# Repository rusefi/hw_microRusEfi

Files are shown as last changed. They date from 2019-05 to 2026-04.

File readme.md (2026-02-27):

# microRusEFI

microRusEFI is a small & cheap engine management system board designed for fully sequential 1, 2, 3 and 4 cylinder applications.

6 and 8 cylinders are possible with some limitations. 5 cylinder application not recommended. You would need at least two microRusEFI units to run a v12.

microRusEFI uses a waterproof connector and its aluminum enclosure could be sealed. 

microRusEFI hardware runs [rusEFI firmware](https://github.com/rusefi/rusefi).

microRusEfi supports dual Hall shaft position sensor input or 1xHall + 1xVR shaft position sensor input
(A few resistors must be replaced on the PCB in order to switch from one setup to another)

Open source design available in this repository,
or available as a kit or completely assembled from http://shop.rusefi.com/

# Capabilities
* Primary VR or Hall input (configurable with few resistor changes)
* Secondary Hall input
* x4 analog thermistor (temperature) inputs
* x10 analog voltage inputs (0-5v)
* x4 high-Z injector outputs
* x2 high-current low side outputs for IAC/VVT/other solenoids
* Dedicated main relay control output 
* x4 low-current low side outputs for relays or warning lights 
* x4 5v logic-level ignition outputs
* x2 5v/12v configurable logic level outputs (requires resistor changes)
* Electronic throttle body (drive by wire)
* CAN connectivity on the plug
* USB connectivity on the plug 
* SPI and TTL available on PCB
* stepper IAC support (beta testing please report your results!)

# Documentation

[Connector Pinout](https://github.com/rusefi/rusefi/wiki/Hardware-microRusEfi-wiring)

[microRusEFI documentation wiki](https://github.com/rusefi/rusefi/wiki/Hardware-microRusEfi)

[microRusEFI kit instructions](https://github.com/rusefi/rusefi/wiki/Hardware-microRusEfi-kit-instructions)

[microRusEFI forum thread](https://rusefi.com/forum/viewtopic.php?f=4&t=1538)

[asembled images & assembly files](gerbers)

[ChangeLog](releaseNotes.md)

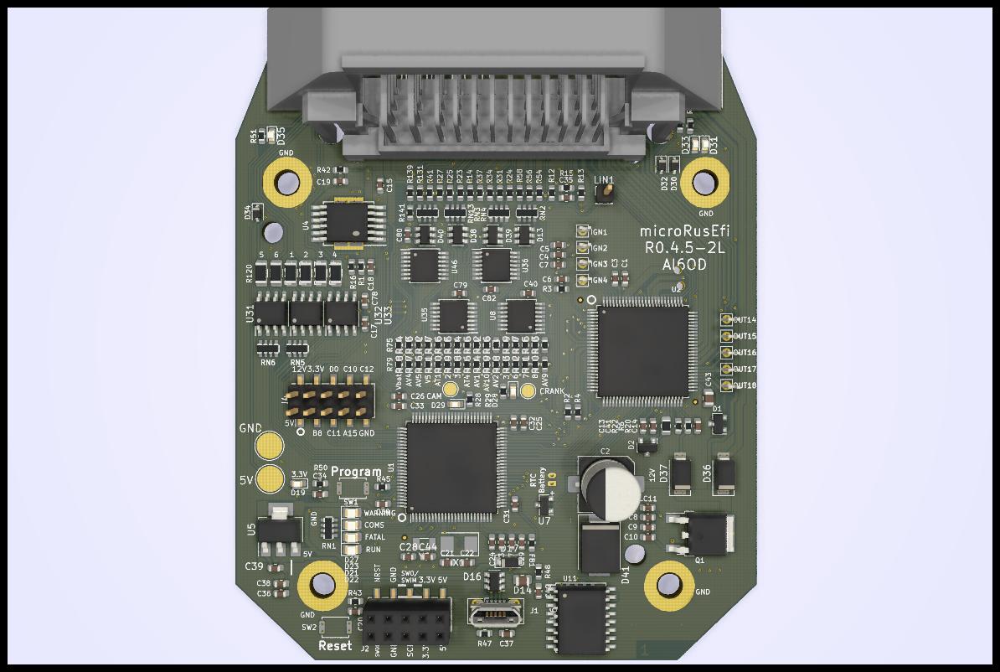
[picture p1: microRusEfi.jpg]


If you download complete repo do not forget to download libraries. If you git clone be sure to also

`git submodule update --init`

Do you like what you see here? Maybe https://www.patreon.com/rusefi

## BOM highlights

stm32f767

[TLE8888-2QK](https://www.infineon.com/dgdl/Infineon-Infineon-TLE8888QK-DS-v01_02-EN.pdf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)

[Final assembly BOM notes](https://github.com/rusefi/hw_microRusEfi/blob/master/gerbers/rusEFI-Micro_R0.4.x-not-pre-assembled.md)

[48 pin connector](https://github.com/rusefi/rusefi/wiki/Hardware-microRusEfi-connectors)

[iBom 0.6.0](https://rusefi.com/docs/ibom/micro_rusEFI_R0.6.0.html)

## Adapter Boards

microRusEFI could be used as a brain for Plug&Play vehicle specific adapter boards

1) https://github.com/rusefi/hw_55_te For Yanvar/Micas case

## Case

Model CKKB48-1-A (Weigh 200g)

[Case 3D Model](https://cad.onshape.com/documents/cce953328a88b521d5673ac5/w/e2d3a78cfb432482f5aac9ea/e/2eb39a31ab72390c6384f68c)

Cover bolts M3.5x0.6

PCB bolts M3 0.5mm thread, L=7.5mm https://www.mcmaster.com/94209A619/

## Gerbers

[Gerbers and pictures of fabricated boards](gerbers)

## ST-LINK

Unfortunately eBay has a few different version of cheap ST-LINK V2 devices with different pinout. Here is the pinout rusEfi is compatible with:

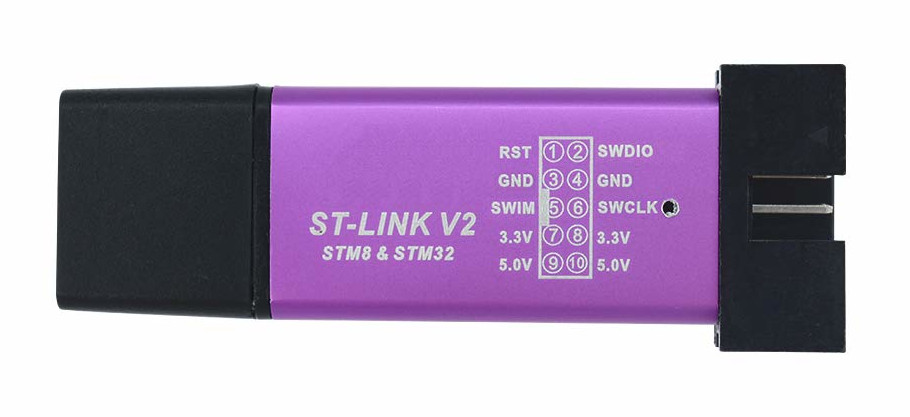
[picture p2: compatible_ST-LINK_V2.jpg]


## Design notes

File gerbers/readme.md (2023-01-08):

All microRusEFI boards are 81x94mm

Case outside dimensions are about 10x11cm (not including mounting tabs)

A panel of 9 boards is 267*300mm

rusEFI text fixture is 130x128

[Connector Pinout](https://github.com/rusefi/rusefi/wiki/Hardware_microRusEFI_wiring)

[microRusEFI documentation wiki](https://github.com/rusefi/rusefi/wiki/Hardware_microRusEFI)

[microRusEFI kit instructions](https://github.com/rusefi/rusefi/wiki/Hardware_microRusEFI_kit_instructions)

R0.1, R0.2, R03 - 4 layers, no assembly files

R0.4.5 - 2 layers, use microRusEfi-bom.csv and microRusEfi-cpl.csv files for top side assembly.

# R0.5.0




# R0.4.8



# R0.4.5

Pre-assembled by jlcpcb



More-assembled, based on pre-assembled by jlcpcb. 




##R0.3 Hall Mode Mazda Miata 2003


# R0.1


##R0.1 Hall Mode


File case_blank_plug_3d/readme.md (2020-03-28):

3D printed plug if one wants to use default aluminum case but not the default connector.

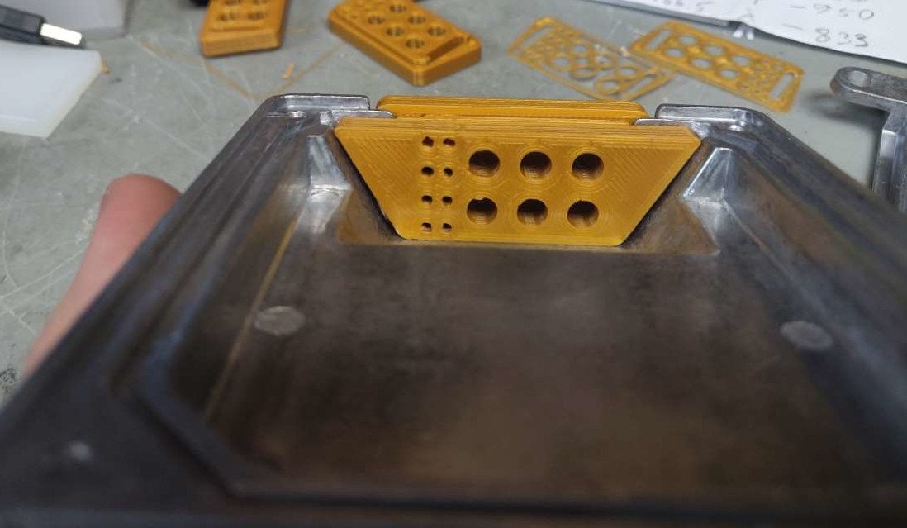
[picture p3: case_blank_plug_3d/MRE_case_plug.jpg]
i


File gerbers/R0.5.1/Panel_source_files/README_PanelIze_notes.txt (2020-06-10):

Steps for panelizing are as follows
-- Open C:\Program Files\KiCad\bin\pcbnew.exe or similar directly. This will allow the below step. 
-- Open Panel_MRE_R0.5.1_300x300_2layer_step0.kicad_pcb
-- Append MRE to this board, and place in the top left location of the layout. 
-- Copy MRE and Paste it 9 times. 
-- Make sure you have the green ECO1 lines for where the mousebits should be
-- SaveAs Panel_MRE_R0.5.1_300x300_2layer_step1.kicad_pcb
-- modify and run MouseBitePanel.bat
-- Open output.Panel_R0.5.1_300x300_2layer_step1.kicad_pcb
-- Delete extra mouse bits, add Vcut lines to ECO2 layer. 
-- plot gerbers the normal way, do NOT re-flood copper planes. 
-- geneate position file the normal way, save as "Panel_MRE_R0.5.1_300x300_1-to-9.csv"
-- use script to create the JLC CPL the normal way
-- Delete extra PCB's, then re-create positon file, and again "Panel_MRE_R0.5.1_300x300_1&5-populated_2,3,4,6,7,8,9-empty.csv"
-- use script to create the JLC CPL the normal way
-- SaveAS output.Panel_R0.5.1_300x300_2layer_step2.kicad_pcb
-- Move applicable files up one folder. 

The below notes are based off of EEVblog video found here https://www.youtube.com/watch?v=VXE_dh38HjU
-- 18:20 Check the PCB MFG house for max panel size, 
JLC is 300mm by 300mm for 1.6mm thick. https://support.jlcpcb.com/article/49-pcb-panelization
-- 18:30 Check the assembly house max panel size. 
JLC, I'll assume the 300mm by 300mm like above. Note MRE is 1 design 9 times. 
-- 19:37 tooling strips top an bottom or side to side should typicaly be about 10mm mininium. Check assembly house, but 10mm is typical.
JLC is 4mm tooling strip. Then here notes 3mm is min, they default to 5mm.  
-- 20:10 check tooling holes, typically 4mm diameter 4 holes, one in each corner. Also should have fiducials. 
JLC will add these if they are not provided. 
-- 22:00 Add bad board marker in the dead area's of the panel, so MFG can indicate a bad boarfd. 
-- 22:15 consider adding an impeadance test strips
-- 22:40 consider adding a test stack, AKA copper to the edge, so you can inspect the stackup of a 4 layer and above boards. 
-- 24:40 consider adding test points on the dead areas, handy for JTAG multi board programming. 
-- 42:00 create layer with v groove lines to show where to v groove. 
JLC needs 2mm min for internal cutouts. https://jlcpcb.com/capabilities/Capabilities
JLC V cut is 0.8mm wide, copper set back from v cut should be 0.4mm or more. 
-- 43:25 make sure your solder mask it around 4 mil or larger between pads, to prevent bridging. 
JLC allows 0.2mm (8 mils)
JLC mousebit hole diameter 0.8mm with 0.2 materail remaining. 
-- 48:35 suggested to provide a sample of a completed board, so the assembler knows what to do. At least provide pictures. 

As of 2020, this is one of the better tools for KICAD
https://hackaday.com/2020/04/25/kicad-panelization-made-easy/

Also this 2019 article. 
https://hackaday.com/2019/03/12/panelizing-boards-in-kicad/
https://gitlab.com/dren.dk/kicad-util

Basically open PCBNew manually and append the boards until you have them spaced, then add mouse bits, etc to get the panel made.

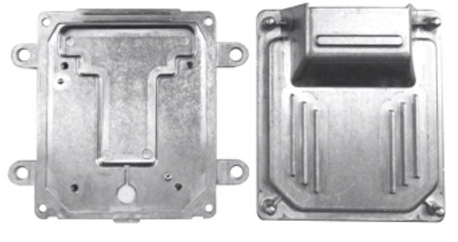
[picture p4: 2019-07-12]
CKKB48-1-A_both_sides.jpg

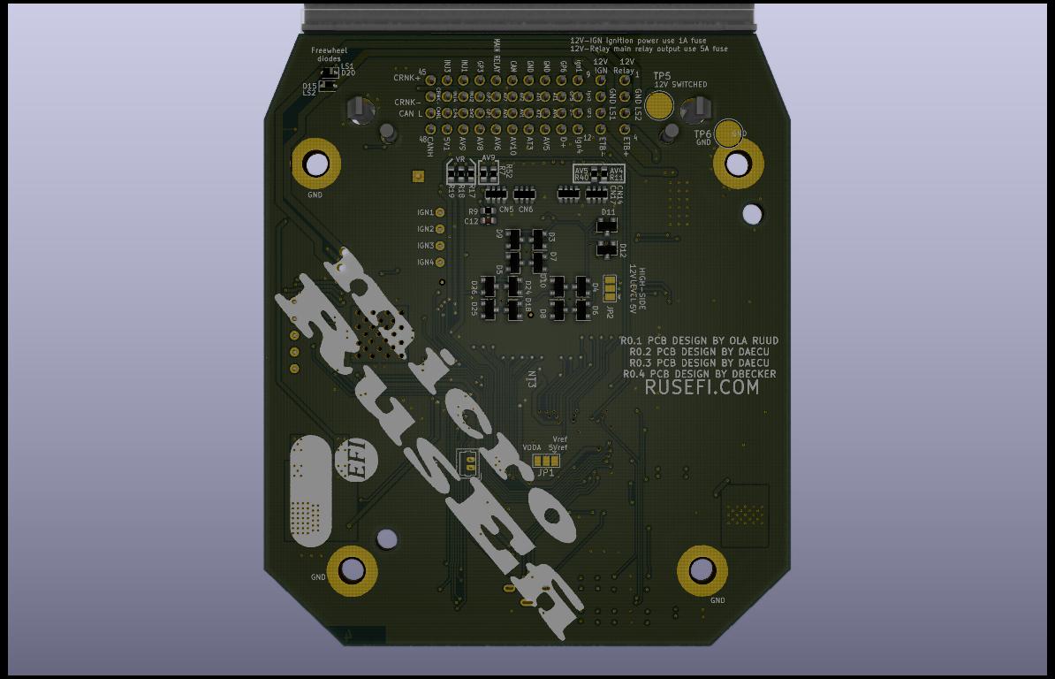
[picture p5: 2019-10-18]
micro_rusEFI_back.jpg

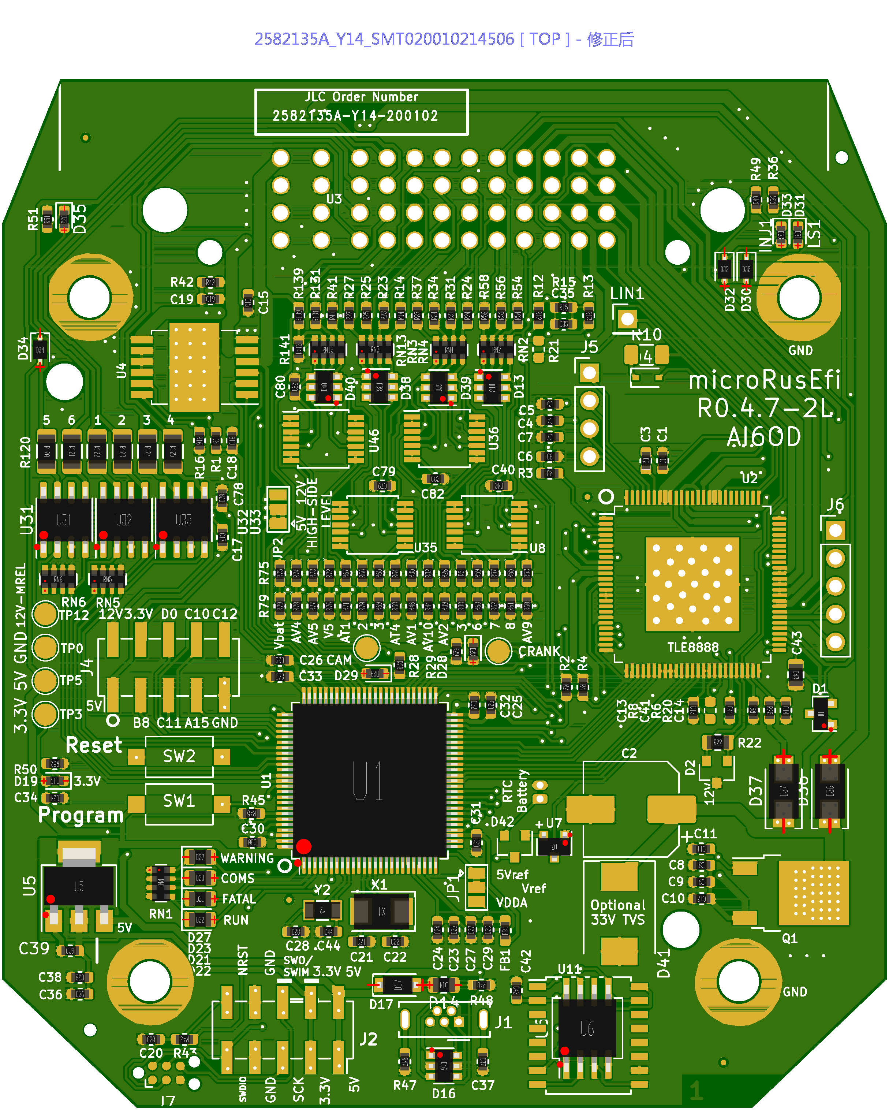
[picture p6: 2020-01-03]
gerbers/rusEFI-Micro_R0.4.7-polarity.png

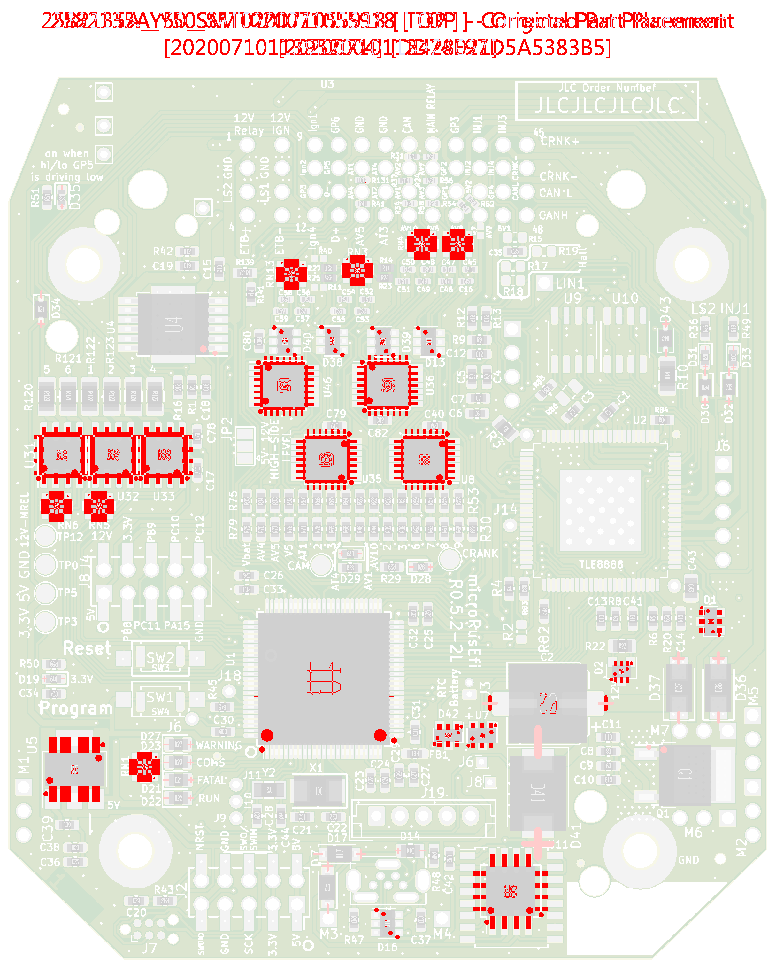
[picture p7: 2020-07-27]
gerbers/R0.5.2/placement_0.5.2.corrections.png

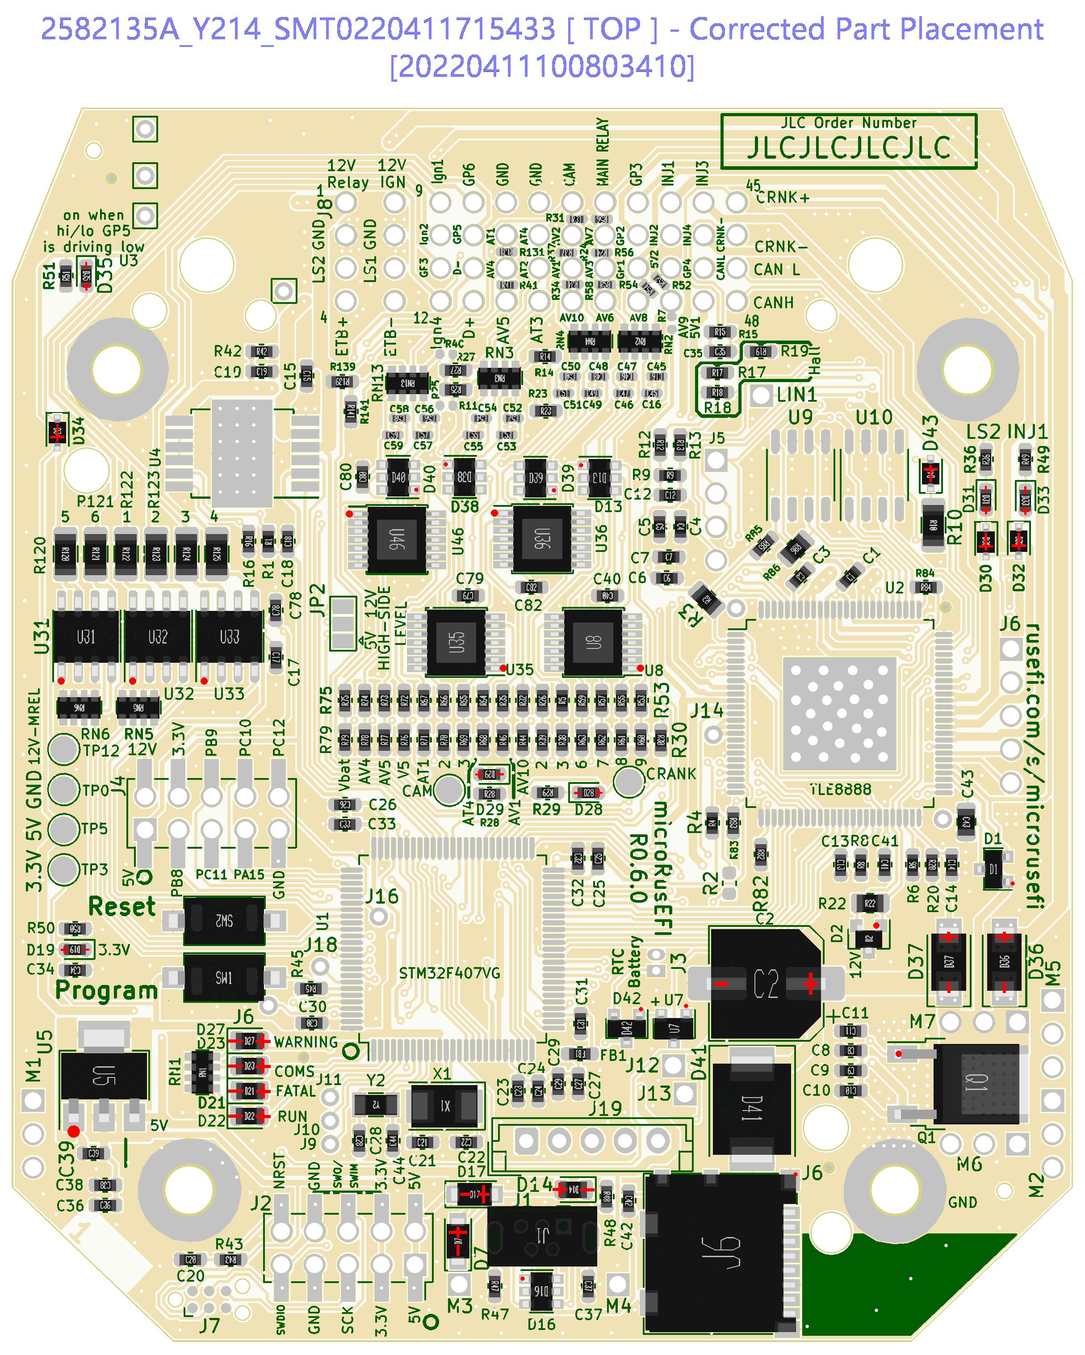
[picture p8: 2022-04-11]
gerbers/R0.6.0/Produce_DanZhi.SMT_Snapshot.Top.2582135A_Y214.SMT0220411715433.png

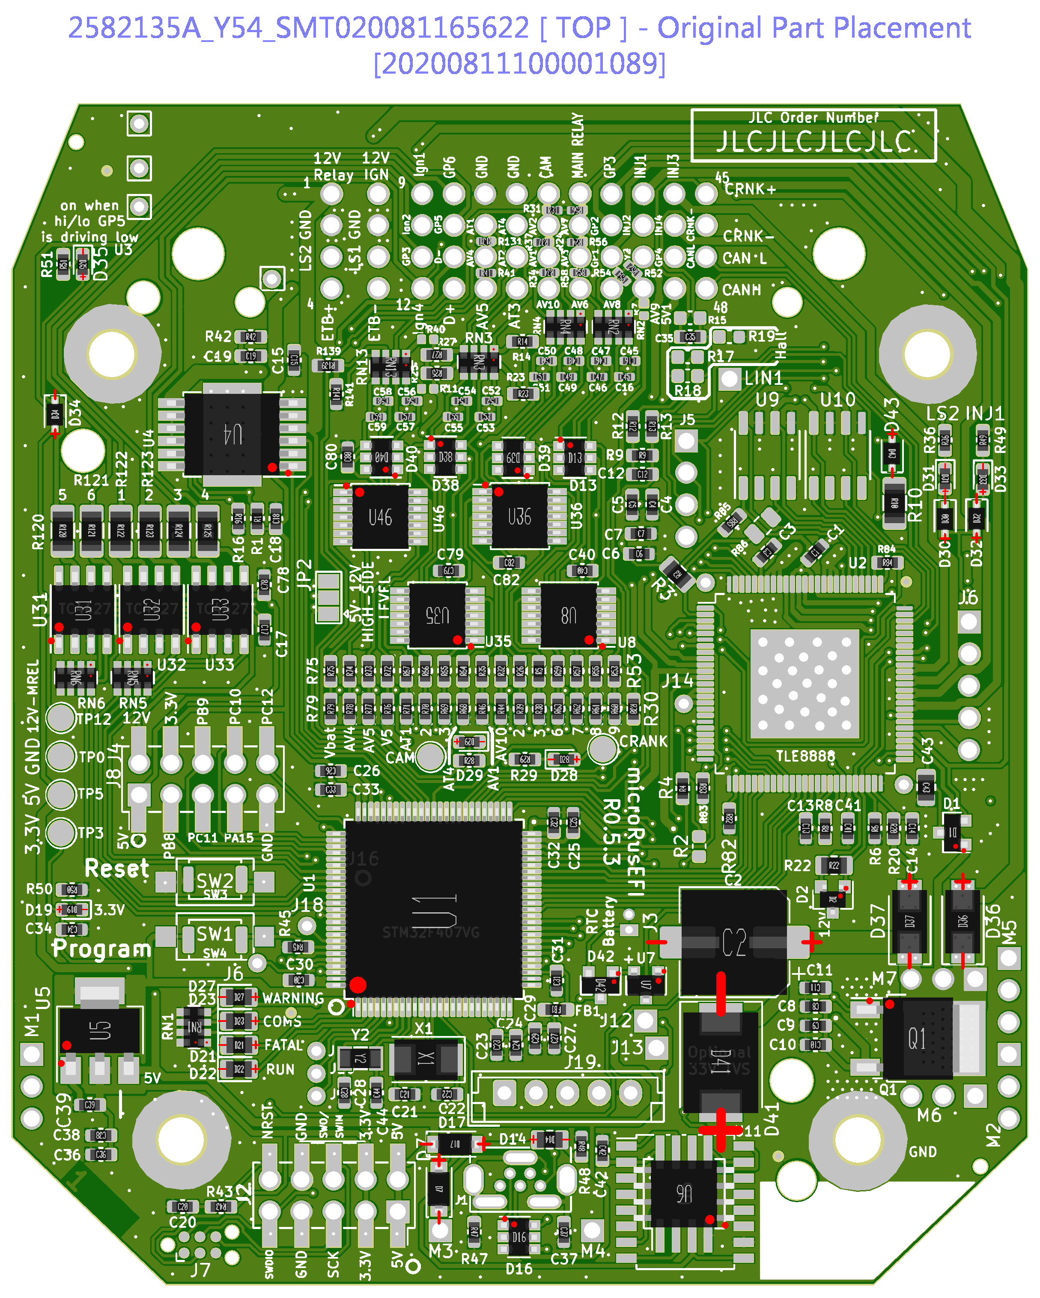
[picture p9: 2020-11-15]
gerbers/R0.5.3/placement_0.5.3.original.png

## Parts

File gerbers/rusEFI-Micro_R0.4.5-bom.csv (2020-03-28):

Comment | Designator | Footprint | LCSC Part #
100UF 50V Polarized capacitor | C2 | CP_Elec_8x10.5
4.7nF Unpolarized capacitor | C3,C11 | C_0603_1608Metric | C53987
470nF Unpolarized capacitor | C4,C5 | C_0603_1608Metric | C1623
10uF Unpolarized capacitor | C7,C9,C8 | C_0603_1608Metric | C19702
1nF Unpolarized capacitor | C12,C35 | C_0603_1608Metric | C1588
10nF Unpolarized capacitor | C19,C79,C80,C82,C40,C29,C20 | C_0603_1608Metric | C57112
18pF Unpolarized capacitor | C21,C22 | C_0603_1608Metric | C1647
2.2uF Unpolarized capacitor | C25,C26,C41 | C_0603_1608Metric | C23630
1uF Unpolarized capacitor | C27,C23,C36 | C_0603_1608Metric | C15849
6.8pF Unpolarized capacitor | C28,C44 | C_0603_1608Metric | C1679
22uF Unpolarized capacitor | C39 | C_0603_1608Metric | C59461
22uF 25V Unpolarized capacitor | C43 | C_0805_2012Metric | C45783
100nF Unpolarized capacitor | C78,C17,C15,C18,C38,C34,C33,C32,C31,C30,C37,C24,C42,C10,C1,C6,C13,C14 | C_0603_1608Metric | C14663
10nF 4 resistor network, parallel topology, DIP package | CN17,CN6,CN5,CN14 | R_Array_Convex_4x0603
BAV70 Dual 100V 215mA high-speed switching diodes, common cathode, SOT-23 | D1 | SOT-23 | C68978
PESD1CAN-UX | D2 | SOT-23
LED-GREEN Light emitting diode | D14 | C_0805_2012Metric | C2297
DNP Schottky diode | D15,D20 | D_SOD-323
B5819W Schottky diode | D17 | D_SOD-123 | C8598
LED-RED Light emitting diode | D21 | LED_0805_2012Metric | C84256
LED-GREEN Light emitting diode | D22 | LED_0805_2012Metric | C2297
LED-BLUE Light emitting diode | D23 | LED_0805_2012Metric | C2293
LED-YELLOW Light emitting diode | D27 | LED_0805_2012Metric | C2296
LED-RED Light emitting diode | D28,D31,D33,D35,D29,D19 | LED_0603_1608Metric | C2286
1N4148WS Diode | D32,D34,D30 | D_SOD-323 | C2128
SS54 40V 3A Schottky Barrier Rectifier Diode, SMC | D36,D37 | D_SMA | C22452
SRV05-4 Transient voltage suppressor designed to protect high speed data lines from ESD, EFT, and lightning | D38,D13,D40,D39,D16 | SOT-23-6 | C85364
SM15T33C Bidirectional transient-voltage-suppression diode | D41 | D_SMC
FILTER Ferrite bead | FB1 | R_0603_1608Metric_Pad1.05x0.95mm_HandSolder | C1034
Fiducial Fiducial Marker | FID5,FID6,FID1,FID2,FID3,FID4 | Fiducial_0.5mm_Mask1mm
IGNOUT test point | IGN3,IGN4,IGN2,IGN1 | Pin_D0.7mm_L6.5mm_W1.8mm_FlatFork
USB_B_Micro USB Micro Type B connector | J1 | USB_Micro-B_Molex-105133-0031
Conn_02x05_Odd_Even Generic connector, double row, 02x05, odd/even pin numbering scheme (row 1 odd numbers, row 2 even numbers), script generated (kicad-library-utils/schlib/autogen/connector/) | J2 | PinSocket_2x05_P2.54mm_Vertical_SMD
Conn_01x02 Generic connector, single row, 01x02, script generated (kicad-library-utils/schlib/autogen/connector/) | J3 | Molex_PicoBlade_53047-0210_1x02_P1.25mm_Vertical
Conn_02x05_Counter_Clockwise Generic connector, double row, 02x05, odd/even pin numbering scheme (row 1 odd numbers, row 2 even numbers), script generated (kicad-library-utils/schlib/autogen/connector/) | J4 | PinHeader_2x05_P2.54mm_Vertical_SMD
VRef Source 5Vsense VDDA 3-pole Solder Jumper, pins 1+2 closed/bridged | JP1 | SolderJumper-3_P1.3mm_Bridged12_Pad1.0x1.5mm
High side voltage 5V 12V 3-pole Solder Jumper, pins 1+2 closed/bridged | JP2 | SolderJumper-3_P1.3mm_Bridged2Bar12_Pad1.0x1.5mm
LIN test point | LIN1 | TestPoint_Pad_1.0x1.0mm
DNP Open Hardware logo, small | LOGO1 | LogoMRE
DNP | LOGO2 | LOGO
Net-Tie_2 Net tie, 2 pins | NT1 | Net-Tie_2_8.5mil
Net-Tie_2 Net tie, 2 pins | NT2 | Net-Tie_2_8.5mil
Analog Ground Net Tie Net tie, 2 pins | NT3 | NetTie-2_SMD_Pad0.5mm
OUT15 test point | OUT15 | Pin_D0.7mm_L6.5mm_W1.8mm_FlatFork
OUT16 test point | OUT16 | Pin_D0.7mm_L6.5mm_W1.8mm_FlatFork
OUT17 test point | OUT17 | Pin_D0.7mm_L6.5mm_W1.8mm_FlatFork
OUT18 test point | OUT18 | Pin_D0.7mm_L6.5mm_W1.8mm_FlatFork
IPD30N06S2L-23 30A Id, 50V Vds, N-Channel Power MOSFET, TO-220 | Q1 | TO-252-2
10K Resistor | R1,R16,R141,R46,R44,R39,R38,R60,R61,R62,R63,R68,R69,R70,R71,R76,R77,R78,R79,R43,R45,R12,R13,R3,R4,R2,R6 | R_0603_1608Metric | C25804
DNP Resistor | R11,R40,R7,R17,R19,R18 | R_0603_1608Metric
2.7k Resistor | R14,R23,R25,R27,R20 | R_0603_1608Metric | C13167
15k Resistor | R15 | R_0603_1608Metric | C22809
120 Resistor | R22 | R_0805_2012Metric | C17437
2.2k Resistor | R28 | R_0603_1608Metric | C4190
1k Resistor | R29,R49,R36,R51,R48,R50 | R_0603_1608Metric | C21190
6.8K Resistor | R35,R32,R26,R5,R55,R57,R59,R53,R64,R65,R66,R67,R73,R72,R74,R75 | R_0603_1608Metric | C23212
4.7K Resistor | R42,R9 | R_0603_1608Metric | C23162
100K Resistor | R47 | R_0603_1608Metric | C25803
100 Resistor | R120,R121,R122,R124,R125,R123 | R_1206_3216Metric | C17901
470K Resistor | R131,R41,R34,R31,R24,R37,R56,R54,R52,R58 | R_0603_1608Metric | C23178
39k Resistor | R139 | R_0603_1608Metric | C23153
1k 4 resistor network, parallel topology, DIP package | RN1 | R_Array_Convex_4x0603 | C20197
10k 4 resistor network, parallel topology, DIP package | RN5,RN6,RN3,RN13,RN4,RN2 | R_Array_Convex_4x0603 | C29718
SW_Push Push button switch, generic, two pins | SW1,SW2 | SW_Push_SPST_NO_Alps_SKRK
5V test point | TP1,TP5 | TestPoint_Pad_D4.0mm
GND test point | TP2,TP6 | TestPoint_Pad_D4.0mm
TP test point | TP4,TP3 | TestPoint_Pad_D2.0mm
STM32F407VGT6 ARM Cortex-M4 MCU, 1024KB flash, 128KB RAM, 168MHz, 1.8-3.6V, 82 GPIO, LQFP-100 | U1 | LQFP-100_14x14mm_P0.5mm | C12345
TLE8888QK | U2 | LQFP-100_14x14mm_P0.5mm_THERMAL
Molex_48_pin | U3 | Molex_48
TLE9201SG | U4 | Infineon_PG-DSO-12-11
LM1117-3.3 800mA Low-Dropout Linear Regulator, 3.3V fixed output, TO-220/TO-252/TO-263/SOT-223 | U5 | SOT-223-3_TabPin2 | C6186
W25QxxJVS 32Mb Serial Flash Memory, Standard/Dual/Quad SPI, SOIC-8 | U6 | SO-8_5.3x6.2mm_P1.27mm-150+208 | C97521
XC6206 3.3V Low Quiescent Current LDO Regulator, 3.3V, 250mA, Vin<=16V, SOT-23 | U7 | SOT-23 | C5446
IS25LP256D-xM 256-Mbit, 1.8V SPI Serial Flash Memory with Dual-I/O and Quad-I/O Support, SOIC-16 | U11 | SOIC-16W_7.5x10.3mm_P1.27mm
MIC4427 Dual 1.5A-Peak Low-Side MOSFET Driver, DIP-8/SOIC-8/MSOP-8 | U31,U33,U32 | SOIC-8_3.9x4.9mm_P1.27mm | C144205
MCP6004 1MHz, Low-Power Op Amp, DIP-14/SOIC-14/TSSOP-14 | U35,U36,U46,U8 | TSSOP-14_4.4x5mm_P0.65mm | C50282
8MHz Two pin crystal | X1 | Crystal_SMD_5032-2Pin_5.0x3.2mm | C115962
32768 Hz Two pin crystal, small symbol | Y2 | Crystal_SMD_3215-2Pin_3.2x1.5mm | C32346

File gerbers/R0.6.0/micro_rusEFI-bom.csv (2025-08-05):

Comment | Designator | Footprint | LCSC
1nF | C12,C35 | Capacitor_SMD:C_0603_1608Metric | C1588
100nF | C16,C45,C46,C47,C48,C49,C50,C51,C52,C53,C54,C55,C56,C57,C58,C59 | Capacitor_SMD:C_0402_1005Metric | C1525
100UF 50V | C2 | Capacitor_SMD:CP_Elec_8x10.5 | C134515
18pF | C21,C22 | Capacitor_SMD:C_0603_1608Metric | C1647
1uF | C23,C27,C36 | Capacitor_SMD:C_0603_1608Metric | C15849
2.2uF | C25,C26,C41 | Capacitor_SMD:C_0603_1608Metric | C23630
6.8pF | C28,C44 | Capacitor_SMD:C_0603_1608Metric | C1679
4.7nF | C3,C11 | Capacitor_SMD:C_0603_1608Metric | C53987
22uF | C39 | Capacitor_SMD:C_0603_1608Metric | C59461
470nF | C4,C5 | Capacitor_SMD:C_0603_1608Metric | C1623
10nF | C19,C20,C29,C40,C79,C80,C82 | Capacitor_SMD:C_0603_1608Metric | C57112
100nF | C1,C6,C10,C13,C14,C15,C17,C18,C24,C30,C31,C32,C33,C34,C37,C38,C42,C78 | Capacitor_SMD:C_0603_1608Metric | C14663
22uF 25V | C43 | Capacitor_SMD:C_0805_2012Metric | C45783
10uF | C7,C8,C9 | Capacitor_SMD:C_0603_1608Metric | C19702
SRV05-4 | D13,D16,D38,D39,D40 | Package_TO_SOT_SMD:SOT-23-6 | C85364
PESD1CAN-UX | D2 | Package_TO_SOT_SMD:SOT-23 | C152727
LED-RED | D21 | LED_SMD:LED_0805_2012Metric | C84256
LED-GREEN | D14,D22 | LED_SMD:LED_0805_2012Metric | C2297
LED-BLUE | D23 | LED_SMD:LED_0805_2012Metric | C2293
LED-YELLOW | D27 | LED_SMD:LED_0805_2012Metric | C2296
LED-RED | D19,D28,D29,D31,D33,D35 | LED_SMD:LED_0603_1608Metric | C2286
SS54 | D3,D4,D5,D6,D15,D20,D36,D37 | Diode_SMD:D_SMA | C22452
1N4148WS | D30,D32,D34,D43 | Diode_SMD:D_SOD-323 | C2128
SM15T33C | D41 | Diode_SMD:D_SMC | C133707
BAV70 | D1,D42 | Package_TO_SOT_SMD:SOT-23 | C82479
B5819W | D7,D17 | Diode_SMD:D_SOD-123 | C8598
FILTER | FB1 | Resistor_SMD:R_0603_1608Metric_Pad1.05x0.95mm_HandSolder | C1034
Fiducial | FID1,FID2,FID3,FID4,FID5,FID6 | Fiducial:Fiducial_0.5mm_Mask1mm
USB_B_Mini | J1 | hellen-one-common:USB-MINI-B-VERTICAL | C13453
Conn_01x06 | J19 | Connector_JST:JST_EH_B5B-EH-A_1x05_P2.50mm_Vertical
Conn_02x05_Odd_Even | J2 | Connector_PinSocket_2.54mm:PinSocket_2x05_P2.54mm_Vertical_SMD
Conn_01x01 | J3,J5,J12,J13,J15,J17 | Connector_Pin:Pin_D0.7mm_L6.5mm_W1.8mm_FlatFork
Conn_02x05_Counter_Clockwise | J4 | Connector_PinHeader_2.54mm:PinHeader_2x05_P2.54mm_Vertical_SMD
Micro_SD_Card_Det | J6 | Connector_Card:microSD_HC_Molex_104031-0811 | C585350
TC2030 | J7 | Connector:Tag-Connect_TC2030-IDC-NL_2x03_P1.27mm_Vertical
High side voltage 5V 12V | JP2 | Jumper:SolderJumper-3_P1.3mm_Open_Pad1.0x1.5mm
DNP | LOGO1 | Symbol:OSHW-Logo2_7.3x6mm_SilkScreen
DNP | LOGO2 | rusEFI:LOGO
LOGO | LOGO3 | rusefi_lib:MRE_QR_code
Net-Tie_2 | NT1 | rusEFI_Ola:Net-Tie_2_8.5mil
Net-Tie_2 | NT2 | hw_microRusEfi-master:Net-Tie_2_8.5mil
Analog Ground Net Tie | NT3 | NetTie:NetTie-2_SMD_Pad0.5mm
IPD30N06S2L-23 | Q1 | Package_TO_SOT_SMD:TO-252-2 | C3010
1k | R10 | Resistor_SMD:R_1206_3216Metric | C4410
100 | R120,R121,R122,R123,R124,R125 | Resistor_SMD:R_1206_3216Metric | C17901
39k | R139 | Resistor_SMD:R_0603_1608Metric | C23153
2.7k | R14,R20,R23,R25,R27 | Resistor_SMD:R_0603_1608Metric | C13167
15k | R15 | Resistor_SMD:R_0603_1608Metric | DNP
DNP | R17,R18,R19 | Resistor_SMD:R_0603_1608Metric
0R DNP | R2 | Resistor_SMD:R_0603_1608Metric
0R | R8,R21,R30,R33,R80,R81,R84,R85 | Resistor_SMD:R_0603_1608Metric | C21189
120 | R22 | Resistor_SMD:R_0805_2012Metric | C17437
470K | R24,R31,R34,R37,R41,R52,R54,R56,R58,R131 | Resistor_SMD:R_0402_1005Metric | C25790
2.2k | R28,R48 | Resistor_SMD:R_0603_1608Metric | C4190
1k | R29,R36,R49,R50,R51 | Resistor_SMD:R_0603_1608Metric | C21190
10K | R3 | Resistor_SMD:R_0805_2012Metric | C17414
10K | R1,R4,R6,R12,R13,R16,R38,R39,R43,R44,R45,R46,R60,R61,R62,R63,R68,R69,R70,R71,R76,R77,R78,R79,R141 | Resistor_SMD:R_0603_1608Metric | C25804
4.7K | R9,R42,R82,R83 | Resistor_SMD:R_0603_1608Metric | C23162
100K | R47 | Resistor_SMD:R_0603_1608Metric | C25803
6.8K | R5,R26,R32,R35,R53,R55,R57,R59,R64,R65,R66,R67,R72,R73,R74,R75 | Resistor_SMD:R_0603_1608Metric | C23212
DNP | R7,R11,R40 | Resistor_SMD:R_0402_1005Metric
0R | R86 | Resistor_SMD:R_0805_2012Metric
1k | RN1 | Resistor_SMD:R_Array_Convex_4x0603 | C20197
10k | RN2,RN3,RN4,RN5,RN6,RN13 | Resistor_SMD:R_Array_Convex_4x0603 | C29718
SW_Push | SW1,SW2 | Button_Switch_SMD:SW_SPST_CK_RS282G05A3 | C398054
SW_Push | SW3,SW4 | Button_Switch_SMD:SW_Push_SPST_NO_Alps_SKRK
GND | TP0,TP3 | TestPoint:TestPoint_Pad_D2.0mm
TP | TP1,TP2,TP4 | TestPoint:TestPoint_Pad_D2.0mm
5V | TP5,TP12 | TestPoint:TestPoint_Pad_D2.0mm
STM32F427VGT6 | U1 | Package_QFP:LQFP-100_14x14mm_P0.5mm | C117815
TLE8888QK | U2 | Package_QFP:LQFP-100_14x14mm_P0.5mm_THERMAL
molex_48pin_MRE | U3 | rusefi_lib:Molex_48_MRE
MIC4427 | U31,U32,U33 | Package_SO:SOIC-8_3.9x4.9mm_P1.27mm | C144205
TLE9201SG | U4 | Package_SO:Infineon_PG-DSO-12-11 | C112633
LM1117-3.3 | U5 | Package_TO_SOT_SMD:SOT-223-3_TabPin2 | C6186
XC6206 3.3V | U7 | Package_TO_SOT_SMD:SOT-23 | C5446
MCP6004 | U8,U35,U36,U46 | Package_SO:TSSOP-14_4.4x5mm_P0.65mm | C248577
VNLD5090 | U9,U10 | Package_SO:SO-8_3.9x4.9mm_P1.27mm | C377942
8MHz 20pF | X1 | Crystal:Crystal_SMD_5032-2Pin_5.0x3.2mm | C115962
32768 Hz | Y2 | Crystal:Crystal_SMD_3215-2Pin_3.2x1.5mm | C32346

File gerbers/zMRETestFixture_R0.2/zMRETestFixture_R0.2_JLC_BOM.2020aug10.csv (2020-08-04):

Comment | Designator | Footprint | LCSC | Manufacturer | Part # | VEND | VEND# | LCSC | Digi
YEL(570NM) | D10 | rusefi_lib:SM0805_jumper |  |  |  |  |  | C84257
BLU | D12,D14,D16,D18,D20,D22 | rusefi_lib:SM0805_jumper |  |  |  |  |  | C375453
RED | D31,D33,D35,D37,D39,D41,D43,D45,D47,D25,D27,D29,D81,D83,D85,D87,D89,D91,D93,D96,D23 | rusefi_lib:SM0805_jumper |  |  |  |  |  | C84256
1N4148WS | D32,D95,D34,D36,D38,D40,D42,D44,D46,D11,D13,D15,D17,D19,D21,D5,D7,D9,D48,D26,D28,D30,D52,D82,D84,D86,D88,D90,D92,D51,D50,D49,D56,D55,D54,D53,D60,D59,D58,D57,D64,D63,D62,D61,D94,D97,D24,D3,D1 | rusefi_lib:SM0805_jumper |  |  |  |  |  | C2128
GRN | D6,D68,D67,D66,D65,D72,D71,D70,D69,D76,D75,D74,D73,D80,D79,D78,D77,D4,D2 | rusefi_lib:SM0805_jumper |  |  |  |  |  | C2297
YEL(593NM) | D8 | rusefi_lib:SM0805_jumper |  |  |  |  |  | C2296
1A FUSE | F1 | rusefi_lib:Blank |  |  |  |  |  |  | 283-3731-ND
Conn_01x01 | J1,J2,J5,J6,J8,J7,J11,J10 | Connector_Pin:Pin_D0.7mm_L6.5mm_W1.8mm_FlatFork
Conn_01x01_Female | J3,J4 | rusefi_lib:KeyStone_3557 |  |  |  |  |  |  | 36-3557-ND
Conn_02x05_Counter_Clockwise | J9 | Connector_PinHeader_2.54mm:PinHeader_2x05_P2.54mm_Vertical_SMD
DNP | LOGO1 | rusEFI:LOGO |  | DNP | DNP | DNP | DNP
DNP | LOGO2 | Symbol:OSHW-Logo2_7.3x6mm_SilkScreen |  | DNP | DNP | DNP | DNP
LOGO | LOGO3 | rusefi_lib:MRE_QR_code
2k2 | R14,R26,R32 | rusefi_lib:SM0805_jumper |  |  |  |  |  | C17520
3k3 | R15,R30 | rusefi_lib:SM0805_jumper |  |  |  |  |  | C26010
4k7 | R18,R39 | rusefi_lib:SM0805_jumper |  |  |  |  |  | C17673
10k | R29,R25,R19 | rusefi_lib:SM0805_jumper |  |  |  |  |  | C17414
0R | R3 | rusefi_lib:SM0805_jumper |  |  |  |  |  | C17477
5k | R42,R40,R44,R46,R50,R48,R52,R54,R38,R4,R5,R6,R22,R56,R28,R34,R78,R31,R23,R80,R82,R84,R86,R88,R91,R93,R17 | rusefi_lib:SM0805_jumper |  |  |  |  |  | C17677
1k | R90,R37,R41,R43,R45,R47,R49,R51,R53,R7,R8,R9,R10,R13,R11,R12,R55,R21,R27,R33,R64,R77,R20,R24,R79,R81,R83,R85,R87,R63,R62,R61,R68,R67,R66,R65,R72,R71,R70,R69,R76,R75,R74,R73,R89,R92,R16,R1,R2 | rusefi_lib:SM0805_jumper |  |  |  |  |  | C17513
SW_Push | SW1,SW2 | Button_Switch_SMD:SW_SPST_B3SL-1002P |  |  |  |  |  | C318887
5V | TP1,TP3 | TestPoint:TestPoint_Pad_D2.0mm |  | DNP | DNP | DNP | DNP
GND | TP2,TP4 | TestPoint:TestPoint_Pad_D2.0mm |  | DNP | DNP | DNP | DNP
molex_48pin_MRE | U1 | rusefi_lib:Molex_48_MRE |  | MOLEX | 500762-0481 | DIGI | WM4430-ND

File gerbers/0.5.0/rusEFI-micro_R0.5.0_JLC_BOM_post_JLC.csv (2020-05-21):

Comment | Designator | Footprint | LCSC | Manufacturer | Part # | VEND | VEND# | LCSC | MFG | MFG# | Vend1 | Vend1# | PageName
10nF" | CN17,CN6,CN5,CN14 | Resistor_SMD:R_Array_Convex_4x0603 |  | KEMET | CA064X103K2RACAUTO | DIGI | 399-12382-1-ND
USB_B_Micro | J1 | Connector_USB:USB_Micro-B_Wuerth_614105150721_Vertical |  | GCT | USB3131-30-0230-A
SW_Push | SW2,SW1 | Button_Switch_SMD:SW_SPST_CK_RS282G05A3 |  |  |  |  |  | C398054
VNLD5090 | U10,U9 | Package_SO:SO-8_3.9x4.9mm_P1.27mm |  |  |  |  |  | C377942 | ST,VNLD5090TR-E | DIGI,497-14323-1-ND
TLE88882QK | U2 | Package_QFP:LQFP-100_14x14mm_P0.5mm_THERMAL |  | Infineon | TLE88882QKXUMA1 | DIGI | TLE88882QKXUMA1-ND

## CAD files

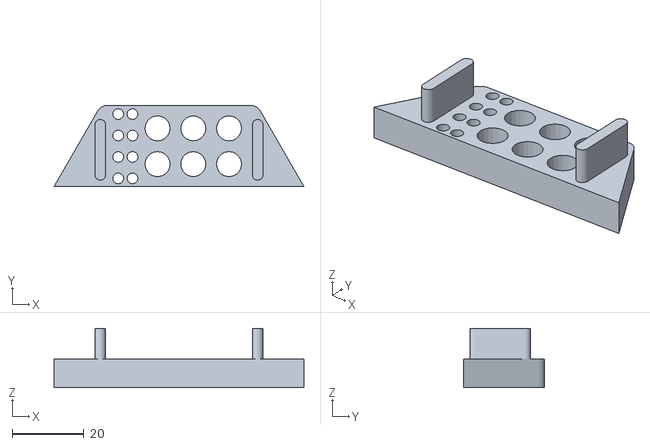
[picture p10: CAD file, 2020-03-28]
case_blank_plug_3d/MRE_case_plug_blank_rear.stl
69.9 x 22.7 x 16.5

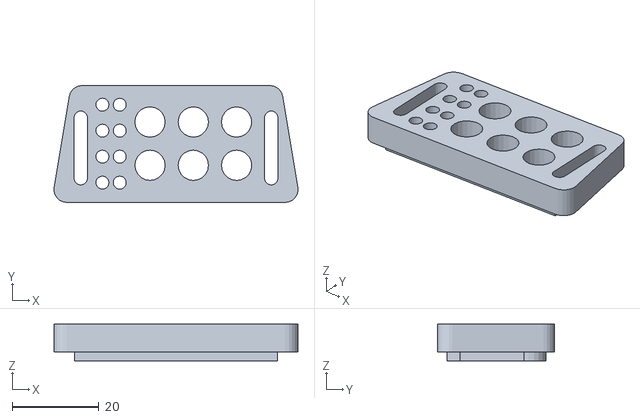
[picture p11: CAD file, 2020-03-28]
case_blank_plug_3d/MRE_case_plug_blank_front.stl
56.4 x 27.0 x 8.50

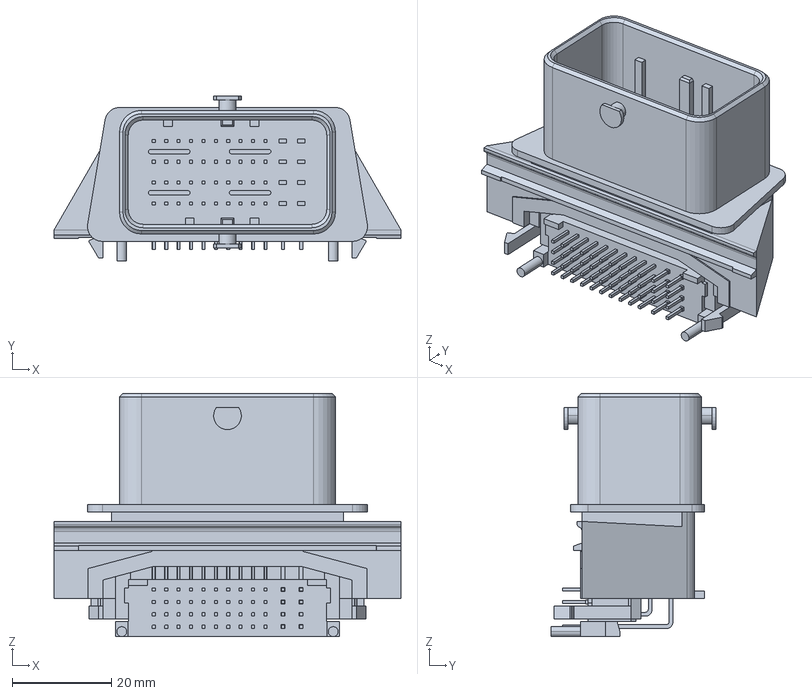
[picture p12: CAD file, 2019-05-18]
rusefi_lib/3d/5007620481.stp
69.9 x 33.2 x 49.0 mm

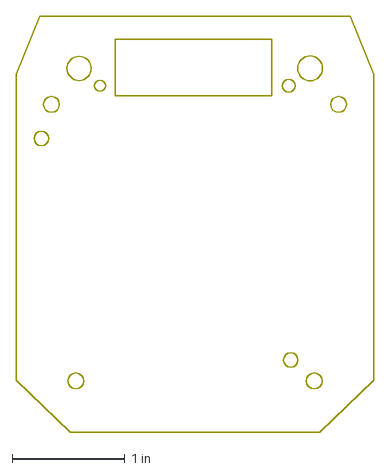
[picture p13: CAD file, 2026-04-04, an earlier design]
gerbers/Archived/rusEFI-Micro_R0.4.7-Spacer_Cuts.dxf
3.17 x 3.69 in

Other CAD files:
case_model_3d.x_t

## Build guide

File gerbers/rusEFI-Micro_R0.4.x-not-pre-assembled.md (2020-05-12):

# Not pre-assembled BOM:

1,TLE88882QK ,U2,LQFP-100_14x14mm_P0.5mm_THERMAL,TLE88882QKXUMA1

1,614105150721

newark/digikey USB3131-30-0230-A is a cheaper vertical USB with better length contacts

2,PTS636 SM43 SMTR LFS

4,CA064X103K2RACAUTO

SO-8 drivers:
VNLD5090
90 mOhm / 18A

VNLD5160
160 mOhm / 3.5 A

VNLD5300
300 mOhm / 2A

#Front side

Open question if anyone needs those:

TODO add to BOM and CPL: LIN termination D43 R10

TODO add to BOM and CPL: RTC diode D42

Wake-up CAN R8

Alternatives for C50282 op-amp: C248577

[below 0.4.8 only] 100UF 50V Polarized capacitor,C2,CP_Elec_8x10.5,
[below 0.4.8 only] "IPD30N06S2L-23 30A Id, 50V Vds, N-Channel Power MOSFET, TO-220",Q1,TO-252-2,726-IPD30N06S2L23AT3
[below 0.4.8 only] TLE9201SG ,U4,Infineon_PG-DSO-12-11,726-TLE9201SGAUMA1

PESD1CAN-UX ,D2,SOT-23,771-PESD1CANUX,C152727

[0.4.5 and below]  USB_B_Micro USB Micro Type B connector,J1,USB_Micro-B_Molex-105133-0031,
[0.4.7 and above]: USB Type B Vertical 614105150721 Wurth Elektronik,J1,USB_Micro,710-614105150721

"Conn_02x05_Counter_Clockwise Generic connector, double row, 02x05, odd/even pin numbering scheme (row 1 odd numbers, row 2 even numbers), script generated (kicad-library-utils/schlib/autogen/connector/)",J4,PinHeader_2x05_P2.54mm_Vertical_SMD,

"SW_Push Push button switch, generic, two pins","SW1,SW2",SW_Push_SPST_NO_Alps_SKRK,
3*6*2.5 MM Tactile Tact Push Button Micro Switch Momentary Two Pin

Molex_48_pin ,U3,Molex_48,

#Back side

0.4.x: Schottky diode,"D15,D20",SMA,C22452

D15&D20 Alternative part: SS16T3G

"10nF 4 resistor network, parallel topology, DIP package","CN17,CN6,CN5,CN14",R_Array_Convex_4x0603,

[below 0.4.8 only] 4.7K Resistor,"R9",R_0603_1608Metric,C23162

[below 0.4.8 only] 1nF Unpolarized capacitor,"C12",C_0603_1608Metric,C1588

# Flash chip
W25Q128JV

W25Q128JW soic16 option

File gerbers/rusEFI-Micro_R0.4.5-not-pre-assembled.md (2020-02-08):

#Front side

TODO 0.4.7 add to BOM and CPL: LIN termination D43 R10
TODO 0.4.7 add to BOM and CPL: RTC diode D42

Alternatives for C50282 op-amp: C248577

100UF 50V Polarized capacitor,C2,CP_Elec_8x10.5,

"IPD30N06S2L-23 30A Id, 50V Vds, N-Channel Power MOSFET, TO-220",Q1,TO-252-2,726-IPD30N06S2L23AT3

PESD1CAN-UX ,D2,SOT-23,771-PESD1CANUX,C152727

0.4.5: USB_B_Micro USB Micro Type B connector,J1,USB_Micro-B_Molex-105133-0031,
0.4.7: USB Type B Vertical 614105150721 Wurth Elektronik,J1,USB_Micro,710-614105150721

"Conn_02x05_Counter_Clockwise Generic connector, double row, 02x05, odd/even pin numbering scheme (row 1 odd numbers, row 2 even numbers), script generated (kicad-library-utils/schlib/autogen/connector/)",J4,PinHeader_2x05_P2.54mm_Vertical_SMD,

"SW_Push Push button switch, generic, two pins","SW1,SW2",SW_Push_SPST_NO_Alps_SKRK,
3*6*2.5 MM Tactile Tact Push Button Micro Switch Momentary Two Pin

TLE9201SG ,U4,Infineon_PG-DSO-12-11,726-TLE9201SGAUMA1

TLE8888QK ,U2,LQFP-100_14x14mm_P0.5mm_THERMAL,726-TLE8888QKXUMA1

Molex_48_pin ,U3,Molex_48,

#Back side

0.4.5: DNP Schottky diode,"D15,D20",D_SOD-323,
0.4.7: chottky diode,"D15,D20",SMA,C22452

"10nF 4 resistor network, parallel topology, DIP package","CN17,CN6,CN5,CN14",R_Array_Convex_4x0603,

BAS70-04 40V 0.2A Dual Small Signal Schottky Diodes,"D10,D8,D6,D4,D9,D7,D5,D3,D12,D11,D26,D25,D24,D18",SOT-23,
C150242?

4.7K Resistor,"R9",R_0603_1608Metric,C23162

1nF Unpolarized capacitor,"C12",C_0603_1608Metric,C1588

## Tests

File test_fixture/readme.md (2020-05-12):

microRusEFI test fixture board allows one to test his microRusEFI basic soldering by having an LED for each of MRE 48 + GPIO (J2/J4/J9 etc) pins.

GREEN test fixture board LEDs are POWER.

RED test fixture board LEDs are low-side.

BLUE test fixture board LEDs are high-side.

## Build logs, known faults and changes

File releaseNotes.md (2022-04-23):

# 0.6.1

improved VR silkscreen

# 0.6.0

flash chip replaced with SD card holder

minimal silkscreen improvements

migrated to KiCAD 6

# 0.5.4

0.5.4 is 0.5.3 with "rusefi.com/s/microrusefi" text on top layer 

# 0.5.3

Traces clean-up to reduce chances of botched fabrication 

# 0.5.2

https://github.com/rusefi/hw_microRusEfi/issues/165 progress miniUSB option
https://github.com/rusefi/hw_microRusEfi/issues/180 improvement for SD+BT wiring (SPI Flash pinout was changed to accomodate but no one uses SPI Flash anyway)
https://github.com/rusefi/hw_microRusEfi/issues/184 BOM issue wrong size of 2.7K resistors

# 0.5.1
TBD, in the works!
Added J19 the optional USB bulk head connector. 

Some passives are now 0402 in order to move stuff from the back side of the board.

Analog input RC filter changed from 10nF to 100nF.

https://github.com/rusefi/hw_microRusEfi/issues/184 BOM issue wrong size of 2.7K resistors

U9&U10 are now controlled directly without TLE8888, those are now useable

# 0.5
May 2020
Four more low-side channels.
Many more changes! See https://github.com/rusefi/hw_microRusEfi/pull/155

R21,R33,R80,R81 DNP, R122,R123,R124,R125 100R: U32,U33 are driving smart coils via PD4, PD3, PD2, PD1
R21,R33,R80,R81 0R, R122,R123,R124,R125 DNP: TLE8888 is driving external smart coils instead of U32,U33 via PD12, PD13, PD14, PD15. U32,U33 not used. 

R2 0R - TLE8888 watchdog reset will reset stm32 reset and vice versa, stm32 reset would reset tle8888

Four more high-current low-side drivers on board! (but we do not have firmware to run U9&U10 via TLE8888 at the moment)

U9 uses AV6 & AV10 pins.

U10 uses AV8 and AV9 pins.

It's now possible to power up microRusEFI with 5v with the case closed - please feed your USB +5v into pin #19 AV4.
This would affect AV4 reading while USB cable is connected so plan accordingly.

We are now using stm32f427 chip instead of stm32f407. As of May 14, 2020 we simply use the same stm32f407 firmware on the stm32f427 chip. 

# 0.4.8
2020
Improved stitching around Q1 in order to improve thermal properties.
JP1 track flipped to fix VRef issue.

Andrey has one, Nick has one, Matt has one.

# 0.4.7
2020
Different USB connector.

# 0.4.6 
Dec 2019
Corrected scrambled Vref/Vbat/AV4/AV5 inputs.

# 0.4.5 
2019
We have switched to cheaper F4 MCU and 2 layer design with focus on JLC pre-assembly.

# 0.3
2019
'reset' and 'program' buttons added.

Andrey has two!

# 0.2
2019
There was progress :)

# 0.1
Summer 2019
F7 4-layer board is a major success. First edition of the board has worked!

Matt has assembled the first ever microRusEFI and he had a lot happy racing hours on it!
Nick has 0.1 on his 1 cylinder test setup.

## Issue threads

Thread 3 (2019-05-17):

remove VAG specific pinout from schematics

rusefi, 2019-05-17:
alternator low side makes no sense for miata which uses high side alternator

let's remove all VAG-specific names from kicad files and have recommendations in documentation

injector1 2 3 4 are probably maybe the only name to keep in kicad since these are used for injectors in 99% of the cases

960, 2019-05-17:
Why not move the alternator to one of the High-Side drivers instead?
I dont know if it works as low side on any cars?
I kept it like this to make it understandable at a lower level.
It will apply to more people. We understand it no matter what it says.
There are nothing VAG specific there?

rusefi, 2019-05-17:
@960 my point here is that people would be confused. It is not understandable as is in my opinion.

In my opinion its safe to call pins injectors but the rest is not equally universal. I suggest everything else is called low side or high/low or high side output without calling vvt or alternator or anything

mck1117, 2019-05-20:
In the schematic, we should name things by what they can _do_, not what they're _for_.

In user-consumable documentation, we can provide guidance about what each pins could be used for particular functions (this may also vary per vehicle - high side and low side fuel pump relays both exist!).

960, 2019-05-21:
I dont see the issue.
This is a wirein ecu. We want users to wire it according to the default pinout in the dokumentation.
If everyone has different pinout, answering questions from frustrated users will be a nightmare.
The internal schematic are normally used for troubleshooting. Translating the pinout to hs1, ls4 or something users dont understand make no sense.
The default pinout will work in 99% of engine schenarios, and it must be better answering the 1 % than the 99%.
This will newer be a diy ecu, with its 0603's and 0,5 pitch

If you dont understand it, please change it. I wont.

960, 2019-05-21:
Just please dont change any more symbols like you did with the arrays, without keeping annotations or assigning footprints. This broke the pcb drawing, and made a lot of extra work for me.

960, 2019-05-29:
I have started to edit the namings as I said I would from the beginning.
There have never been anything VAG spesific about it, I used names for parts found in vehicles I know, like coil, alternator, wastegate etc. just to keep track of what would be needed for any engine scenario.

I dont care more for VAG than any other cars, I am more of a Volvo fan.

The namings will be the same as in the software.

rusefi, 2019-06-05:
looks to be done

Closed 2019-06-05.

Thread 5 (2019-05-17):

separate constant 12v and ignition key

rusefi, 2019-05-17:
let's separate constant +12v from ignition ket 12v - this case we can implement tle8888 sleep delay later

rusefi, 2019-05-17:
Poke @dron0gus

rusefi, 2019-05-17:
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

960, 2019-05-17:
Doing this will take away one pin, as this will be a low amp wire.
If we use one of the existing pins, we only have one pin with High amp 12v.

Please explain further what this function do, and what we need it for.

mck1117, 2019-05-20:
Without standby power to the stm32's rtc/backup sram (via backup regulator or coil cell battery), this isn't particularly useful.  So I think for this ECU we don't worry about it, and leave the wiring as is.

960, 2019-05-31:
I think we can close this?

It would take one connector pin, and do nothing of use.

Closed 2019-05-31.

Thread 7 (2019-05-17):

remove solder mask under the screws

rusefi, 2019-05-17:
@jharvey do we want to remove solder mask under the screws, so the case is grounded to the board?  I’d think it would get rubbed off anyway by the screw head

rusefi, 2019-06-05:
@960 says this is done

Closed 2019-06-05.

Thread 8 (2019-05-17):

Cut some analog pullup resistors

mck1117, 2019-05-17:
We only need pullup resistors on inputs for thermistors or hall effect (cam sensor).  We can remove all but ~4 of the pullup resistors.

This will save a bit of board area.

960, 2019-05-20:
This is reduced to analog 1 to 4 now

Closed 2019-05-20.

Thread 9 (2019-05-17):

Cut hardware from vref analog

mck1117, 2019-05-17:
The vref signal doesn't need its second series resistor R142, pulldown R143, or protection diode D14.  If these became necessary, we've already blown up the rest of the board.

rusefi, 2019-05-30:
@mck1117 is this still an issue in your opinion?

960, 2019-05-30:
What voltage should be at Vref?

Doesnt it need the voltage divider R142, R143 ?

Diode are removed

rusefi, 2019-06-04:
This implementation of VRef would be invisible for software since we feed the output into MCU vref input pin

rusefi, 2019-06-05:
Do we need R44? Do we need R99?

mck1117, 2019-06-05:
R44/99 are OK to leave, and initial request is now resolved. Closed!

Closed 2019-06-05.

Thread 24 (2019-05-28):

ST-Link header and USB are too close to each other

rusefi, 2019-05-28:
@960 I believe ST-Link header and USB are too close to each other - as is they would not allow to be used simultaneously. Need to move 2mm further apart

here are the details:
eBay st-link connector width 20.4mm

random white micro USB cable width 12mm

st-link header and USB centers should be 32.4/2 = 16.2mm apart

currently st-link center line X=47

currently USB center line X=61.5

this is only 14.5mm apart

960, 2019-05-28:
In my current pcb file, they measure 16,5mm CC

Closed 2019-05-28.

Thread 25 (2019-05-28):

Molex 48 pin silkscreen on the back

rusefi, 2019-05-28:
Can we please add some silkcreen on the back of the PCB for the connector?

definitely need some pin number reference at least for some pins otherwise we are blind

maybe even call out GND and 12v. 5v also?

rusefi, 2019-05-28:
@960 what do you think?

960, 2019-05-28:
I think we need to make something like this
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

rusefi, 2019-05-28:
Both :) We will have picture in the documentation but still some silkscreen would help

960, 2019-05-28:
Can we make help files work in TS?

rusefi, 2019-05-28:
Not sure what you mean.

rusefi, 2019-05-29:
We have progress :)

rusefi, 2019-05-29:
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

rusefi, 2019-05-30:
This is good enough at the moment but in my opinion more could be added. Adding more silkscreen to the connector is a great cost/benefit ration in my opinion.

Lowering the priority but keeping open for now.

rusefi, 2019-07-06:
looks great!

Closed 2019-07-06.

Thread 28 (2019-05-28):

Three more status LEDs

rusefi, 2019-05-28:
If we have space it would be nice to have four status LEDs total, same as on discovery407

We have "Running" PE1

Please add same schematics with LED+Resistor for PE2, PE3 & PE4

rusefi, 2019-05-28:
Frankenso has a diode in addition to LED and R on the low side outputs

would microRusEfi also need a similar diode on low side output  LED?

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

960, 2019-05-29:
There will be no leds or testpoints at anything that already goes to the connector.

jharvey, 2019-06-01:
I'm a fan of these LED's on the injectors and ignition pins. I think Ola has not had the joy of diagnosing a failing injector after a mechanic has probed the harness with a meter and damaged a harness side of the connector. It is very common, and seeing a blinking light which says the ECU is good is really helpful in detecting if the problem is the ECU or the harness side. I understand the desire to no open the enclosure, but I also get angry at OEM's who fail to provide me with diagnostics information. A key feature of open source is that you have access to the low level information and can preform diagnostics. The MTBF of these LED components is very high, so they are not failure sources. Our failure sources are far more likely to be failed diagnostics by a mechanic who is in an uncontrolled world. I would like to encourage these LED's, however at the end of the day it's your design so your choice. I'm not looking to get into a debate about KISS or design elegance. I'm just trying to show why most OEM product include similar diagnostics LED's. In our case, our lack of control over the mechanic is why I think we need them when most OEM's do not have them. After all they are inside the enclosure, and if you never have a problem you'll never see them. You'll only see them if your already angry thinking the ECU has failed. These LED's can help prevent people from getting angry at the ECU people.

960, 2019-06-05:
Leds are added, I think we can close?

rusefi, 2019-06-05:
schematics show 4 status LEDs

Closed 2019-06-05.

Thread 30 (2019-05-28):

test pads for CRANK and CAM

rusefi, 2019-05-28:
for VR crank we really need a way to hook up logic analyzer for troubleshooting. While we have tiny LED pads to solder to I would prefer a nice 2mm diameter test pad so that if needed a pin could be butt-soldered

ideally same style pad is needed on PA5 track. PA5 would be the default crank at least in the beginning (I know schematics says AnOut7 = PA6 as cam but I believe this would NOT be my first preference) ICU is still the primary mode for trigger input and ICU works on PA5 not PA6

rusefi, 2019-05-28:
Q:  Why/when do you need pads for trigger?

A: for trigger logic troubleshooting we sometimes need to record raw signal using logic analyzer. Cranking, loss of sync - all these special cases can use logic analyzer recording of raw signal.

960, 2019-05-29:
What difference will these make compared to the external in connector?

You also have six 0603 footprints at the same place to solder wires.

I have tested these inputs with all kinds of signals, both hall, mcu output, VR, 1,5V battery etc..
Everything work perfect.

For the PA5 line, you will just be able to measure the same as the MCU sees?

I can add pads, I just need to know if it's really needed,

rusefi, 2019-05-29:
Q: What difference will these make compared

A: I need processed digital crank signal not source analog VR signal

960, 2019-05-29:
I think I have misunderstood the question.

I will replace the led with a pad.

I still dont see why it's needed, but anyway.

Those are the MCU inputs, and I thougt you could do the exact same reading with the MCU.

960, 2019-05-29:
Added

rusefi, 2019-05-29:
@960 while we can read from MCU its not comfortable.

i do not understand your goals. you are making this board hard for me to use, i am getting afraid that i do not want to be first user.

sure i would enjoy this as a product, but i am not interested in artificial hardships developing for this platform

960, 2019-05-29:
I have added the pads, so please just be happy with it.

rusefi, 2019-05-30:
I see CRANK pad

I see "CAM" words but I am not sure what these are referring to, please help me find CAM pad.

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

rusefi, 2019-05-30:
with new schematics CAM signal could be measured on the connector it looks like

no protection on CAM now?

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

960, 2019-05-30:
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

960, 2019-05-30:
Diode added just in case

960, 2019-06-04:
Pads added, and can be closed

Closed 2019-06-05.

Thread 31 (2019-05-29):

Larger T5V1/2 buffer caps

mck1117, 2019-05-29:
Buffer caps are currently 100nF, minimum recommended by datasheet is 400nF.  We should use 1uF or 1uF+100nF.

960, 2019-05-29:
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

960, 2019-05-29:
Isnt that what I have?

mck1117, 2019-05-29:
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

I mean for the 5 volt tracker outputs.

mck1117, 2019-05-29:
(other supplies (5v main, 3.3v, 6v prereg) look fine)

960, 2019-05-29:
Ok, I just made this from the reference design.

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

960, 2019-05-30:
Is it enough with larger values, or do we need larger footprints?

rusefi, 2019-05-30:
@mck1117 ?

mck1117, 2019-06-04:
footprints are already 0603, closing as it isn't a board issue.

Closed 2019-06-04.

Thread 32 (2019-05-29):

Ground ignition inputs to TLE8888 + IGNEN pin

mck1117, 2019-05-29:
Ground unused inputs instead of leaving floating. Prevents them bouncing around on their own due to EMI.

960, 2019-05-29:
I can do that.

I think all have a pull-up, does that matter?

jharvey, 2019-05-31:
I believe the stm32 has configurable pull ups and pull down. Those pull down are likely already taken care of by chibios.

rusefi, 2019-05-31:
@jharvey i believe this ticket is about TLE8888 unused pins not stm32 unused pins

960, 2019-06-05:
This is done, and I think we can close.

Closed 2019-06-05.

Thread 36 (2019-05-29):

U5 wants that 4th pin connected to GND

rusefi, 2019-05-29:
U5 the LM2937 schematic is missing pin4, which is connected to pin2. This causes the PCB footprint to miss the GND connection and decreases it's thermal characteristics.

@jharvey suggests adding the pin 4 to the schematic.

960, 2019-05-30:
This one are solved.

Pad number 4, (now 2) are connected to GND

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

rusefi, 2019-05-30:
@960 was this published? do we expect schematics to show 4 pins now?

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

960, 2019-05-30:
The symbol dont have pin 4

Instead of editing the symbol to be custom, I changed pad number for footprint to 2 to get ground at the Thermal pad.

jharvey, 2019-05-31:
I agree, this one is solved.

Closed 2019-05-31.

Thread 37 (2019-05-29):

USB D+ and D- should not have stubs or via's

rusefi, 2019-05-29:
USB D+ and D- should not have stubs or via's. There is a paper on that some where around here. The USB is different than our other low frequency signals, and needs more attention for reliable USB operation.

D16 likely doesn't do anything as it's layout. The sharp angles after a stub will make most RF pass right by this. Most of the damaging energy in a ESD surge is high frequency. There is a white paper, I think it was from Intel, similar to the below, but for 2.0 and high speed and full speed stuff. It had many of the same recomendations and very similar data to back the suggestions.
https://www.intel.com/content/dam/www/public/us/en/documents/white-papers/usb3-frequency-interference-papers.pdf

960, 2019-05-29:
This are taken care of now. please close.

rusefi, 2019-05-29:
@jharvey please review

rusefi, 2019-05-30:
I believe we have a via on D+/D-?

Need to find a way for @jharver or @mck1117 or @dron0gus to comment. I know _nothing_ about electricity.

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

960, 2019-05-30:
Vias in the ends are ok.

We have no way avoiding that to get thru pcb anyway.

The stubs are as good as they can get, Vias have enough space, and the traces have enough gnd plane all along next to them.

It's also routed to not go under the crystal

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

mck1117, 2019-05-30:
Those stubs aren't going to get much better, and usb FS (12mbit/s) is pretty tolerant of stuff like that anyway.  If it doesn't work, they're on external layers so we can cut them with a razor and remove in a future rev.

jharvey, 2019-05-31:
I think this will work just fine for our needs. If note I see the traces which might create issues can be scratched off. So we have a back up plan if we have a problem with this first spin. I think the USB is as good as it's going to get. I'm kind of tempted to suggest a 1uF cap but have not been able to check it against https://www.usb.org/sites/default/files/power_delivery_motherboards.pdf I suspect that is not a critical thing. I'm tempted to suggest just add some DNP pads for a cap, and we can deal with it later.

rusefi, 2019-05-31:
@jharvey 1uF cap where exactly? :)

jharvey, 2019-06-01:
per https://www.usb.org/sites/default/files/power_delivery_motherboards.pdf
2.2 shows 470pF parrell with 220uF.
2.3.1 power lines must be bypassed with no less than 120µF capacitance of low-ESR capacitance per USB port
2.3.3 power and ground pins should be at least 0.050-in.-wide, with 1.5-oz. to 2-oz. copper
2.4.1 I do not like PPTC's for this. Most can be thermally activated in our normal operation parameters. If a PTC ends up being used, pay special attention to the devices temperature characteristics. I would simply negate this protection. Most upstream sources have good enough protection included.

I think the above spec is very much on the safe side. I think we can negate the fusing concerns, we don't care if we take the bus voltage down. I rarely see 120uF caps on the power as they suggest. The small cap is for noise suppression of the arcing that happens when you connect the USB plug, so that 470pF is a good idea. We should also have pads for a 1uF or as they suggest 120uF cap. I'd just put what ever is "reasonable" on an 0805 for this cap. That might be a 1uF, or a 10uF, if we can get a 120uF, might as well follow the spec. I think the spec is excessively conservative with this cap.

D17 will drop about 1V, so your 5V will really be more like 4V. As well if you draw 0.5A, that's 0.5W that the LED has to survive, with a poor heat sink. It is common to use a p-MOSFET, as seen below. Note the "Vin" is typically connected to GND via 10k. That circuit has an option which can be used to disable the 5V. We do not need that T2 MOSFET which is used to disable the 5V from USB. We just need the p-MOSFET and a high ohms resistor to GND. If we do this then we will have 5V instead of 4V when connected to the USB.
https://forum.arduino.cc/index.php?topic=158717.0

The chip shown above can be found here. Other p-MOSFET's could be use if so desired.
https://octopart.com/fdn340p-on+semiconductor-84326388?r=sp&s=Z0-2bL1_T3ieiurR2iQ5PA

More about reverse polarity protection found here http://www.youtube.com/watch?feature=player_embedded&v=IrB-FPcv1Dc As noted by D1001 on Frankenso, I'm also a fan of the clamping diode.

I suggest PWR LED on USB. AKA not all USB cables include the power wires. It is common the cable only provides data. I know the concerns of these LED's, but they are also very common.

At the end of the day, I think the USB as it is drawn now will mostly function, and will probably function well enough that no one cares. However there are likely some areas which can be made better. So I tend to flip flop on this. Some times I want the above noted components, just because an app note says you should have them. However other times I tend to think we don't need them, as they are just extra parts that don't really do anything we really care about. I don't think this CAP stuff is really very critical. I vote that this be closed, and what ever Ola decides to put in, should be good enough. I've shared some data so he can make an better informed decision.

Closed 2019-06-01.

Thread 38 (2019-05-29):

CAM op-amd and CRANK via TLE8888 need pull-ups

rusefi, 2019-05-29:
Mazda Miata NA and Mazda Miata NB uses open collector hall sensors for both CRANK and CAM

I assume that we would use TLE8888 input for this open collector CRANK and one of op-amp inputs for CAM

Both crank and cam inputs would need need pull-up resistor option

PS: it's my opinion that we have space for all op-amp inputs to have both pull-ups and pull-downs not just 6 channels, it's my opinion that by not having pull-ups you limit the board too much

960, 2019-05-29:
Please elaborate.

Do you mean CAM, not Crank?

If a pull up are needed to read a Hall-Sensor I will add it, I did not know that.
As the ones I know have a positive(rising) signal, I have used a pull-down for the cam.

4 dedicated AN-TEMP Inputs
9 dedicated AN-VOLT Inputs
1 dedicated CAM Input
1 dedicated Crank Input

This is way way more compared to any other ecu's at this level, and exactly the same(With Pullups) as my $1800,- LINK ECU.

Are this really a important issue and a limitation???

rusefi, 2019-05-29:
miata na and nb generations both crank and cam are hall sensors are open collector outputs so you need a pull up to translate into digital form

@960 please elaborate what vehicles do you usually work on? could it be that you are making a VAG-specific board not universal board? you seem to not care about stepper idle and overall it looks like you have a pretty sptecific vehicle in mind

960, 2019-05-29:
I work with all kinds of european cars.

You wrote Crank in the issue?

I have checked the TLE8888 datasheet, and I have covered each and every scenario.

When you make such a claim I make anything at all of this to be VAG spesific, I expect you to explain exactly what you mean are VAG related!
That comment really offends me.

I am making this as close to any other aftermarket on the market as possible, working for any engine.

I did not know about the CAM Pullup needed.
We need to find a solution that works for all hall sensors.
It might be I am wrong, and a pullup are the right one.
If both, we need to add a switch IC that toggle between pull-up and pull-down.

960, 2019-05-29:
I was wrong, and a hall sensor should have pull-up.

Pull-up added.

960, 2019-05-29:
Can you also explain a bit better what you need for the Crank?

I dont understand what of this that wont work for your trigger.

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

rusefi, 2019-05-30:
@960 I am not aware of any issues with the current crank schematics.

I am only looking for a confirmation that this schematics (which I do not completely understand) would work fine on an open drain hall sensor.

960, 2019-05-30:
Yes, I can guarantee it will.

The cam sensor now have one pull-up, one series and a diode.

It's taken directly from a VAG oem schematic with open-drain hall

The Crank input have options for every possible scenario on planet.

Closed 2019-05-30.

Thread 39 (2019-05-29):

traces to not be under the screw heads, or under the enclosure

rusefi, 2019-05-29:
Can we limit to only two screws, and get some more clearance near the harness connector? That would allow traces to not be under the screw heads, or under the enclosure.

960, 2019-05-29:
I have rerouted the traces that got under the screw head when narrowing down edge cuts.

Under the pcb, there will be traces touching the enclosure all over it.

For now, I would like to keep all 4 screws.

rusefi, 2019-05-29:
there will be plastic under the pcb

rusefi, 2019-05-30:
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

rusefi, 2019-05-30:
@960 says "The board doesn't touch the enclosure at top" - PCB is thinner and bolted to the bottom  leaving some small space on top everywhere.

Closed 2019-05-30.

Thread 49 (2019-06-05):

J2 changes: BOM - mouser part number, j2 silkscreen placement, key silkscreen, vias

rusefi, 2019-06-05:
PinSocket_2x05_P2.54mm_Vertical_SMD needs part number

1) J2 ST-link connector:
1) silkscreen "J2" label is currently hidden under the part, please move it to make it visible
1) Please add silkscreen image of the key tap so that people know which way to insert st-link device. Also so that China knows which way to assemble
1) please add via into the pads in order to reinforce those.

ZHoob2004, 2019-06-10:
I propose Molex 15-91-0100

(also available as Molex 15-91-2100 with tin plating if you're into that sort of thing)

rusefi, 2019-06-16:
@ZHoob2004  15-91-0100 would not work

 15-91-0100 is a male part and st-link is male. We would need a female part on the PCB.

It would also be nice for the J2 female to have the key as pictured on brain board which uses through hole
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

rusefi, 2019-06-16:
@ZHoob2004 brings up a great point about stain relief. In light of SMD mount we  in fact should go with male header, let's just find a part with the key.

ZHoob2004, 2019-06-16:
Samtec HTSS-105-01-T-DV is a similar part with a plastic shroud that enforces connector direction, though it costs almost twice as much as the previously mentioned part.

rusefi, 2019-06-16:
@

ZHoob2004, 2019-06-17:
The shrouded part is too large for the existing footprints (would stick off the edges approx. 1.5mm on each side.)

I think we're stuck with the open version I suggested above, at least until there is a change to the board layout. I imagine we can get by with connector orientation clearly marked on the silkscreen.

rusefi, 2019-06-29:
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

jharvey, 2019-07-05:
About the J2 connector. I've been 50% about the via's inside the pads. I understand the school of thought that it sucks up the solder which can result in a poor connection. But I also do not have any real empirical data which claims it's bad. I can not find any real guides which detail why it's bad, etc. As well I'm not crazy about spending money on every board to have this connector, when it's only used once by developers. So I purpose.... an adapter PCB with a spring connector. Such that you just have pads on the PCB and then you press the programming dongle against the PCB and program away. This reduces cost of the PCB's as well it removes the debates of the entire via-in-pad debates. I see the below is not very expensive.

https://www.digikey.com/product-detail/en/mill-max-manufacturing-corp/838-22-010-10-001101/ED10885-ND/6573078

So is everyone on board with changing to this kind of spring connector? Any thoughts?

rusefi, 2019-07-05:
Suggested part number if male 2.00mm not 2.54mm and I do not understand the whole process. I do not like the spring loaded idea because for me this is a new skill I have to learn, I would prefer to stay ignorant. I do not understand where would the new hand which would be holding the connector in place be coming from. I am afraid when I think about average users required to use it.

we have 4 options I assume at least?

1) can we do though-hole and shave the part on the read and press it against some film?
2) SMD no via
3) SMD with via
4) spring-loaded

@mck1117 how unstable is current SMD no via in your opinion? did you use it with wires or pins at all?

mck1117, 2019-07-05:
I wouldn't recommend hitting the current setup with a hammer.  Other than that, it's fine.  I use it with a 10-pin IDC ribbon cable with a 20-pin connector for my legit ST-link v2 on the other end of the ribbon.  There's a lot of total pad area under there, so I'm not worried about peeling it off of the board.

Option 1. sounds like a bad idea.  That's labor, and possible shorts to ground.
Option 2-4. The spring load pins don't necessarily need any special pad on the board to work.

Here's my proposal.  Leave the pads as is (SMD, 2.54mm spacing), which supports the following scenarios:
- Development: solder on SMD male/female connector.  Connect stlink.
- End user: program once using pogo pin jig, and don't install a connector.  If a user wants to become a developer and debug on their board, it's easy to add the connector.  End-user firmware updates should be done with DFU over USB, so you really shouldn't need a connector here.

Even if we want to use the spring loaded pins, there's no cost to using the full size pads for the solderable header, so why not do it? Leaving full size pads leaves our options open.  If we want a header on every board, that works.  If not, that also works.

rusefi, 2019-07-05:
@mck1117 "as is" is vague in my opinion. "as is 0.1" is different from "as is 0.2 is master"

please spell out "smd with via" or "smd without via" or else?

mck1117, 2019-07-05:
SMD with or without via probably doesn't matter.  It's a relatively large pad, so the solder-sucking effect from a single via would probably be minimal.  By "as-is" I meant "SMD sans via", but adding vias wouldn't hurt.  Either a header or pogo pins would work the same.

mck1117, 2019-07-05:
Such a pogo jig might look like this:
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
All it needs is some alignment pins to line the board up, appropriate spring loaded connector(s) to make contact with spots on the board, and something to hold it down.  It's really that simple.

rusefi, 2019-07-05:
^^^ looks totally unrealistic to me but I will believe it once somebody ships it to me.

Sounds like current SMD stays for now. If we believe current 0.2 master with vias is solderable and not worse than 0.1 let's move on?

mck1117, 2019-07-05:
Yeah, SMD+vias is fine.

jharvey, 2019-07-05:
In e-mail, OLA had suggested using a BDM frame similar to what is noted here. https://www.google.com/search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

jharvey, 2019-07-05:
Can we find a lower cost version of the below?
https://www.digikey.com/products/en?keywords=TC2050-IDC-ND

mck1117, 2019-07-05:
While that's a neat connector, why?

mck1117, 2019-07-05:
Also, using a BDM frame as an *intentional* development tool seems silly.  They're designed for reverse engineering and probing of pins where you don't have a connector because you didn't design/fab/etc the hardware in question.  We're not in that scenario.  Let's do the right thing and just use a normal header 😄

960, 2019-07-05:
I recommend keeping it as is now.

However, I would have switched PA13 and PA14.

I dont remember if I did, can you check?

PA13 should be pin 2, PA14 pin 4.

jharvey, 2019-07-05:
The inside a china video posted a bit ago, shows them using a frame that is very similar to the BDM frame for programming and validation of PCB's. I think the frame is more than just a developers tool. Those are commonly used for both MFG programming as well as development purposes.

About the why.... I guess largely for OCD purposes. I know that there will be endless debates about shed color, I mean about the entire solder sucking via's. I also know that OEM do it this way, so I kind of want to do it if for no other reason, just to get a better understanding of the OEM process. As well if we do it this way, then we can avoid the solder sucking land mine debates which I'm sure will come.

960, 2019-07-05:
As I use it all the time, I have to say a universal BDM frame are a little painful to use.

There are no alignment, so the exact placing take some attention.
I also need to be very careful nothing moves.

The spring loaded pins also bend easy.

The sucking vias are more of a issue at tiny pads, and end up beside the component instead of under.

The one mentioned was at one of the 0603 arrays, that was moved a little by accident.

rusefi, 2019-07-12:
We now have some silkscreen for key

rusefi, 2019-08-10:
Let's continue the discussion at #88

Closed 2019-08-10.

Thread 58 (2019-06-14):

loading caps on the crystal

rusefi, 2019-06-14:
@mck1117 says "loading caps on the crystal should be 8pF instead of 20pF"

mck1117, 2019-06-20:
confirmed - 8pf caps function properly

jharvey, 2019-07-05:
mck1117, have you seen the note on page 5 of Frankenso? I have some notes and a reference note when we were trying to figure out this intermittent clock issue. See below snippet which is on the Frankenso schematic.
<code>
http://www.crystek.com/documents/appnotes/Pierce-GateIntroduction.pdf
PCB per predictions with SaturnPCB has less then 3.5pF traces,
TPIC pins assumed 5pF
ESR = 80ohms max
Rf = 2meg could be between 1meg and 10meg.
Cload should be 18pF per XTAL datasheet
Cload = ([Cin+C1][C2+Cout])/(Cin+C1+C2_Cout)+PCBstray
Cload = ([5+24][24+5])/(5+24+24+5)+3.5= 18.0pF
C1=C2=C166=C167 = 24pF
Rs = 1/(2piFC2) = 1/(2*pi*8MHz*24pF) = 829ohms, 820ohms is close enough = R177
</code>

I think we technically for this one, we want 4pF not 8pF. See my calcs from here
https://docs.google.com/spreadsheets/d/1O6-u6T_O083pT9SEm70DGKKy6YZJ89tGeXWsZTZnmM4/edit?usp=sharing

mck1117, 2019-07-05:
I hadn’t seen that yet, no. The boards I’ve assembled so far have 8pF caps, and seem to work fine, fwiw. Is there a way to empirically measure whether the crystal is over or under loaded? I have a 200mhz scope at my disposal, and a 4ch/2ghz one at work if I need it.

Get Outlook for iOS<https://aka.ms/o0ukef>
________________________________
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

jharvey, 2019-07-05:
I don't know a way to measure if the loading is proper. I understand the problem is mostly a failure to start issue. If you change your pF's you can wander the 8MHz slightly, but I don't think we care about the slight warping. I guess we could measure it bey building 1k boards and see if they all start at the min and max temperatures. If yours is starting, with 8pF then it's probably fine. I see 4.7pF is available, so I updated the BOM and schematic to call for that.

Closed 2019-07-07.

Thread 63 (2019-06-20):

Schematic labels for ignition/high side drivers are wrong

mck1117, 2019-06-20:
Functionality and connector pinout are ok - the labels on the schematic sheet are wrong.  Currently the first two channels (labeled IGN_1 and IGN_2) are the voltage selectable ones, which agrees with the connector pinout.

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

jharvey, 2019-07-05:
Just flipped the net names around. I think this can be closed.

Closed 2019-07-05.

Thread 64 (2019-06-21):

Add pull up/down resistors for ETB control pins

mck1117, 2019-06-21:
Currently, between the internal pull up/down in the TLE9201 and STM32, the H bridge goes to full power reverse when the STM32 is in reset.

1) At a minimum we need a pullup resistor on the DIS pin
2) ideally also a pull down on the PWM pin.

These will ensure that even when the STM32 hasn't set up those pins yet, the throttle won't move.

mck1117, 2019-06-24:
Adding a bodge resistor from DIS to +3.3v on my board seems to have fixed the issue, so that may be all we need.

rusefi, 2019-07-03:
DIS pull-up is R1
PWM pull-down is R16

Closed 2019-07-03.

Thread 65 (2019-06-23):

document power and thermal expectations

rusefi, 2019-06-23:
@mck1117 says
I hooked up current consumption monitoring, and linear regs are killing us lol
235mA
2.9 watts
frankenso pulls around 85mA, 1 watt

We probably should not care but we can document just to be nice about documenting

@jharvey FYI

jharvey, 2019-07-05:
Can I get more details? Including
-- how low can we go on volts
-- peak amps with no load so no injectors connected
-- Inrush amps
-- Amps at 18V
-- Amps at 14.4V
-- Amps at 12.0V
-- Amps at 8V.

While I'm asking for all sorts of stuff. how about amps while right side up and while upside down. then amps while facing north, and amps while facing south :)

jharvey, 2019-07-05:
I added "rusEFI MRE was measured to consume 235mA from the 12V battery, for 2.9 watts" to both the PCB as well as the schematic. This is handy as it give me an idea about how I should set my power supply amps limit for my bench top supply. AKA don't let the smoke out when there is a mild issue.

Closed 2019-08-11.

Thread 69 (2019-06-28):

LD1117 is a dollar cheaper

rusefi, 2019-06-28:
LM2937 is $1+ while LD1117S33TR from mouser is $20@100. Shall we move to LD1117S33TR?

jharvey, 2019-07-05:
There is qty 1 of this component, I say use OEM official parts, we can deal with making it slightly cheaper once we know it works well. It's cheap insurance for a flat $1 fee. I suggest this is closed.

abelom, 2019-07-05:
I do not follow. Why is LD1117S33TR from mouser not OEM official part? Why do we not trust LD1117S33TR from mouser? @jharvey

I agree this is low priority

DonaldBecker, 2019-09-17:
The motivation to change from the LM2937 should be because it is a specialty part.

The LM2937 has the unusual feature that the tab is ground.  This is convenient for mounting to a heatsink, but otherwise is a disadvantage. Most regulators have a pinout that puts the input or output on the tab, which allows mounting the die directly on the tab for best thermal and electrical conductivity.

This electrical connection to the tab is associated with the regulator's internal construction and characteristics.  The classic high-drop-out LM317 has the tab as an ouput, with a NPN Darlington pass transistor mounted directly to the tab.  A tab as an input pin suggests a PMOS pass transistor which allows a very low dropout voltage, low quiescent current, but a more limited input voltage range and capacitor ESR.

We don't use any of the special features of the LM2937 (ground tab, high voltage input, reverse voltage protection).  It's reasonable to switch to the standard tab-output pinout, which allows using a wide range of better performing, lower cost regulators.

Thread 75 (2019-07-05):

LEDs for analog processed crank and/or cam input

rusefi, 2019-07-05:
We have test pads but it is my opinion that our custom base would appreciate LEDs on crank and/or cam inputs

mck1117, 2019-07-05:
Is there a software solution we can use instead? Surely we can speak the right incantations to Tunerstudio to get this to work:
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

abelom, 2019-07-05:
Noth solutions are valuable. We have the ticket for composite logger with no progress for a while :(

jharvey, 2019-07-06:
Was the LED's loading a concern on either CAM or CRANK? With a 1k LED resistor, I expect the LED to consume about 4mA.

rusefi, 2019-07-06:
probably cam hall since very simple schematics? probably not vr crank since fancy tle8888 is dealing with it?

jharvey, 2019-07-06:
For CAM I just added a series LED. I think I can do the CRANK but after the 8888 has decoded it, and is generating digital pulses. Hmmm, I have no idea if this will work on the 8888. I do not see an mA rating for VROUT. I do not know if that is sink vs source. So this may not work for the VROUT signal. However I have added some pads so we can try it out.

mck1117, 2019-07-06:
Added a series LED where? Can you update the schematic PDF, or attach a snip of the change here?

Also, don't add extra test pads to the board for things like this.  We made TLE8888 breakout boards for exactly this purpose, so let's test out feasibility on those before we spin boards without knowing whether it'll work.

rusefi, 2019-07-06:
@mck1117 just manually merged latest
@jharvey can you please generate fresh .pdf?
Jared shall we close this now or still things to change?

mck1117, 2019-07-06:
The cam LED, as currently wired, won't work.  Forward voltage for an LED can be upwards of 3.5v, so the highest voltage seen at the cam pin could be as low as 1.5 volts.  That's very very close to the STM32's input transition voltage, so it may not actually read edges on the cam input.

rusefi, 2019-07-07:
Would a diode help CAM LED @jharvey @mck1117 ? I am sorry I know it's not my place to talk EE :)

Closed 2019-07-07.

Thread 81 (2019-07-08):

LED symbol was not shared, and needs to be corrected.

jharvey, 2019-07-08:
LED symbol "Device:LED" was not shared by OLA, and has the same name as a KC standard library. This causes the wrong symbol to be used. This needs to be updated, perhaps using a symbol name that is not already a standard name. The current LED shows backwards, as pad 1 and pad 2 are backwards.

rusefi, 2019-07-08:
@jharvey would it be best to simply use "Device:LED" from KC standard library but fix the usages to be correct? this case we use the right default symbol as intended, it's not like we have custom R or C symbols?

jharvey, 2019-07-09:
Hmm, I'm trying to change the title. I can't seem to change it. The symbol was apparently never shared, so it was just plane wrong. I wanted to update the title to reflect this.

I'll figure out how to correct it. Either change the footprint, or change the symbol. I'm not sure what the solution will be.

960, 2019-07-09:
How about just turning them around?
You can do that in eeschema, just rotate..

jharvey, 2019-07-09:
KC footprint was over-sized, and does not have a clear polarity indicator. So I updated the footprint to match the MFG's suggested pads, as well I gave it a clear polarity indicator.

Closed 2019-07-09.

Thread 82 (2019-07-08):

injector, coil, and VVT LED is bright when device is off. This should be flipped, to bright = on

jharvey, 2019-07-08:
These LED's are connected to the low side of the circuit, instead of the high side of the circuit. This causes the bright vs dim to be inverted from expectations. The circuit should be changed to the high side to better match intuitive tendencies.

jharvey, 2019-07-09:
Changed the LED's to be bright when the device is being driven. Resolved in R0.2.1

Closed 2019-07-09.

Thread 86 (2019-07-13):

VDD BOOT0 usability

rusefi, 2019-07-13:
We still do not have https://github.com/rusefi/rusefi/issues/809 and I assume that even once we have it sometimes things would not go well, so

We need some usability for VDD<>BOOT0 jumping. At the moment we have R26 which I assume is the default 0603 which is not very useable for jumping while rebooting.

We need an SMD jumper header so that a jumper could be put to connect VDD with BOOT0 if desired

Abricosvw, 2019-07-28:
i think best approach is not exposed pns for jumper but a touch button (not toggle button)

rusefi, 2019-07-28:
@Abricosvw  Omron Electronics Inc-EMC Div B3U-1000P for $1.50 is too much money!

There must be something similar waaaay cheaper on eBay. Overall I like the push button idea!

rusefi, 2019-07-28:
I like https://www.ebay.ca/itm/100PCS-3-4-2mm-Mini-Tact-Tactile-Push-Button-Switch-SMD-2Pin/232305685293

jharvey, 2019-07-29:
What is the digikey equiv to add to the BOM?

rusefi, 2019-08-10:
I believe the button is a bit larger than the current footprint. Can we expand by 1mm?

See image

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

jharvey, 2019-08-11:
See if this one fits better. Also this is really close, did you verify you had 100% scale? It is common that printers will print 98% scale, which can bugger things like this. I often have to print at 102% scale to get closer to the 100% scale in the real world.

rusefi, 2019-08-11:
Looks good now!

Closed 2019-08-11.

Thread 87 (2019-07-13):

What are R44 & R46 used for?

rusefi, 2019-07-13:
We have 0R R44 and DNP R46, what is the use-case for those? Would we remove those once some testing is done?

rusefi, 2019-07-13:
@mck1117  says
r46 selects vref = 3.3v
r44 select vref = vcc * 0.6

rusefi, 2019-07-13:
When would we want 3.3v instead of vcc * 0.6?

rusefi, 2019-08-10:
Is anyone planning to even not have 0R R44 and DNP R46?

mck1117, 2019-08-10:
We probably actually want to use r46, and NOT r44.  The trouble is that if we use r44, vref is out of spec for the stm32 if the board is supplied 5v via USB, and not 12v via the connector.

The side effect is that battery voltage measurement is unpredictable when vref is very low, so we may be unable to detect a rising edge on the battery voltage if r44 is used.

My board and russian's board both use r46.

rusefi, 2019-08-11:
OK whatever low priority for 0.3 ;)

rusefi, 2019-08-19:
@mck1117 so let me flip the question :)

Is anyone planning to even not have 0R R46 and DNP R44? Shall we make R46 a trace and remove R44?

mck1117, 2019-08-19:
Is there risk to leaving both footprints?

mck1117, 2019-08-19:
(not that I'm necessarily advocating for leaving both -- routing a trace in place of r46 is probably the right thing to do)

rusefi, 2019-08-19:
This is truly a low priority, but we shall at least fix the BOM to suggest 0R R46 and DNP R44 for now

jharvey, 2020-04-05:
This is obsolete at this point in time. Suggest closing this issue.

Closed 2020-04-05.

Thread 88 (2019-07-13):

SWD footprint and silkscreen

rusefi, 2019-07-13:
Would it be possible to add silkscreen to 6 pins of SWD header?
SWO
(N)RST
(S)CK
(SWD)IO
GND
VDD

Both 5v and second GND/VDD are less important

rusefi, 2019-07-21:
We have used proper footprint on rusEfi brainboard (it's upside down comparing with MRE but note where GND is)

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

rusefi, 2019-07-21:
"SWD is always mapped on PA13 (SWDIO) and PA14 (SWCLK)"

there is also some problem with SCK net name PA14 should be clock and SCK is clock? the pin which is NOT IO not CLK not NRST should be PB3/SWD?

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

rusefi, 2019-07-21:
also are all IDC cables the same? if we plan to use IDC cable do we need to invert the pinout since the female/female cable flips it?

rusefi, 2019-07-27:
Looks like at the moment schematics has the correct names/functions for tracks/pads, while PCB has some errors related to PA14 not being CLOCK and PB3 not being SWO?

rusefi, 2019-07-27:
See also some comments at #49

rusefi, 2019-07-28:
@jharvey reminds us that PB3 is used both as SWO for singe wire debugger as well as SPI but clock used to SPI TLE8888

rusefi, 2019-08-10:
Here is a picture of an IDC cable. Both sides have the key on top, red and yellow wires are both in top row, there is continuity between the holes into which red and yellow jumpers are plugged into

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

mck1117, 2019-08-10:
ST now has the [STLINK-V3MINI](https://www.st.com/content/st_com/en/products/development-tools/hardware-development-tools/hardware-development-tools-for-stm32/stlink-v3mini.html).  This is the new official debug tool from ST, and **is under $10** (but isn't yet in stock anywhere - it will be soon).

It has a 14 pin 1.27mm connector on the bottom, and includes a 14-pin IDC cable.  It's compatible with the 10-pin Cortex debug header, but adds an extra pair of pins on each end.

I would recommend using a connector like this one: https://www.samtec.com/products/ftsh-105-01-l-dv-007-k

Since it has no ends on it, it can accept either the standard 10-pin cortex header, or the ST 14-pin extended connector on the STLINK-V3MINI.

mck1117, 2019-08-10:
In addition, that maintains backward compatibility with older st-links (and other programmers) by supporting the industry standard 10-pin Cortex debug header.

rusefi, 2019-08-10:
STLINK-V3MINI with 1.27mm is interesting for MRE 0.9 or MRE 1.0, for now let's survive the next 6 months with 2.54mm

It looks like IDC cable mirror pins left to right but keeps top and bottom? I.e. top-left pin becomes top-right pin here. All three female connectors the key is facing the camera

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

mck1117, 2019-08-10:
IDC cables don't mirror anything.  You can route the cable in the "tab side" or the "flat side" of the connector, but that **does not** change how the connector pins map to the wires in the cable.  Don't look at which direction the cable exits the connector, look at the tab location.  The red stripe on the cable goes at the pin 1 end, which is the only thing that matters.

mck1117, 2019-08-10:
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

jharvey, 2019-08-10:
I agree with mck1117 what I was not sure about is if the cables that rusefi had were IDC cables. They are low cost china, so perhaps crimped upside down, or backwards, or some other thing. As far as I can tell it looks like the cable should not be mirroring the connector.

960, 2019-08-11:
I use these cables for much of my tuning equipment, and they never mirror anything.

Twist the cable and put the connectors next to eachother the same way, and you'll see it.

The official cortex header are the right thing to use.

rusefi, 2019-08-11:
Yes the whole mirroring is weird

My "ebay black pink" cable does not match the picture above, I assume the cable is the problem
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

mck1117, 2019-08-11:
There's no mirroring.  Pin #1 is always in the same place.  The point of an IDC cable is that you can install multiple connectors on the same cable, all with the same pinout.  Every picture you've sent shows a properly assembled IDC cable.

960, 2019-08-11:
It's just like in old stationary computers. they was full of them.

From the mainboard to the harddrives you had several connectors for HDD's, DVD-drive etc.. at the same cable

rusefi, 2019-08-11:
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

jharvey, 2019-08-11:
Per Andrey's picture, we do seem to have a problem with the ribbon cable. This is because we are flipping, while ribbon cables typically sit flat. The question is what should we do about it? Should the PCB pin out be changed to require the ribbon cable?

jharvey, 2019-08-11:
In Andrey's picture, you can see RST is flipped from the right side of the connector, to the left side. You can see the red tracer is correct, but geometry has flipped the pin out, because the connector is flipped on the other end of the ribbon cable.

jharvey, 2019-08-11:
The ribbon is presenting concerns and potentail problems. We should probably just plan for the programming header directly, with silk screen to show the key position. With some luck and with some time, this will be obsoleted any how.

jharvey, 2019-08-11:
I vote to close this one.

Closed 2019-08-11.

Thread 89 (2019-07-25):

C39 silkscreen is not clear

rusefi, 2019-07-25:
C39 is one of the capacitors where polarity matters, current silkscreen is unclear

jharvey, 2019-07-26:
C39 the dark band goes closer to the screw. This is important, as flipped wrong = explosion.

jharvey, 2019-07-29:
Silk screen has been updated to make this more clear. I believe this is closed.

rusefi, 2019-08-10:
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

Closed 2019-08-10.

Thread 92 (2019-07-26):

test pads on both sides - maybe just silkscreen?

rusefi, 2019-07-26:
At the moment we have sweet GND and 5v test pads on the front.

Technically +12 is available on the front on Q1 and C2 and etc but there is no way to know it. Maybe some silkscreen indicating the safest spot to touch +12? Maybe a pad next to Q1 or else?

On the back we technically have GND, 5v and 12v on the connector but all of these are pretty small and pretty tight so there is a huge risk of shortening things together.

Maybe a nicer pad next to +5v on connector on the back? Maybe silkscreen explaining that mounting bolts surrounds are GND so that mounting bolt surrounds are the official pad? Maybe even remove the sweet GND text pad and explain that bolt surrounds are GND?

Maybe a nicer pad next to 12v on the back?

jharvey, 2019-08-11:
Oops, I forgot to tag this when I pushed. Any how, I added these test pads, and I think this is now can be considered completed.

Closed 2019-08-11.

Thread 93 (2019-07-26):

sorta kind of backfeeding? isolation?

rusefi, 2019-07-26:
why did MRE 0.1 reboot on me while cranking? Do we have anything preventing backfeeding? isolation?

rusefi, 2019-07-28:
@mck1117 says
"re: low voltage dropouts, I removed r21, and now my board works down to 4.9 volts
it used to die at 7.9"

rusefi, 2019-08-02:
@jharvey let's remove R21?

@mck1117 says " with that resistor removed, it survived a (logged) minimum voltage of 7.6 volts"

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

jharvey, 2019-08-02:
I think R21 is valid, it's just in the wrong place on the schematic. See R107 from the reference TBOARD schematic. Notice it's on the battery side not the key side of the filtering.

rusefi, 2019-08-02:
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

rusefi, 2019-08-11:
We will see how it goes with 0.3 I guess

Closed 2019-08-11.

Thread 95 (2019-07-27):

Test MRE: Reverse-Battery Connection

rusefi, 2019-07-27:
Do we expect MRE to survive 12v connected to GND wire while +12v is ground, i.e. reverse polarity power supply?

rusefi, 2019-08-12:
Looks good https://youtu.be/wT_ztduMMyU

Closed 2019-08-12.

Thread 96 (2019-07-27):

Test MRE: supply +12v feed into +5v line

rusefi, 2019-07-27:
Do we expect MRE to survive +12 volts into +5 sensor supply line?

rusefi, 2019-07-27:
@mck1117 points at TLE8888 datasheet "8.2 5 V Main Supply
The 5 V main supply is designed to supply the ECU including microcontroller and e.g. other power chips. Out of V6V a high accurate voltage is provided at the pin V5V. The pin and the circuit is protected against overload and short circuit. For stabilization and ripple reduction an external buffer capacitor is required. For low drop operation of the regulator the pins BATPA and BATPB must be supplied."

rusefi, 2019-08-12:
Looks good https://youtu.be/wT_ztduMMyU

Closed 2019-08-12.

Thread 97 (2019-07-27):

MRE#2 has paid the ultimate price.

rusefi, 2019-07-27:
Around 9pm this Thursday microRusEfi number two has paid the ultimate price 7 minutes into real vehicle testing. Let's never forget microRusEfi number two and the two issues it might have revealed.

rusefi, 2019-08-09:
Would like this opportunity to clarify that a jumper wires was connector to GND of MRE and DMM was hooked to that jumper wire with alligator clip. There was no dragging of probes on the PCB during this event.

rusefi, 2019-08-12:
With #95 and #96 tests passing it's still a mystery what has killed TLE8888

jharvey, 2020-04-05:
This is obsolete, suggest closing this issue

Closed 2020-04-05.

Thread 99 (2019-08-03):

5v/12v option is not consistent with default naming

rusefi, 2019-08-03:
I believe the intention was for coil drivers to be hard-wired to +5 and for additional high-side to have +5v or +12v flexibility

we then had a mess with which stm32 line is wired to what output

looks like we still have some effects of this mess

also "8 channel label" on top of the PDF page is wrong, we only have 6 channels

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

mck1117, 2019-08-03:
Yes - I think a few things on the schematic are still named wrong.  I know that the default config/pin names in the `mapping.yaml` match the wiring pinout doc, so any errors are constrained to the schematic.

rusefi, 2019-08-04:
@mck1117 I believe PCB silkscreen matches schematics thus NOT matching mapping and online pinout at https://github.com/rusefi/rusefi_documentation/wiki/Hardware_microRusEfi_wiring

Open question which is the source of truth I guess

mck1117, 2019-08-04:
Oh - no idea what the silkscreen says since my v0.1 doesn't have it.  The actual PCB wiring matches the pinout at that link, at least on v0.1.

rusefi, 2019-08-11:
@jharvey schematics still says "8 channel" which is not correct

@mck1117 schematics page still shows 5v/12v on IGN pins not HS pins. This could be where we would need to change the pinout on the wiki? I am a bit confused.

rusefi, 2019-08-11:
Considering R59/R57 is wired to U31, U31 has to the HS1/HS2

U32 and U33 should be the ones COIL1/2/3/4

So open question if we move R59/R57 or change traces or change the pinout. Opinions?

rusefi, 2019-08-11:
"8 channel" is now resolved

rusefi, 2019-08-11:
@mck1117 there will be mapping yaml change to match the internal pinout change I believe

Closed 2019-08-11.

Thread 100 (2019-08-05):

silkscreen for analog#3 should be temp#3

rusefi, 2019-08-05:
analog#3 is temp#3 since this group (channels 1 to 4) has 2.7 pull-up on default BOM

jharvey, 2019-08-11:
I updated the analog net names, and PCB silk for the analog. Looks like the same should happen for the TLE8888 outputs. Those are messy and names could be more consistent.

rusefi, 2019-08-11:
pin 24 is now AT3
pin 31 is now AV3

Closed 2019-08-11.

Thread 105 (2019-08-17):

reset button

rusefi, 2019-08-17:
in my day to day workflow I need reset button - sometimes DFU fails, sometimes USB needs to be re-enumerated due to Windows7 drivers bug - in the end of the day it's annoying to remove all three sources of power for reset

would save me much time if we have an optional reset button.

can we please route the button to between flash storage ship and GND 5v test pads? maybe lower test bads a bit if needed or move test pads silkscreen?

my understanding is that reset push button would need to bring pin #14 to GND

jharvey, 2019-08-18:
Is this what you mean?

Closed 2019-08-18.

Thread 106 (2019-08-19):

[0.3.1] D1 is the hottest part of MRE - just add vias for [0.3.1]?

rusefi, 2019-08-19:
Without the rear panel D1 is 70C

With rear panel it's still 50C

@jharvey says
P-mosfet?
faster diode?
thermal via?

DonaldBecker, 2019-09-07:
It's in continuous conduction mode, so a faster diode won't help.

Any heat eliminated by using a protection MOSFET will just be moved to the V6V MOSFET.  (Which should already be burning 10x the power of the diode.)

The answer seems to be adding thermal vias and conducting heat to the case, or using a buck/buck-boost supply.

rusefi, 2020-04-09:
A lot of progress was made on 0.4.x

Closed 2020-04-09.

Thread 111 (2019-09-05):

Re-purpose one of analog inputs for 2nd channel hall input

rusefi, 2019-09-05:
at the moment we have one Hall channel and one channel which could be either VR or hall depending on what resistors are mounter.

This hardware flexibility is quite labor intense, a nicer experience could be having one more hall-only channel and leave VR channel as VR only.

This would require selecting one more ICU input pin. We totally have ICU pin options (do we?)

And technically we can confirm PAL input mode.

rusefi, 2020-02-24:
TL;DR -  the second hard-wired hall channel should be PA7 / current MRE AV3

VR input is routed to PC6 which is stm32 TIM3 or TIM8
Existing Cam is routed to PA5 which is TIM2
Following TIMs are available for ICU:

#define STM32_ICU_USE_TIM1                  TRUE
#define STM32_ICU_USE_TIM2                  TRUE
#define STM32_ICU_USE_TIM3                  TRUE
#define STM32_ICU_USE_TIM8                  TRUE
#define STM32_ICU_USE_TIM9                  TRUE

between ICU and PAL modes conflict avoidance PA7 is the best candidate to be second Hall hard-wired channel: this case PC6 could be shifted to use TIM8, PA7 would use TIM3 - so we have three ICU channels not conflicting.

Also PAL would allow PA5 PC6 and PA7 to operated simultaneously if needed.

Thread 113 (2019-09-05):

Power supply load dump protection

mck1117, 2019-09-05:
We currently have no protection against the load dump tests enumerated in ISO 16750-2 (namely the 80-100v positive pulse).

This one is pretty easy to resolve - just add a pair of back to back TVS diodes across the power input pins.

DonaldBecker, 2019-09-07:
Most alternators have load dump protection, putting the system in Test B.

My quick reading of the standard suggests that in Test B the device only needs to survive a 35V pulse.  Most of the work to do this is already designed into the TLE8888 with the specified pre-regulator.  For instance the unprotected inputs are rated to withstand 40V (which is 35V + margin).

Vehicles without load dump protection are antiques uhmm classics with period-correct parts.  For that narrow use case it's reasonable to expect the load dump protection to be external and sized to the unique requirements.  (If you want to use an original generator, ISO-16750 isn't your target.)

It's worth noting that passing the test requires the device to be at Class C or above, which means continuing to work normally after the test.  That rules out simply blowing an external fuse with a TVS (which I read as Class D) or an internal fuse or the TVS itself (Class E).  This might be a case where being "extra safe" by adding protection to an already-OK system fails the test and decreases real-life reliability.

mck1117, 2019-09-07:
Most modern alternators have load dump protection - but we can't guarantee that you're running a modern alternator.  If we were building a setup for a particular vehicle, we could put ourselves in Test B, but there are people out there already considering putting one of these in vehicles that may be old enough to not have load dump protection built in to the alternator.  For example, @ZHoob2004 has a 1970s Datsun Z car that I doubt has it, and my 1991 Volvo is probably a tossup on whether it has it.

> For that narrow use case it's reasonable to expect the load dump protection to be external and sized to the unique requirements.

Remember - the target customer here isn't an engineer, they're some random car enthusiast who might pull a 50 year old alternator out from the back of a shelf and slap it on their car (then have the battery cable fall off while driving - causing a load dump scenario).

As for actually passing Test A, the SM15T33CAY is probably all we need across the power rails to do it.  And I think we would stay class C even if fused.  The datasheet provides example voltage/current at the device for the various positive/negative load dump tests, and the peak current on any of them is for about 5 amps, for only 500us, which probably wouldn't even blow a 1A fuse.

(By the way, the C in the part number above indicates that it's two back to back diodes, so it also protects against negative pulses)

Here's app note A2689 from ST that recommends the ST15T33CAY, with some analysis about how much TVS you need: https://www.st.com/resource/en/application_note/cd00181783.pdf

mck1117, 2019-09-07:
Plus - that TVS diode is only $0.80.

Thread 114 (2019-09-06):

reverse voltage protection of TLE9201 and etc

rusefi, 2019-09-06:
DonaldBecker says "The v0.3 MRE appears to have a weakness with reverse voltage protection
(when the battery is connected in reverse, applying -12V to the +12V
circuit).

Specifically unprotected 12V power is supplied to the e-throttle TLE9201
H-bridge chip, several pins of the TLE8888  (BATPA, BATPB) and the main
capacitor.  These are not rated for negative voltage."

See https://rusefi.com/forum/viewtopic.php?p=34363#p34363

mck1117, 2019-09-07:
dupe of #112

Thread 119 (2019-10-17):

test pads for TTL pins

rusefi, 2019-10-17:
Low-probability scenario: remote tuning via a data modem, data modems probably prefer TTL RS232, can we expose test pads for one of stm32 uart devices?

DonaldBecker, 2019-10-17:
In my layout I added a 2x5 pin SMD header that brought out pins that could be mapped.

5V    12V
B8     3.3V
C11   D0
A15   C10
GND  C12

These can be mapped to:
Pin   Some interesting connections
PB8  I2C1_SCL/CAN_RX1
PC11  UART4_RX/ SPI3_MISO/USART3_RX
PD0   CAN1_RX
PA15  SPI1_NSS/ SPI3_NSS
PC10  SPI3_SCK/ UART4_TX/ USART3_TX
PC12  UART5_TX/ SPI3_MOSI/ USART3_CK

My layout should be considered a *proposal* rather than a settled design.  These are exactly the decisions that end up being "it would have been so much more useful if you made this minor change".

The intent was that this header could be used for a controlling a SPI device, adding serial communication over bluetooth or WiFi, or adding a SPI memory chip.  Note that the 8 of the pins directly map to a SPI flash pinout.

Obvious drawbacks:
- It *almost* but not quite supports dual serial ports, a second CAN channel, I2C, etc.
- It almost supports a SD card or SDIO.
- No analog input pins are provided.
- It could support I2S, but that seems useless here, unless someone uses it as a sound input for knock processing.

Note that the pads are for a 0.1" spaced header, which takes a bunch of room.  A 0.05" / 1.27mm header would allow more pins or a smaller footprint.  The header should be female to avoid pins being exposed to accidental contact, especially as 12V is on a vulnerable outside edge.

DonaldBecker, 2019-12-22:
For 0.4.6 I've updated the communication header pinout to use PB9 instead of PD0.
This allows it to support I2C or CAN (I2C Ch2 or CAN Ch1)

5V     12V
PB8   3.3V
PC11 PB9
PA15 PC10
GND PC12

Pin  Pin assignment options
PB8 I2C1_SCL/CAN1_RX
PC11 SPI3_MISO / UART4_RX/ USART3_RX
PB9 I2C1_SDA/CAN1_TX
PA15 SPI3_NSS
PC10 SPI3_SCK/ UART4_TX/ USART3_TX
PC12 SPI3_MOSI/UART5_TX/ USART3_CK

jharvey, 2020-04-05:
This is obsolete, suggest closing this issue

Closed 2020-04-05.

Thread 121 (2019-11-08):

Why are we using nonstandard debug header?

mck1117, 2019-11-08:
There exists a standard debug header that is:
- physically smaller
- industry standard (no more eBay pinout mysteries and fake programmers)
- keyed (impossible to plug in backwards)

Here's the doc on the Cortex debug headers.  We'd be interested in the "Cortex Debug Connector (10-pin)" described on page 2.
http://infocenter.arm.com/help/topic/com.arm.doc.faqs/attached/13634/cortex_debug_connectors.pdf

When the ST-LINK/V3 comes out soon, we'll be able to buy just the $11 programmer:
https://www.digikey.com/product-detail/en/stmicroelectronics/STLINK-V3MINI/497-19530-ND/10266291

Today, the connector can be used with an official ST-LINK/V2:
https://www.digikey.com/product-detail/en/stmicroelectronics/ST-LINK-V2/497-10484-ND/2214535
Plus an adapter to the 1.27mm 10-pin:
https://www.digikey.com/product-detail/en/olimex-ltd/ARM-JTAG-20-10/1188-1016-ND/3471401

mck1117, 2019-11-08:
update: Mouser has the stlink-v3 in stock!
https://www.mouser.com/ProductDetail/STMicroelectronics/STLINK-V3MINI?qs=mAH9sUMRCtvrXm%2FF%2FC0CYg%3D%3D

mck1117, 2019-11-08:
And here's an example connector we could put on the board:
https://www.digikey.com/product-detail/en/samtec-inc/FTSH-105-01-F-DV-007-K/SAM15640-ND/6693339
It's quite small, only requires around 6x7mm of board space.

DonaldBecker, 2019-11-09:
The argument for the current connector is:
   A USB dongle ST-Link v2 is $2
   The connector is inexpensive, at around $0.25
   The connector pins are enclosed, making it safe for poking around.
   Both 5V and 3.3V can be supplied through the connector, allowing a single debugging cable

The argument against is
  The footprint is huge
  Using a female header requires the ST-Link dongle to plug directly into the board
  Doubled pins are certainly not needed.

Alternative are
   Omitting programming header completely
       DFU for installation and updates is good enough for end users
   TagConnect footprint
        Tiny footprint, zero cost
         Expensive commercial cable or fiddly home built cable needed.
  Changing the suggested header to a male pins
       Inexpensive, and allows using cheap cables to the programmer
       Still the same footprint size, and exposed 5V pins sticking up is risky
   Changing the header to shrouded male pins
       Keyed ribbon cable to avoid reverse connection, mitigates exposed pins, inexpensive
       Effectively even bigger footprint (no flat components allowed in surrounding area)
   3 or 4 pin SWD header in the Discovery board pattern
         Inexpensive, smaller, does everything
   Standard JTAG, 2.54 or 1.27 spacing
          More pins, none of which add value
   ST-Link v3 header
          Programmer is only about $10
          Expensive header $3.20 ea
          Very little benefit for extra pins
          Very new and still uncommon

Right now I'm leaning to a 3 or 4 pin SWD only connector, with a leg-less TagConnect footprint.
Perhaps with a 2x2 SMD pin header rather than the 1x4 Discovery header for space savings
That provides almost complete debugging at minimal cost, usable with the existing ST-Link debuggers.

jharvey, 2020-04-05:
This is obsolete, suggest closing this issue. We appear to have both standard and less standard programming headers now.

mck1117, 2020-04-05:
We have 10 pin cortex now?

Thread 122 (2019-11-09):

MRE 0.4.5 issues list

rusefi, 2019-11-09:
@DonaldBecker  says

Correct mixed-up Vref/Vbatt/AV4/AV5 inputs
Put USB Vbus on a regular diode clamp pin, not +V.  Perhaps +V should be the 5V rail.
Select a different micro USB connector, with easier access to pads for soldering and inspection.
Rotate USB connector to follow wide-side-down orientation expectations.
Move components away from USB connector soldering path
Move SWD connector 1mm away from USB.
Move Reset button adjacent to Program button
Consider a different push button, with extending SMD leads for easier inspection.
Add Tag-connect programming pads
Add diode and pull-up to LIN circuit.
More DFB pins and/or power outputs connected to inputs
Clear solder mask from bottom layer under TLE thermal pad, remove thermal breaks.
Plated-through mounting holes.
Tweak layout to optimize for possible ground current from TLE8888 to mounting holes.
Increase drill size for SIP outputs, check footprint for headers
Standby power diode mixing

rusefi, 2020-05-24:
we are on 0.5.1 so I assume most is handled?

Closed 2020-05-24.

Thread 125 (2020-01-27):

[0.4.7] dual-footprint for push buttons

rusefi, 2020-01-27:
for sake of flexibility we can support both 3*6*2.5 and previous smaller buttons like used on 0.4.5 on the same PCB

jharvey, 2020-04-05:
This is obsolete, suggest closing this issue

Closed 2020-04-05.

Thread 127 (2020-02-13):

[0.4.7] VRef drama continues

rusefi, 2020-02-13:
JP1 to vref with 6.8K/10K divider is not happy :( vref point measures 2.48 not expected 2.99

@mck1117 says "0.5v thru a 6.8k resistor is 75uA

Typical draw on vref during ADC conversion is 300uA"

rusefi, 2020-03-18:
0.4.7 has a minor mistake that the wrong side of that jumper is the default

it should be cut & soldered/jumpered to the "vdda" side

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

rusefi, 2020-03-26:
@mck1117 says "I'd just toss it
Just tie vref to avdd, no jumper"

jharvey, 2020-04-05:
This is obsolete, suggest closing this issue

Closed 2020-04-05.

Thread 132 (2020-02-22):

Replace VR silk with Hall

rusefi, 2020-02-22:
On the back we have "VR" silkscreen placed next to three resistors which are only used in Hall mode

We also have two resistors which are only used on VR mode without a silk.

Can we please replace "VR" word with "Hall" and add "VR" lower?

See https://github.com/rusefi/rusefi_documentation/wiki/Hardware/microrusefi/Hardware_microRusEfi_0.4.7_vr_back.jpg

See https://github.com/rusefi/rusefi_documentation/wiki/Hardware_microRusEfi_kit_instructions

rusefi, 2020-03-03:
pushed into 0.4.8

Closed 2020-03-03.

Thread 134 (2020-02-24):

Remove all back side BAS70-04

rusefi, 2020-02-24:
43;"D10,D26,D25,D24,D18,D12,D11,D9,D8,D7,D6,D5,D4,D3";"SOT-23";14;"BAS70-04";;;

was it replaced by

16;"D39,D13,D38,D40,D16";"SOT-23-6";5;"SRV05-4";;;
?

rusefi, 2020-02-24:
@DonaldBecker @mck1117 @anreika-git @dron-gus @jharvey opinions?

rusefi, 2020-02-24:
If we still node those shall we migrate to smaller footprint PN?

sot323 - also called sc-70

https://lcsc.com/product-detail/Schottky-Barrier-Diodes-SBD_DIODES_BAS70W-04-7-F_BAS70W-04-7-F_C134389.html
or
https://lcsc.com/product-detail/Schottky-Barrier-Diodes-SBD_DIODES_BAS70W-04-7-F_BAS70W-04-7-F_C134389.html

mck1117, 2020-02-24:
here's how to test it:
1. supply normal power to board
2. connect +12v to analog input, measure voltage on the ECU-side of the 10k dropper resistor:
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
(apply 12v to left arrow, measure at right arrow)
3. If the voltage is below ~6 volts, then the diodes work great.  If the diodes or opamps release smoke, the diodes do not work great.

rusefi, 2020-02-25:
@DonaldBecker says "I was unable to kill the board without the bottom layer protection installed.
Using the 3peak opamps, with higher allowed injection current, should mean that we might not even need the srv05 diodes on the top layer, but those are not large or expensive.

Injection current test was at 15.0V

With is a 10.0V drop across the input diodes to the 5.0V opamp power rail.

Presumably we only need to support 14.0V, but it's easier to do the math with 15.0V.  Realistically we don't need to support dynamic faults when the alternator is running overvoltage, just installation errors."

rusefi, 2020-02-25:
@DonaldBecker says "I was unable to kill the board without the bottom layer protection installed.
Using the 3peak opamps, with higher allowed injection current, should mean that we might not even need the srv05 diodes on the top layer, but those are not large or expensive.

Injection current test was at 15.0V

With is a 10.0V drop across the input diodes to the 5.0V opamp power rail.

Presumably we only need to support 14.0V, but it's easier to do the math with 15.0V.  Realistically we don't need to support dynamic faults when the alternator is running overvoltage, just installation errors."

rusefi, 2020-02-25:
Sweet, so we go forward with removal of

43;"D10,D26,D25,D24,D18,D12,D11,D9,D8,D7,D6,D5,D4,D3";"SOT-23";14;"BAS70-04";;;

jharvey, 2020-04-05:
This is obsolete, suggest closing this issue

Closed 2020-04-05.

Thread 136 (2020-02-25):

Research what else could be JLCPCB-assembled

rusefi, 2020-02-25:
Are there any https://lcsc.com/ components to use in place of
D2?
Q1?
etc everything else red

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

rusefi, 2020-02-25:
@DonaldBecker says

"D2 is the optional TVS for the CAN bus.  It isn't really needed.  It might protect against a lightning strike, but it would just save that part of the chip as everything else blows up.

Q1 is the pre-regulator MOSFET.   We are using the one specified and characterized for the TLE8888.  Presumably any similar part would work, but we can't calculate the stability without access to the proprietary info about the feedback.  It's $1-ish and easy enough to solder, so it doesn't strike me as a good part to substitute."

mck1117, 2020-03-30:
We can install C133648 as D41.  It's technically optional for normal operation, but the board might explode without it in case of an alternator load dump (battery disconnected from alternator while charging).  A racecar kill switch can do this, for example.

rusefillc, 2020-07-31:
Looks like we are in a great spot with pre-assembly at this point

Closed 2020-07-31.

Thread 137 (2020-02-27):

Functional test board PCB - with pigtail

rusefi, 2020-02-27:
it would be nice to replace hand-made test board with a proper PCB

0) the board should accept wires from 48 pin pigtail
1) the board would need a few LEDs to indicate 5v & 12v
2) the board should have LEDs to test all MRE outputs
3) the board should have buttons to test CAM inputs
4) the board should have some resistor dividers to test analog inputs

rusefi, 2020-02-27:
Current state of this (shown one of two boards, complete test jig takes two boards at the moment, each board with 24 wires)

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

rusefi, 2020-03-07:
See also #140

rusefillc, 2021-02-07:
done

Closed 2021-02-07.

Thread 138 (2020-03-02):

Low-profile MRE

rusefi, 2020-03-02:
For some PnP applications we want MRE to be very slim.

2x5 headers and even vertical USB connectors are not really required. The tallest required component is 100uF 50V C2 - on my boars right now it's 10mm tall.

Would EMZR500ADA101MF80G work?  Shall we make rusEfi accept this footprint?
100 uF 50V
6.6x6.6mm
Height: 7.7 mm

Do we require 50V? Do we have options slimmer than 7.7mm?

rusefi, 2020-03-02:
40+ volts Tantalum Capacitors cost $30 that's not an option :(

rusefi, 2020-03-02:
Tantalum for reasonable money means 35volts
For example T52M1107M035C0055 $4
Tantalum Capacitors - Polymer SMD 100uF 35volts 20% 55mohms maxESR

rusefi, 2020-03-02:
@mck1117 says "The trouble with tantalum is that if you overvolt them even once, they can fail with a short, and then LITERALLY EXPLODE the next time power is applied "

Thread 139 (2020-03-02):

0.4.8 JLCPCB DFM Report

rusefi, 2020-03-02:
C11 | Yes | C53987 | Guangdong Fenghua Advanced Tech 0603B472K500NT | 0603 | Cannot find this Pad in your PCB
-- | -- | -- | -- | -- | --
R121 | Yes | C17901 | Uniroyal Elec 1206W4F1000T5E | 1206 | Cannot find this Pad in your PCB
R123 | Yes | C17901 | Uniroyal Elec 1206W4F1000T5E | 1206 | Cannot find this Pad in your PCB
D27 | Yes | C2296 | Hubei KENTO Elec 17-21SUYC/TR8 | LED_0805 | Cannot find this Pad in your PCB
FB1 | Yes | C1034 | Sunlord SDFL1608Q4R7KTF | 0603 | Cannot find this Pad in your PCB
R125 | Yes | C17901 | Uniroyal Elec 1206W4F1000T5E | 1206 | Cannot find this Pad in your PCB
C41 | Yes | C23630 | Samsung Electro-Mechanics CL10A225KO8NNNC | 0603 | Cannot find this Pad in your PCB
U1 | Yes | C12345 | STMicroelectronics STM32F407VGT6 | LQFP-100_14.0x14.0x0.5P | Cannot find this Pad in your PCB
R34 | Yes | C23178 | Uniroyal Elec 0603WAF4703T5E | 0603 | Cannot find this Pad in your PCB
R77 | Yes | C25804 | Uniroyal Elec 0603WAF1002T5E | 0603 | Cannot find this Pad in your PCB
R62 | Yes | C25804 | Uniroyal Elec 0603WAF1002T5E | 0603 | Cannot find this Pad in your PCB
R63 | Yes | C25804 | Uniroyal Elec 0603WAF1002T5E | 0603 | Cannot find this Pad in your PCB
R76 | Yes | C25804 | Uniroyal Elec 0603WAF1002T5E | 0603 | Cannot find this Pad in your PCB
C2 | Yes | C134515 | Lelon VZH101M1HTR-0810L | SMD-ECAP-8x10 | Pad to Pad Spacing is too large
RN1 | Yes | C20197 | Uniroyal Elec 4D03WGJ0102T5E | 0603_x4 | Soldering area is too small
RN2 | Yes | C29718 | Uniroyal Elec 4D03WGJ0103T5E | 0603_x4 | Soldering area is too small
RN13 | Yes | C29718 | Uniroyal Elec 4D03WGJ0103T5E | 0603_x4 | Soldering area is too small
RN4 | Yes | C29718 | Uniroyal Elec 4D03WGJ0103T5E | 0603_x4 | Soldering area is too small
RN6 | Yes | C29718 | Uniroyal Elec 4D03WGJ0103T5E | 0603_x4 | Soldering area is too small
RN3 | Yes | C29718 | Uniroyal Elec 4D03WGJ0103T5E | 0603_x4 | Soldering area is too small
RN5 | Yes | C29718 | Uniroyal Elec 4D03WGJ0103T5E | 0603_x4 | Soldering area is too small

rusefi, 2020-03-02:
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

rusefi, 2020-03-02:
Simon says D16 rotated 180 deg
Simon says D19 gets a little wider

rusefi, 2020-03-03:
Just checked with 0.4.7 - yes, D16 needs to be flipped. Correct file is how the boards I have look like.

cocamousse, 2020-03-05:
Side note on C2, with a slight board change from the original 8*10.5 footprint to a 8*10 footprint you can use JLCPCB components. Guessing you know, just pointing it out.

rusefi, 2020-03-05:
@cocamousse please note how these pictures show C2 in black and for example SW2 not black

C2 in black means we already use C2 from JLCPCB components :)

cocamousse, 2020-03-05:
ah, sorry about that, I was looking at the report in the first post.

rusefi, 2020-05-24:
Seems like not an issue now

Closed 2020-05-24.

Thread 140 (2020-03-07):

Functional test board PCB - without pigtail

rusefi, 2020-03-07:
1) 2x12v red LEDs

2) 2x5v LEDs

3) a fuse (see Frankenso part - I have those)

4) x8 low side LEDs

5) x6 high-side LEDs

6) 5.5mm barrel jack is what I use for those

rusefi, 2020-03-07:
Need to find larger pogo pins - current pins are smaller than connector holes on microRusEfi

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

rusefi, 2020-03-07:
LED board would use same footprint as real MRE board

the idea is for LED board to use #6 bolts in order to sit on the board being test - #6 bolts match the mounting holes perfectly

MRE would stimulate itself and output low-side injector and high-side ignition signals. LED board should display those outputs using LEDs

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

rusefi, 2020-03-10:
P100-E2 pogo pins seem relevant

rusefi, 2020-05-11:
There is a plan to make progress at https://github.com/rusefi/hw_microRusEfi/tree/master/test_fixture

@jharvey is on the job!

rusefillc, 2021-02-07:
done

Closed 2021-02-07.

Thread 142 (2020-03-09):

pads for SMD coin battery on the back

rusefi, 2020-03-09:
Shall we allow soldering of CR2016-MFR-SM on the back?

CR2016-MFR-SM costs $1 from Mouser

Better ideas?

rusefi, 2020-03-10:
RecaroRacer will try 2 pin angled connector Molex 53048-0210 since there seem to be wired cr2016 on eBay

jharvey, 2020-04-05:
Is the 2 pin connector OK? The 2 pin connector has been added, so this can probably be closed.

jharvey, 2020-04-27:
2 pin connector was decided upon, this can be closed.

Closed 2020-04-27.

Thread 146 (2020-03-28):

Do we really want to sense vBatt on the main relay pin?

mck1117, 2020-03-28:
Currently we sense from the main relay pin (pin 1), which is *technically* optional to use.  That can cause user confusion for the case of "I wired power and ground, why doesn't my ECU show voltage?"

rusefi, 2020-06-08:
Let's abort? looks like there are benefits to this setup as well.

at the moment we only invoke tle8888 initialization once we get +12 from MR.

Closed 2020-06-08.

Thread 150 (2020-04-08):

Correct pair.sch wanted

dron0gus, 2020-04-08:
Currently added (by me) contain additional components (clamp diodes, indication LED, pull-down and serial resistors).
Either correct one should be added (by who?).
Or current one should be adjusted to align with PCB.

jharvey, 2020-04-27:
This was corrected in R0.5.0 this can be closed.

Closed 2020-04-27.

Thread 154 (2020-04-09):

External +5v power source

rusefi, 2020-04-09:
At the moment we have USB on the 48 pin but we cannot feed +5v into MRE via the connector

this is forcing users to power from +12v which is not safe for firmware flashing

is there any chance to allow external +5v into MRE?

dron0gus, 2020-04-09:
Use one of analog inputs to feed USB 5V? Through diode to avoid influence during normal operation? Diode can also be used as jumper - it can be removed if user wants analog functionality only.

rusefi, 2020-04-12:
how about AV10?
1. i like that it's on the edge pin on the connector
2. I like "10" as in "often not used"

rusefi, 2020-05-24:
we have this on 0.5.0

so far I believe this was NOT tested

rusefi, 2020-07-10:
looks like this works

Closed 2020-07-10.

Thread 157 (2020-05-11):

RED FATAL/CRITICAL LED is a bit dim when it should be OFF

rusefi, 2020-05-11:
MRE has 4 status LED

somehow WARNING and RUN are properly totally OFF while FATAL/CRITICAL is a bit dim while should also be completely OFF

is this HW or SW issue?

dron0gus, 2020-05-11:
At early init code all pins are set to default mode (input mode with pull-up enabled).
Pull-up current is enough to light LED a bit.
Later some LEDs gpios reconfigured to output mode. Red led is not used and left as is.
Same thing cause all injectors channels to be activated for a few hundred mS during board boot/reset. This issue is HW fixed for 0.5.0 and need SW fix for <= 0.4.9

rusefi, 2020-05-11:
But we have
```#if EFI_PROD_CODE
	enginePins.errorLedPin.initPin("led: ERROR status", LED_ERROR_BRAIN_PIN);
	errorLedPort = getHwPort("primary", LED_ERROR_BRAIN_PIN);
	errorLedPin = getHwPin("primary", LED_ERROR_BRAIN_PIN);
#endif /* EFI_PROD_CODE */
```

is not that addressing the issue?

just to confirm - we are talking about long-term dim, not just quick start-up dim

dron0gus, 2020-05-11:
```
grep LED_ERROR_BRAIN_PIN -R ./config/
./config/boards/skeleton/efifeatures.h:#ifndef LED_ERROR_BRAIN_PIN
./config/boards/skeleton/efifeatures.h:#define LED_ERROR_BRAIN_PIN GPIOD_14
./config/boards/kinetis/efifeatures.h:#define LED_ERROR_BRAIN_PIN GPIOD_14
./config/boards/prometheus/efifeatures.h:#undef LED_ERROR_BRAIN_PIN
./config/boards/prometheus/efifeatures.h:#define LED_ERROR_BRAIN_PIN GPIOA_13
./config/stm32f4ems/efifeatures.h:#ifndef LED_ERROR_BRAIN_PIN
./config/stm32f4ems/efifeatures.h:#define LED_ERROR_BRAIN_PIN GPIOD_14
```
None of these is GPIOE_3 as it should be for MRE.
But:
```
dron@DronG:/home/work/rusefi/rusefi/firmware$ grep GPIOE_3 -R ./config/
./config/boards/microrusefi/board_configuration.cpp:	//engineConfiguration->atalErrorPin = GPIOE_3;		// d21 = red
./config/boards/microrusefi/board.mk:  EFI_FATAL_ERROR_PIN = -DEFI_FATAL_ERROR_PIN=GPIOE_3
```
Unfortunately EFI_FATAL_ERROR_PIN is not used anywhere in code.

rusefi, 2020-05-11:
Wow great find @dron0gus ! let me fix that

Closed 2020-05-11.

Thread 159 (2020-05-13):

text fixtures: move resistors from under the board

rusefi, 2020-05-13:
can we please move all analog stuff (and all stuff) outside of MRE outline to allow poking with a probe while MRE is snapped it

jharvey, 2020-05-14:
These were moved outside of MRE outline.

Closed 2020-05-14.

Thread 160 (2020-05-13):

text fixtures: buttons should have through-hole option or same as MRE

rusefi, 2020-05-13:
at the moment text fixture uses some unique button footprint

let's share footprint with MRE or better allow through-hole option. I suspect that my through-hole push buttons are 0.2x0.2 inch pattern

jharvey, 2020-05-13:
??? thru hole PB ???

rusefi, 2020-05-14:
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
@

rusefi, 2020-05-14:
that's the button from rusEFI 100 pin brain board

jharvey, 2020-05-14:
I see schematic for TL1105 found here https://sten-eswitch-13110800-production.s3.amazonaws.com/system/asset/product_line/data_sheet/144/TL1105.pdf

I see KICAD footprint Button_Switch_THT:SW_TH_Tactile_Omron_B3F-10xx appears to be proper. But I do not see a symbol for it that matches the above. It looks like a symbol would need to be created.

rusefi, 2020-05-14:
https://github.com/rusefi/rusefi/tree/master/hardware/brain_board is rusEFI hardware which uses that exact button

rusefi, 2020-05-14:
this is less important since JLC will mount SMD toggle switches for us

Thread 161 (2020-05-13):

text fixtures: power some low-side LEDs from sensor 5v output

rusefi, 2020-05-13:
don't power all low-side from +12v

power some of them from each of the 5v sensor supply outputs from MRE

that way we can test two birds with one stone

rusefi, 2020-05-14:
we have resistors from 5v1 i guess more or less same idea, shall we close?

rusefi, 2020-05-24:
@jharvey what's the status?

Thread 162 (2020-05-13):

test fixture: why are there two sets of LED for main relay?

mck1117, 2020-05-13:
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

Main relay is a lowside output.  So what are the left set doing (R11/D21/D20)?

rusefi, 2020-05-13:
@mck1117 D22 is not MR, D22 is aux low side on AV10

but MR has to become low side that's for sure

mck1117, 2020-05-13:
oh, oops, misread which wire that was.  But yes, the point stands, MR should be low side like the others over on the right.

jharvey, 2020-05-14:
This was updated on R0.1 release. Just noticed the issue tracker now. Sorry no git link to specific rev that fixed this.

Closed 2020-05-14.

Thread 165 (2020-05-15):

Maybe go back to original USB connector

rusefi, 2020-05-15:
0.1 to 0.4.6 or 0.4.7 used one connector

with 0.4.7 @DonaldBecker has switched part number see https://github.com/rusefi/hw_microRusEfi/commit/8ef83eb0126df593adba10446c40f990759f1c9b

rusefi, 2020-05-15:
the complaint about Wuerth is 1mm lead length i.e. harder to solder into 1.6 pcb

and at some point Wuerth was not available on Moused which has triggered us to look at Digikey which suggested GCT as "similar option" and we got hooked on 1.6mm lead length.

rusefi, 2020-05-15:
Maybe we should even switch to mini USB since these are sturdier for vertical mount?

rusefi, 2020-05-17:
Two votes against USB-C due to soldering complexity.

rusefi, 2020-05-17:
@mck1117 points at https://lcsc.com/product-detail/USB-Connectors_Jing-Extension-of-the-Electronic-Co-Jing-Extension-of-the-Electronic-Co-TYPE-CFemale-14PIN-DIP_C168704.html  C168704

rusefi, 2020-06-20:
https://rusefi.com/forum/viewtopic.php?f=4&t=1730 was a failure of GCT

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

rusefi, 2020-06-21:
Would Lcsc mini usb Part C46396 fit existing footprint?

rusefi, 2020-07-06:
random eBay vertical mini USB - footprint is similar style to what we use but larger spacing between pins

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

jharvey, 2020-07-06:
Can we find a digikey equiv of that thru hole USBC connector? I like USBC as it's more robust and it's not "obsolete". If not then can we find a USB Mini from both Digikey and cheap alternative like ebay or LSCS.

rusefi, 2020-07-06:
@jharvey 732-8218-1-ND looks very very different from out current style

if it would be a 24 pin connector I would be worried about soldering

at this point going back to mini seems to be the safest option

rusefi, 2020-07-06:
How about UE25BE55100 ? I wonder if the pinout is similar in terms of which pin is located where

rusefi, 2020-07-06:
@jharvey what about Frankenso vertical pinout?

I believe Frankenso vertical Mini USB has pins in the same positions

footprint does not match, we either need to make holes a bit larger or just switch

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

jharvey, 2020-07-07:
How about that universal one we once were developing? It would look like this.
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

stefanst, 2020-07-12:
Vote against vertical mount Micro-USB. Mine has failed after frequent use. There was, however, no undue ABUSE. Just plugging, unplugging a few hundred times. Each time likely bending the connector slightly.  Any connector without WIDE solder tabs will fail after a time, especially if installed vertically which exacerbates bending moments.
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

rusefi, 2020-07-12:
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

rusefi, 2020-07-12:
it's GCT which has failed

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

rusefillc, 2020-07-21:
USB-C option:
Dimitri C says "LCSC C168704
It's actually 14 pins now that i looked at it but fairly easy to solder.

It's 7 pins X2 for each side"

rusefillc, 2020-07-24:
0.5.2 with miniUSB

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

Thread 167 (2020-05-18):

BOM issues

rusefi, 2020-05-18:
CC0603CRNPO9BN4R7,18pF Capacitor_SMD:C_0603_1608Metric C1647,"C22,C21",2.0,"Part number is 4.7uF, description is 18pF
  
C1608X5R1E106M080AC,22uF 25V Capacitor_SMD:C_0805_2012Metric TDK 445-9015-1-ND C45783,C43,1.0,"Part number is 10uF, description is 22pF"

LTST-C193TBKT-5A,LED-RED LED_SMD:LED_0603_1608Metric Lite-On 160-1827-1-ND C2286,"D28,D35,D33,D31,D29,D19",6.0,"The Part number is Blue, description is Red
 
RMCF0603JJ1K00,n.a. 0R Resistor_SMD:R_0603_1608Metric StackPole RMCF0603JJ1K00CT-ND C21190,R2,1.0,The Part number is 1K, description is 0R, please help comment.

RMCF0603JJ1K00,0R Resistor_SMD:R_0603_1608Metric StackPole RMCF0603JJ1K00CT-ND C21190,"R21,R33,R80,R81",4.0,1K В±1% 0603 UniOhm?

rusefi, 2020-05-24:
Some progress was made here

Closed 2020-05-24.

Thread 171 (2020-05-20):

VR input: R9 and R15 useful or not?

rusefi, 2020-05-20:
R9=R15 DNP = more sensitive

both R9 and R15 in place = lower signal level, possibly necessary for extremely hot sensors

Matthew Kennedy  says:
I have no data to support that they are required since the tle8888 has internal clamp diodes to prevent overvoltage
so I might even go so far as to say that we should just remove them
the tle8888 datasheet application diagrams don't mention having a resistor there
I have no idea why we have them honestly

jharvey, 2020-05-23:
Perhaps change for TVS diodes, that kick in when above a specific voltage, then they don't attenuate when low RPM. Very similar to the 8888's internal TVS. The "VR Sensor Interface Input Clamping Voltage" is as low as 2V, and "VR Sensor Interface Input Clamping Current" is a max of 50mA. I see 3.3V TVS are available from JLC, perhaps we can find a lower voltage diode. https://datasheet.lcsc.com/szlcsc/ProTek-Devices-PSD03-LF-T7_C139297.pdf

rusefi, 2020-06-08:
let's just DNP R9 and R15?

rusefi, 2020-06-13:
it was decided not to populate R9 and R15

see also #178

rusefillc, 2020-07-27:
0.5.2 was fabricated without R15 but with R9

i think that's similar to the R2 issue, we need to DNP R9 a bit more :) @jharvey

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

Qwerty-OFF, 2022-04-23:
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

Closed 2022-04-23.

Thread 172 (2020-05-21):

test board I had: wire buttons to the analog inputs

rusefi, 2020-05-21:
@mck1117 says "one idea I had for a test board I had: wire buttons to the analog inputs, and LEDs to outputs.  Write firmware that just reads inputs and writes them to each output,  That way you can just press buttons and make sure exactly one LED turns on."

we have the outputs. We have JLC soldering switches for us. I think that's a great idea!!!

mck1117, 2020-05-21:
Another more fully fleshed-out option for this is to have a second MCU and CAN interface on the test board.  The ECU-under-test can accept commands to toggle outputs over CAN, whole broadcasting the state of the inputs.  Test board MCU applies stimulus (analog input voltage, digital inputs, crank/cam signal), and checks that CAN reports the right thing.  Then the test MCU can toggle each output over CAN, checking that the pin changes as expected.  That way we could just turn on a single green light that says "board ok" instead of having to check every output manually.

mck1117, 2020-05-21:
(but that's of course a bunch more work, and only a required thing at scale)

jharvey, 2020-05-21:
I tend to think pre-programmed chip like the one found on the discovery. Let is automagically smash a program into MRE and do some tests.

jharvey, 2020-05-23:
Why not connect outputs, to inputs and let the MRE push the buttons? Similar to AV6, AV8, AV9, and AV10.

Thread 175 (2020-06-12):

Mark R2 DNP

rusefi, 2020-06-12:
R2 watchdog connect is preventing stm32 from start unless we have tle8888 powered via +12v

let's DNP R2 for now

rusefi, 2020-07-10:
@jharvey could this be closed?

jharvey, 2020-07-22:
Hmmmm, I see
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
However the BOM comes out like this.
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

reportingsjr, 2020-07-24:
This is an issue with your BOM script, not with KiCad.
If you look at the BOM script it is grouping components only by footprint type and value, hence why it is grouping your DNP resistor in there.

Change the R2 value to DNP and I bet it will separate it out.

I do wish KiCad had some other default fields like DNP so scripts could be more consistent on this!

jharvey, 2020-07-27:
Made "0R" into "0R DNP" This now should work long term.

MHTSOSVOODOO, 2020-07-29:
We could replace R2 with a diode with the cathode pointing towards the reset button. This way you can still reset TLE8888 when you press the button but it can't pull the reset line to ground when 12V is missing. I tried it and it seems to work.

Closed 2020-07-27.

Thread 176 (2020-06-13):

[test fixture] wiring usability

rusefi, 2020-06-13:
pigtail has many short wires so from mechanical side of things at the moment it's tempting to mount it on the back side of the PCB - this case all wires are running parallel and there is no mechanical tention

this is not user friendly since board is not sitting flat on the bench and things are loose in the air.

rusefi, 2020-06-13:
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

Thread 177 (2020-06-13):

[test fixture] crank testing: hall? VR?

rusefi, 2020-06-13:
for hall crank sensor with a pull-up test button schematics should be just a button to GND without resistors.

open question if current schematics works to test VR

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

jharvey, 2020-08-03:
Please review did I do this how we prefer?

Closed 2020-08-04.

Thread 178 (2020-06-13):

Hall input: do we need R18=R19=4.7K? keep C12 & C35?

rusefi, 2020-06-13:
Would TLE8888 in Hall mode allow us to drop R18=R19 altogether?

In order to reduce HW difference between hall and VR modes can we keep C12 & C35 while running in Hall mode?

rusefi, 2020-06-17:
My NB2 miata has just started without R18 and R19

stwillocks, 2022-04-23:
I have 2 seperate MRE with 202204 pre release firmware

MRE1=R9,C12,C35,R15 NOT populated & R19,R17,R18 populated
MRE2=R9,C12, C35, R17,R18,R19 populated

MRE2 works but sens trigger error at certain RPMs.
At 2k-2.5k trigger error but it has continuity
At 4k RPM with low throttle it stucks at 4k but with full throttle it gets over 4k but stucks 6.4k RPM

MRE1 revs up all the way to 6.4k but while deceleration it gives trg error at 4k. and mixing signals

rusefillc, 2022-04-23:
MRE2 with all populated is pretty strange see https://github.com/rusefi/rusefi/wiki/Hardware-microRusEFI-kit-instructions

stwillocks, 2022-04-23:
I have slightly wiggle at crank trigger wheel, which i discovered recently, I believe it caused "~4k trg error"s. Monday I am going to get the wheel machined and balanced then try different combinations, will post logs & results.  BTW thanks for notation.

rusefillc, 2022-04-23:
#223 says hi

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

rusefillc, 2025-08-05:
See also https://github.com/rusefi/rusefi/wiki/Hardware-microRusEFI-kit-instructions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

rusefillc, 2025-08-05:
We are good with https://github.com/rusefi/hw_microRusEfi/issues/236 BOM

Closed 2025-08-05.

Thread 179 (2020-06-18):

[test fixture] [IMPORTANT] J2 is flipped

rusefi, 2020-06-18:
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

GND and 3v

5v and etc - a lot of stuff is flipped

rusefi, 2020-06-18:
@stefanst FYI do NOT solder J2 bottom header on test fixture

@jharvey Houston we have a problem

jharvey, 2020-07-28:
Can I get a confirmation that this is completed? I think I already completed this one.

rusefillc, 2020-07-31:
Looks resolved, closing

Closed 2020-07-31.

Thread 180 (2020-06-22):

pin contention - TLE8888 + CS + BT

rusefi, 2020-06-22:
TL,DR: do we have ANOTHER set of UART pins exposed on MRE not PC10&PC11?

How do we get MRE to
1) obviously keep using SPI for TLE8888
2) have different SPI for SD card
3) and also have UART for Bluetooth?

TLE8888 uses TBD pins which conveniently could be multiplexed to SPI1 or SPI3
SD card ideally should be running on a different SPI to reduce contention. We have complete SPI exposed which uses PC10&PC11

so if PC10 and PC11 is used by SPI for SD, do we have another pair of pins exposed on all the little random vias? if not, what would be the minimal HW change to have uart exposed without sharing pins with SPI?

rusefi, 2020-06-22:
@ksmola since you did UART recently poke :)

rusefi, 2020-06-22:
see table on the bottom of https://github.com/rusefi/rusefi/wiki/Hardware_microRusEfi_wiring

rusefi, 2020-06-24:
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

rusefi, 2020-06-24:
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

how about PB10 & PB11 which are used for SPI Flash right now? Does SPI use them simply as GPIO?

jharvey, 2020-07-06:
I'm not following the request. Is this correct?
PB10 on SD card --> PE0
PB11 on SD card --> PC13
Then we want
PB10 to a via for UART via soldered wire
PB11 to a via for UART via soldered wire

rusefi, 2020-07-06:
The request:
before the change PB10 PB11 were routed to SPI Flash (not SD card)
PE0 PC13 were available to outside world via VIAs

The request:
swap pin usage. use PE0 PC13 to control SPI Flash
make PB10 PB11 available to outside world via VIAs

@jharvey

jharvey, 2020-07-06:
My key concern is if PE0 or PC13 should be connected to the flash traced called HOLD? I have committed a draft copy. Did I get the correct signal to the correct pin? If they are flipped does that matter? Is the PCB as it's drawn now correct and ready for MFG files?

rusefi, 2020-07-06:
Does not matter which one is which, it's GPIO so full programmatic control

jharvey, 2020-07-06:
Thanks for the verification. This is routed, so we can close it.

rusefi, 2020-07-14:
Before the change, 0.5.1 and older

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

Closed 2020-07-06.

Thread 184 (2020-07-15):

Resistors R14, R23, R25 and R27 are wrong size in BOM - those are 2.7K pull ups on temperature sensor inputs

MHTSOSVOODOO, 2020-07-15:
Resistors R14/R23 and R25/R27 are 0603 in BOM and 0402 in board and on JLC assembled boards one or both sides of the resistors are shorted.
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

rusefi, 2020-07-15:
@jharvey what is the risk here? the v8 engine John has this board on the way to him

jharvey, 2020-07-22:
BOMs are updated. We can close now.

jharvey, 2020-08-08:
To many extended parts, need more basic parts
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

jharvey, 2020-08-08:
Updated footprints to 0603, moved traces now closed again.

Closed 2020-08-08.

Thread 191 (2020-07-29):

[0.5.1] solder mask around the screw hole exposes some tracks. issue or not?

rusefillc, 2020-07-29:
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

rusefillc, 2020-07-29:
@jharvey says "Those traces push out of the way no problem. So it can be fixed easily enough. Keep in mind the OEM case that side of the PCB around like 90% touches metal, so it needs the sheet of plastic to keep it separated."

@ksmola can I bother you with this?

Closed 2020-08-06.

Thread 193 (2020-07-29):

REVIEW 0.5.3

rusefillc, 2020-07-29:
We need to get a stable functional MRE

We have fixed trace interconnect of 0.5.2b and improved #191

@mck1117 can you please review current schematics and PCB?

rusefillc, 2020-08-06:
@mck1117 says "I had a once over the current master of MRE and I don't see anything obviously wrong"

Closed 2020-08-06.

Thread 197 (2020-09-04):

Resistors in between header pins are a terrible PITA

stefanst, 2020-09-04:
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
Tiny little components placed between header pins are terrible for hand-soldering the pins.
35 was connected to R54 and R52 (GND). Fortunately it's a low-side output, so short to GND didn't kill anything. I hope nothing died on any of the other boards. At least I didn't smell anything.
The gap is just way to small for something that's supposed to be hand-soldered.
I understand that this solution is clever, but it kills assembly of the boards. I have to go over each board of the 5 assembled now with a microscope and see where they're bridging. And then try to remove the bridges very carefully with thin braid and a skinny tip.
I'm sure we can find some other space on this board to place those resistors. There should be no components in between those header pins.

JRDMcLAREN, 2021-12-27:
Can I try to do something with this .?
Is any space on bottom side on ALU case .? (asume yes)

JRDMcLAREN, 2022-01-03:
Done in my RC2 - https://github.com/JRDMcLAREN/hw_microRusEfi https://rusefi.com/forum/viewtopic.php?p=43789#p43789

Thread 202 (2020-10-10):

One test board CLT or AuxT#1 randomly goes to zero volts

rusefillc, 2020-10-10:
Something unusual happens with one MRE board - it randomly goes to report 0v during QC test on either CLT or AuxT#1 input

rusefillc, 2020-10-12:
this was a SW issue https://github.com/rusefi/rusefi/issues/1873

Closed 2020-10-12.

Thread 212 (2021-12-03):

Chip Shortage: TLE8888 options

rusefillc, 2021-12-03:
https://octopart.com/search?q=TLE8888

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

rusefillc, 2021-12-25:
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

rusefillc, 2022-01-20:
No changes

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

rusefillc, 2022-08-09:
@JRDMcLAREN are you still getting TLE8888 anywhere or do you just have a lot remaining?

JRDMcLAREN, 2022-08-09:
I have last 5 pcs. I'm bought "last" 18 pcs in January 2022 from Digikey
..and have last 3 pcs F407VGT6 ....

rusefillc, 2022-12-11:
@JRDMcLAREN moused has stock

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

JRDMcLAREN, 2022-12-12:
THX, 5pcs ordered ..
and what kind of MCU can be used in near future ... F427VGT7 .. maybe ..
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

rusefillc, 2022-12-12:
427vg is already used by MRE

JRDMcLAREN, 2023-01-19:
TLE8888QKXUMA1 is marked as "End Of Life" on Mouser
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

rusefillc, 2023-01-20:
it's a bit more complicated - primary version is active

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

JRDMcLAREN, 2023-02-05:
email form Mouser 26/01/2023
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

rusefillc, 2023-02-06:
@JRDMcLAREN please clarify what are you saying.

@JRDMcLAREN are you saying that mouser info is more reliable than https://www.infineon.com/cms/en/product/power/automotive-conventional-powertrain-ics/engine-management-ic/tle8888qk/ official status which shows "active" for me today?

JRDMcLAREN, 2023-02-06:
My experience is, when Mouser has some product marked as EoL, then it is END OF LIFE.
..we need to make "new MRE" with any other chip, maybe ....

YES, Infineon says ACTIVE, but datasheet date is 05/2017, Product Brief is 08/2015 and Footprint is 02/2019

..just try to think about it...

(I have last 10pcs on stock)

mi-hol, 2023-02-18:
> when Mouser has some product marked as EoL, then it is END OF LIFE.

I fully agree with this statement. This would mean the end for producing new MRE boards with current design & components.
What options for replacing TLE8888 do we have?

rusefillc, 2023-02-18:
I've just ordered enough chips that I can worry about it all later

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

mi-hol, 2023-02-18:
Or is maybe [EVAL-L9779WD-SPI](https://www.st.com/resource/en/data_brief/eval-l9779wd-spi.pdf) Evaluation board for L9779WD-SPI an alternative for the future?

Features
- Voltage min/max: 4.15V to 28V.
- No. channels:
  * 4 injector driver
  * 1 canister valve driver
  * 2 Lambda sensor heater
  * 1 Main relay driver
  * 6 relay driver
  * 1 LED driver
  * 4 Ignition driver
- A programmable power stage configurable as:
double H-bridge to drive a stepper motor driver,
or
as independent 4 High side and 4 Low side drivers.
- Device registers setting and the full diagnostic are available through SPI.
- Communication protocols: SPI, CAN, (both with dedicated connectors), Kline.
- Access to all relevant pins by test points. Input signal connector compatible with the SPC56MDiscovery
- Possibility to **connect a generic microcontroller boards by using a simple adapter**.

rusefillc, 2023-02-18:
Let's move this to https://rusefi.com/forum/ where that amazing chip is already discussed in detail

rusefillc, 2023-04-01:
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

rusefillc, 2023-04-01:
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

rusefillc, 2023-04-18:
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

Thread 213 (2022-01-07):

Short discovered - STM32 hitting high temperatures

Creesic, 2022-01-07:
Left MRE plugged into laptop via USB. Laptop went to sleep, came back to find MRE with an internal short. Both rails have shorted to ground.

rusefillc, 2022-01-07:
@Creesic please turn this unit off

rusefillc, 2022-01-07:
@mck1117 has a lot of spare units. @mck1117 are you interested to investigate this casualty?

Creesic, 2022-01-08:
As a note, it was plugged into a Surface Pro 4. Latest FW as of writing. R0.5.4 board.

rusefillc, 2022-01-13:
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

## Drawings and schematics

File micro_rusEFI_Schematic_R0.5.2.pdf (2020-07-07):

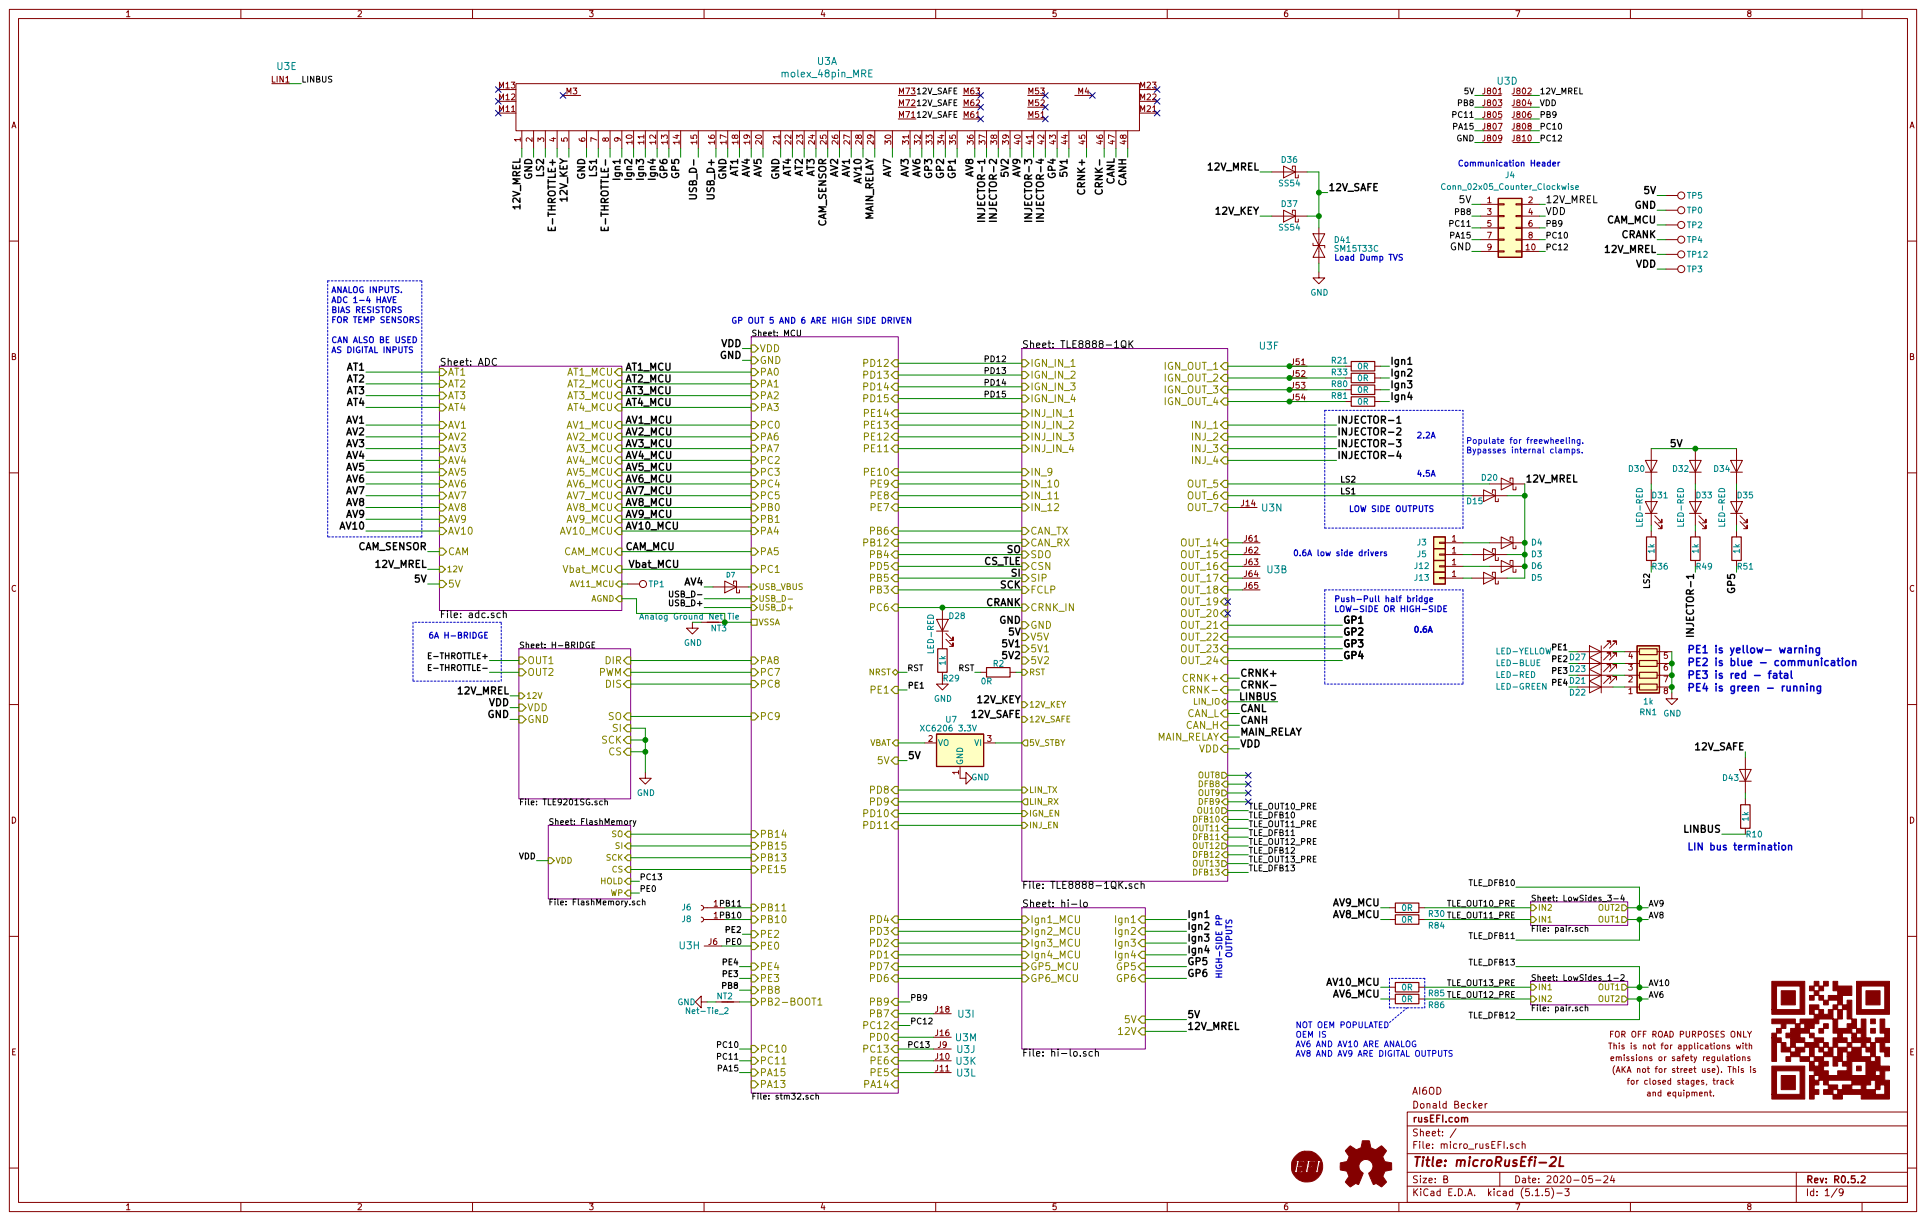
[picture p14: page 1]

0.6A low side drivers ANALOG INPUTS. ADC 1-4 HAVE BIAS RESISTORS FOR TEMP SENSORS CAN ALSO BE USED AS DIGITAL INPUTS

INJECTOR-1
INJECTOR-2
INJECTOR-3
Bypasses internal clamps. LOW SIDE OUTPUTS
INJECTOR-4

Push-Pull half bridge LOW-SIDE OR HIGH-SIDE

File: FlashMemory.sch SI SCKCS
VDD

Sheet: LowSides_1-2 File: pair.sch

NOT OEM POPULATED OEM IS AV6 AND AV10 ARE ANALOG

for closed stages, track FOR OFF ROAD PURPOSES ONLY
This is not for applications with
emissions or safety regulations
(AKA not for street use). This is

File: micro_rusEFI.sch Sheet: / rusEFI.com

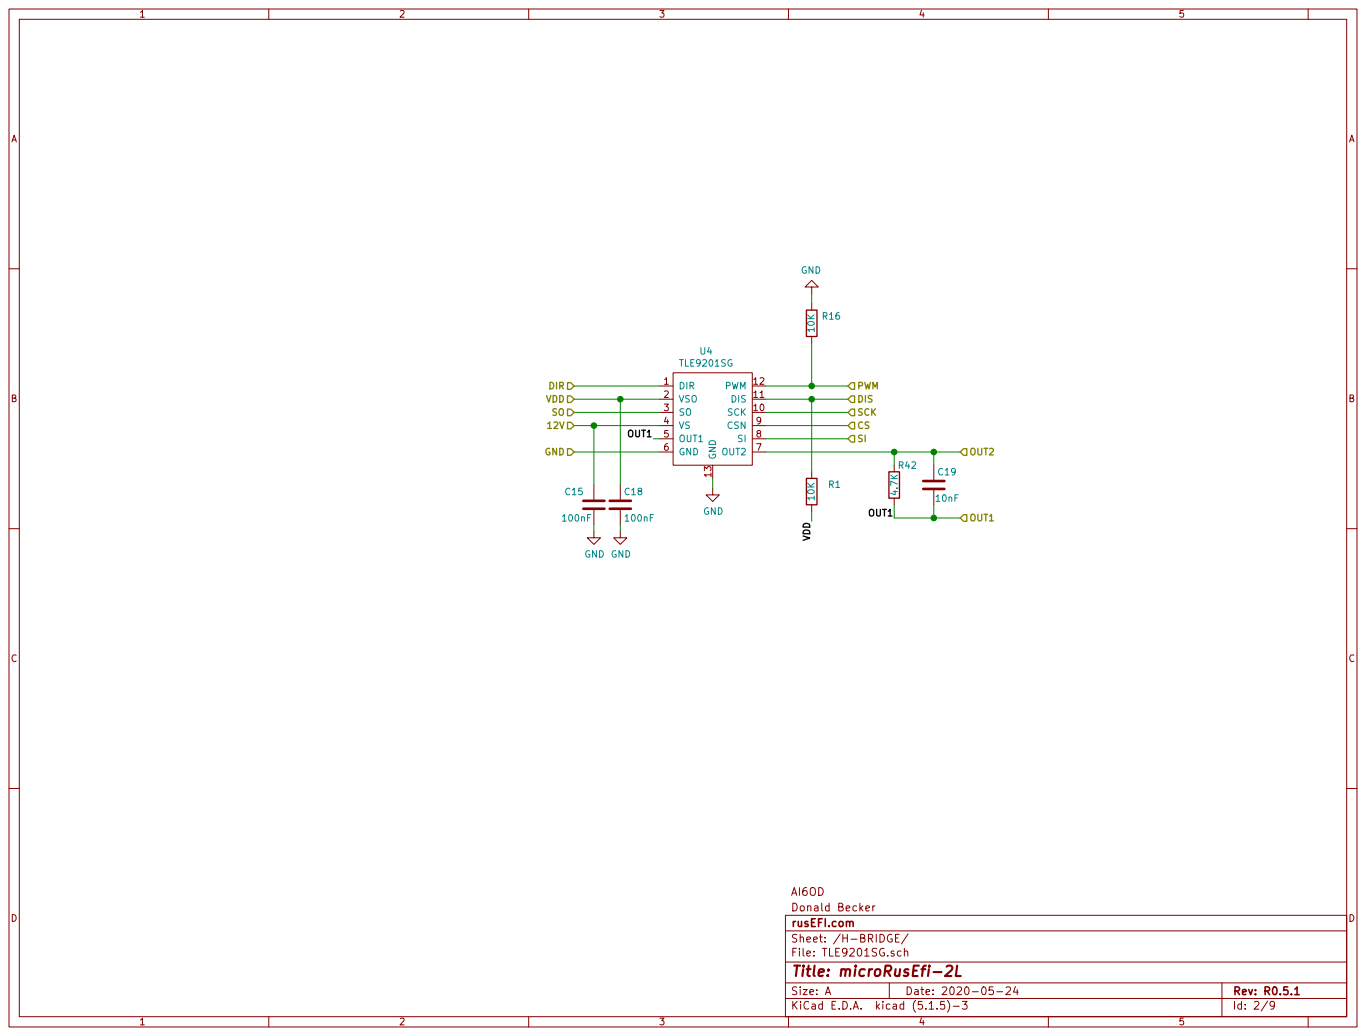
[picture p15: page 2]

File: TLE9201SG.sch Sheet: /H-BRIDGE/ rusEFI.com

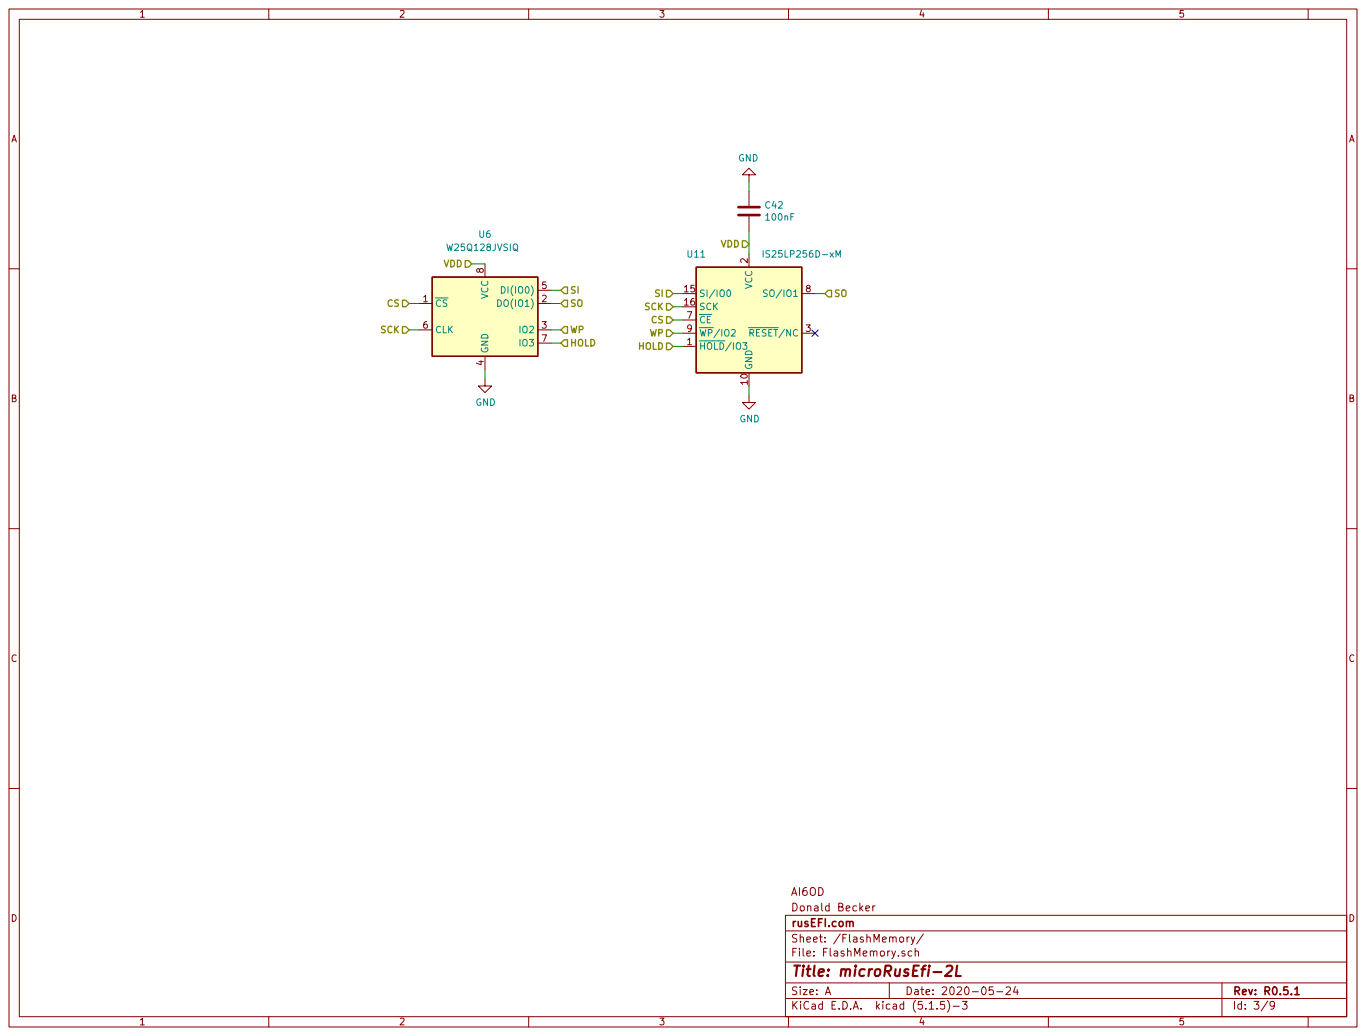
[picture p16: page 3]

2 RESET/NC 3 CE 7 SO/IO1 8 WP/IO2 9U11 IS25LP256D-xM

Sheet: /FlashMemory/ rusEFI.com

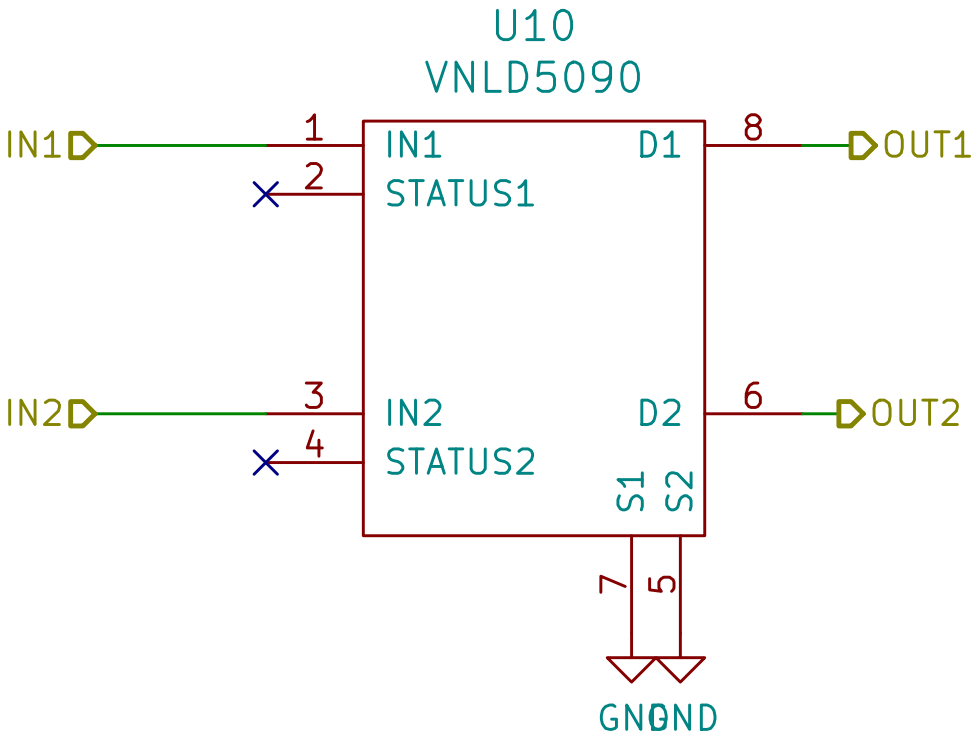
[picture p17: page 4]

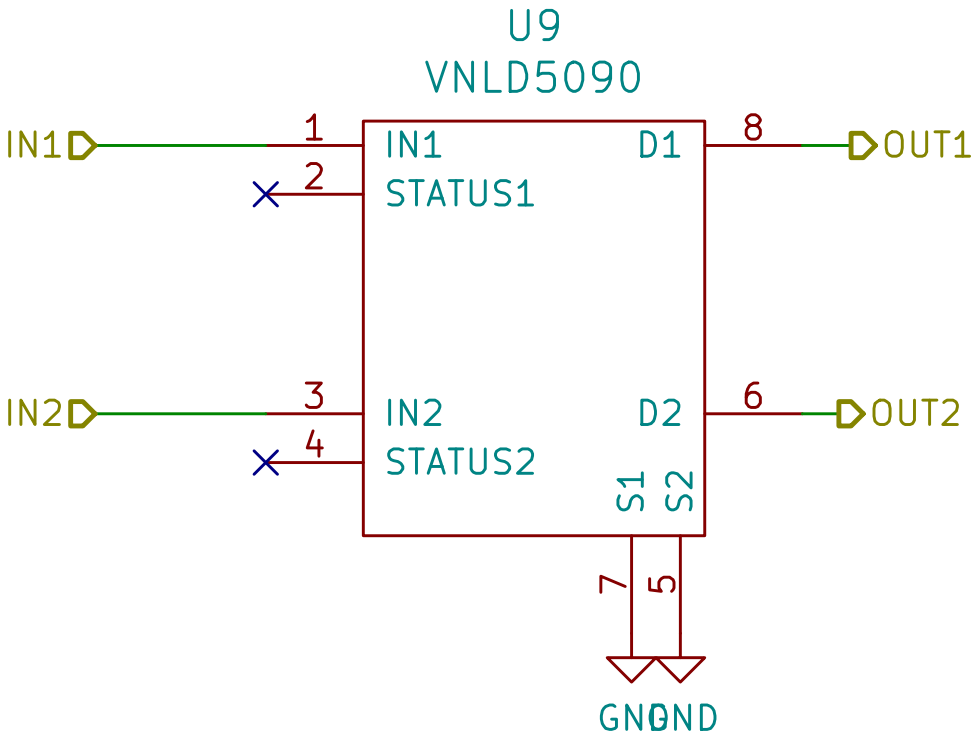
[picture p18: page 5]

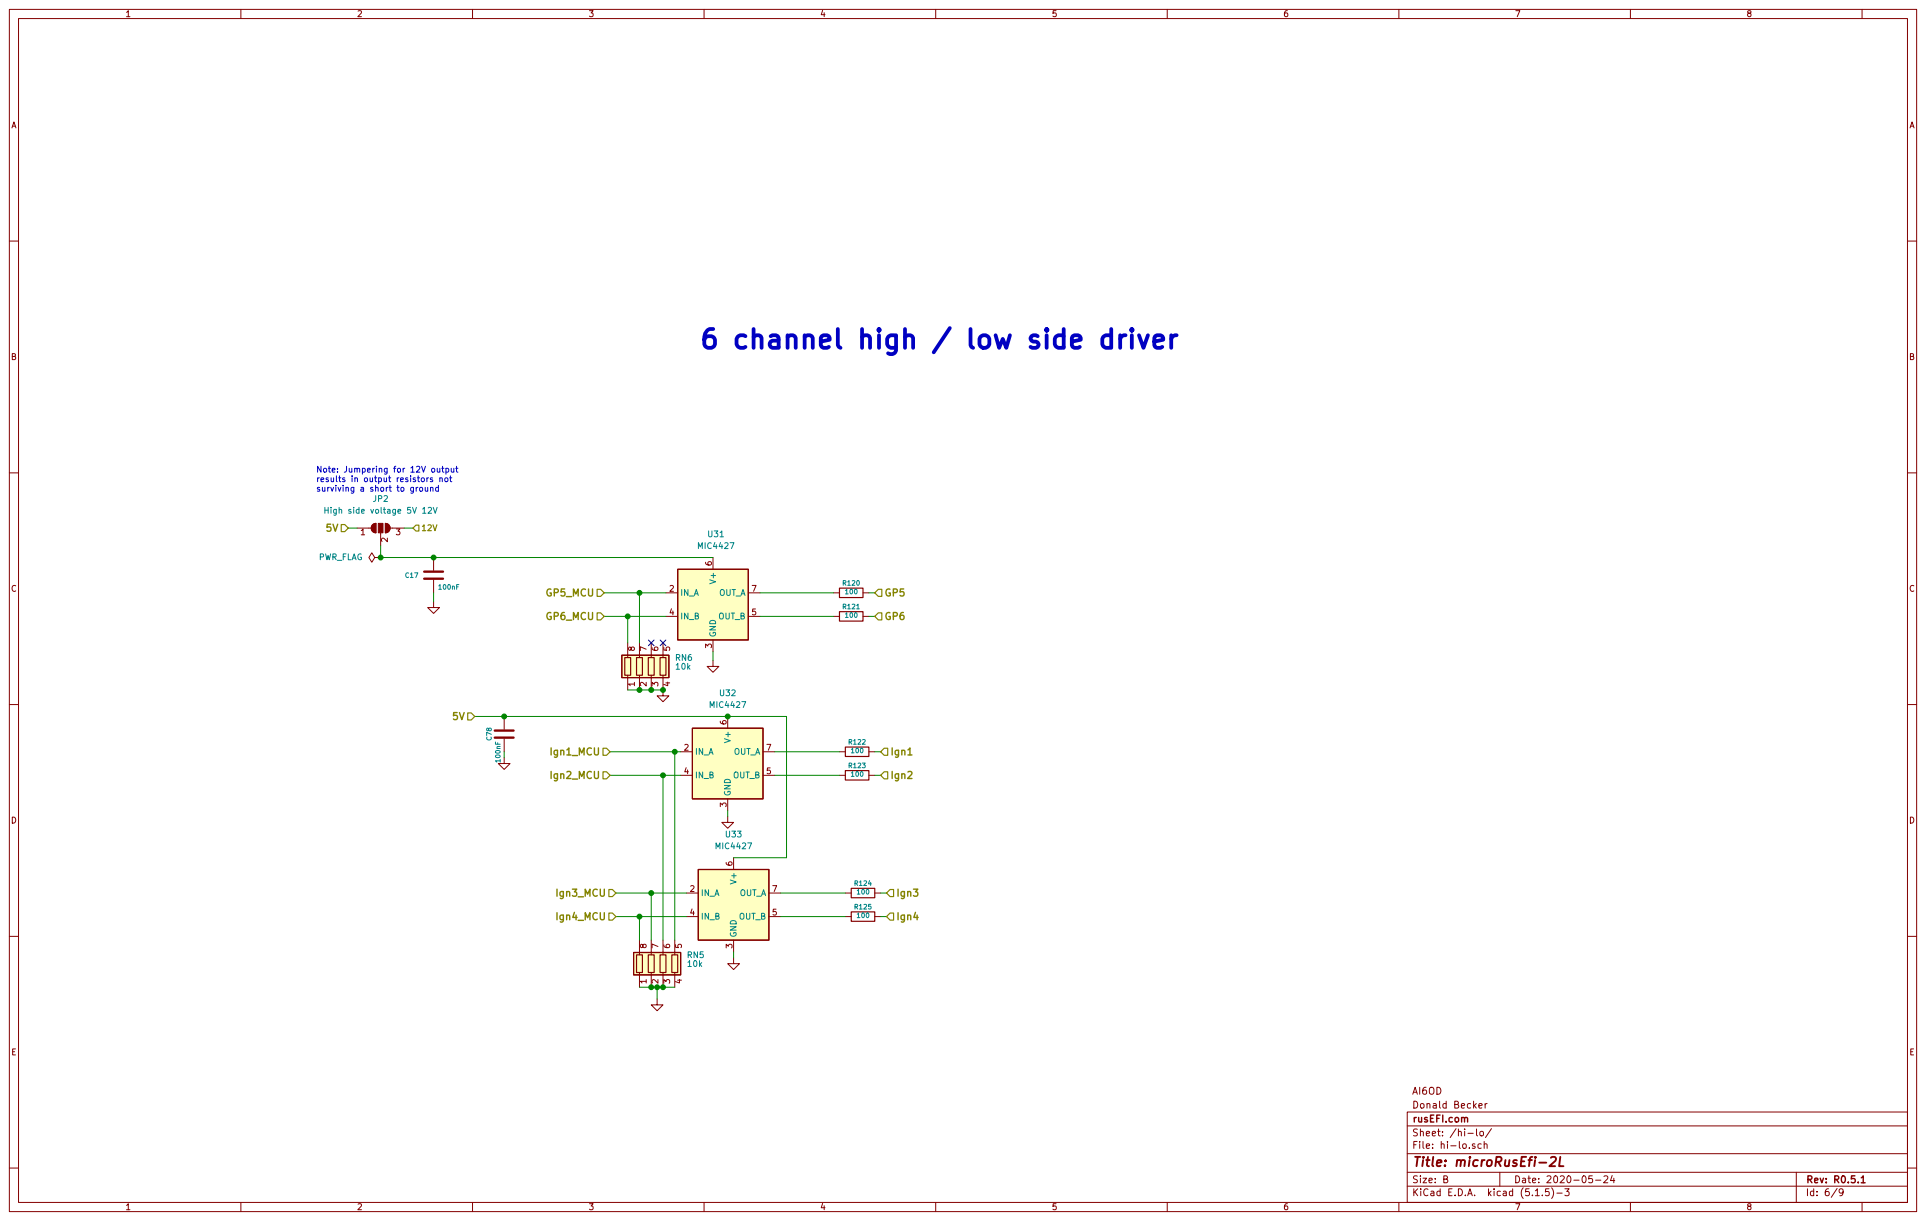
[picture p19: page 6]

Note: Jumpering for 12V output
results in output resistors not
surviving a short to ground
JP2 High side voltage 5V 12V

File: hi-lo.sch Sheet: /hi-lo/ rusEFI.com

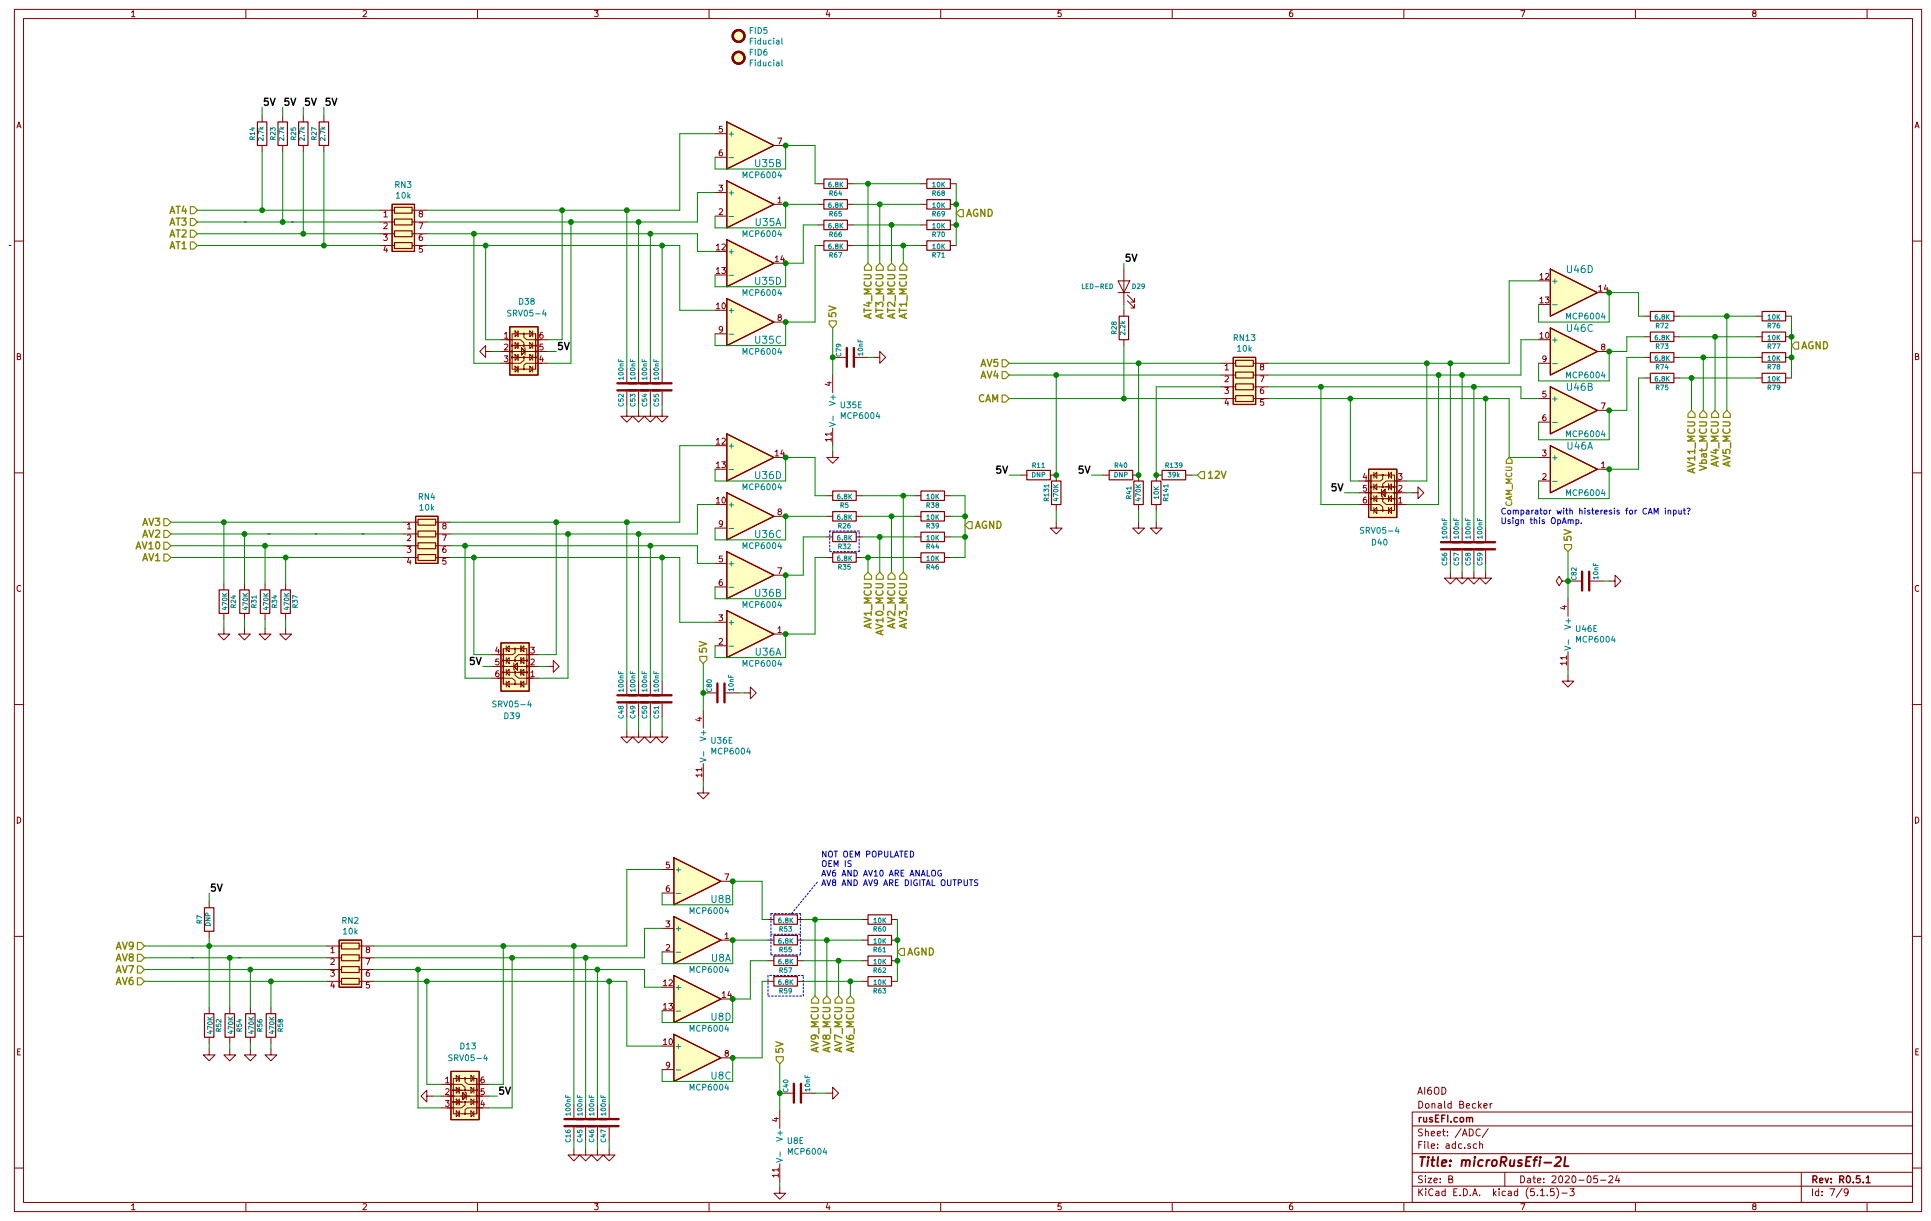
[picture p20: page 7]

NOT OEM POPULATED OEM IS AV6 AND AV10 ARE ANALOG

File: adc.sch Sheet: /ADC/ rusEFI.com

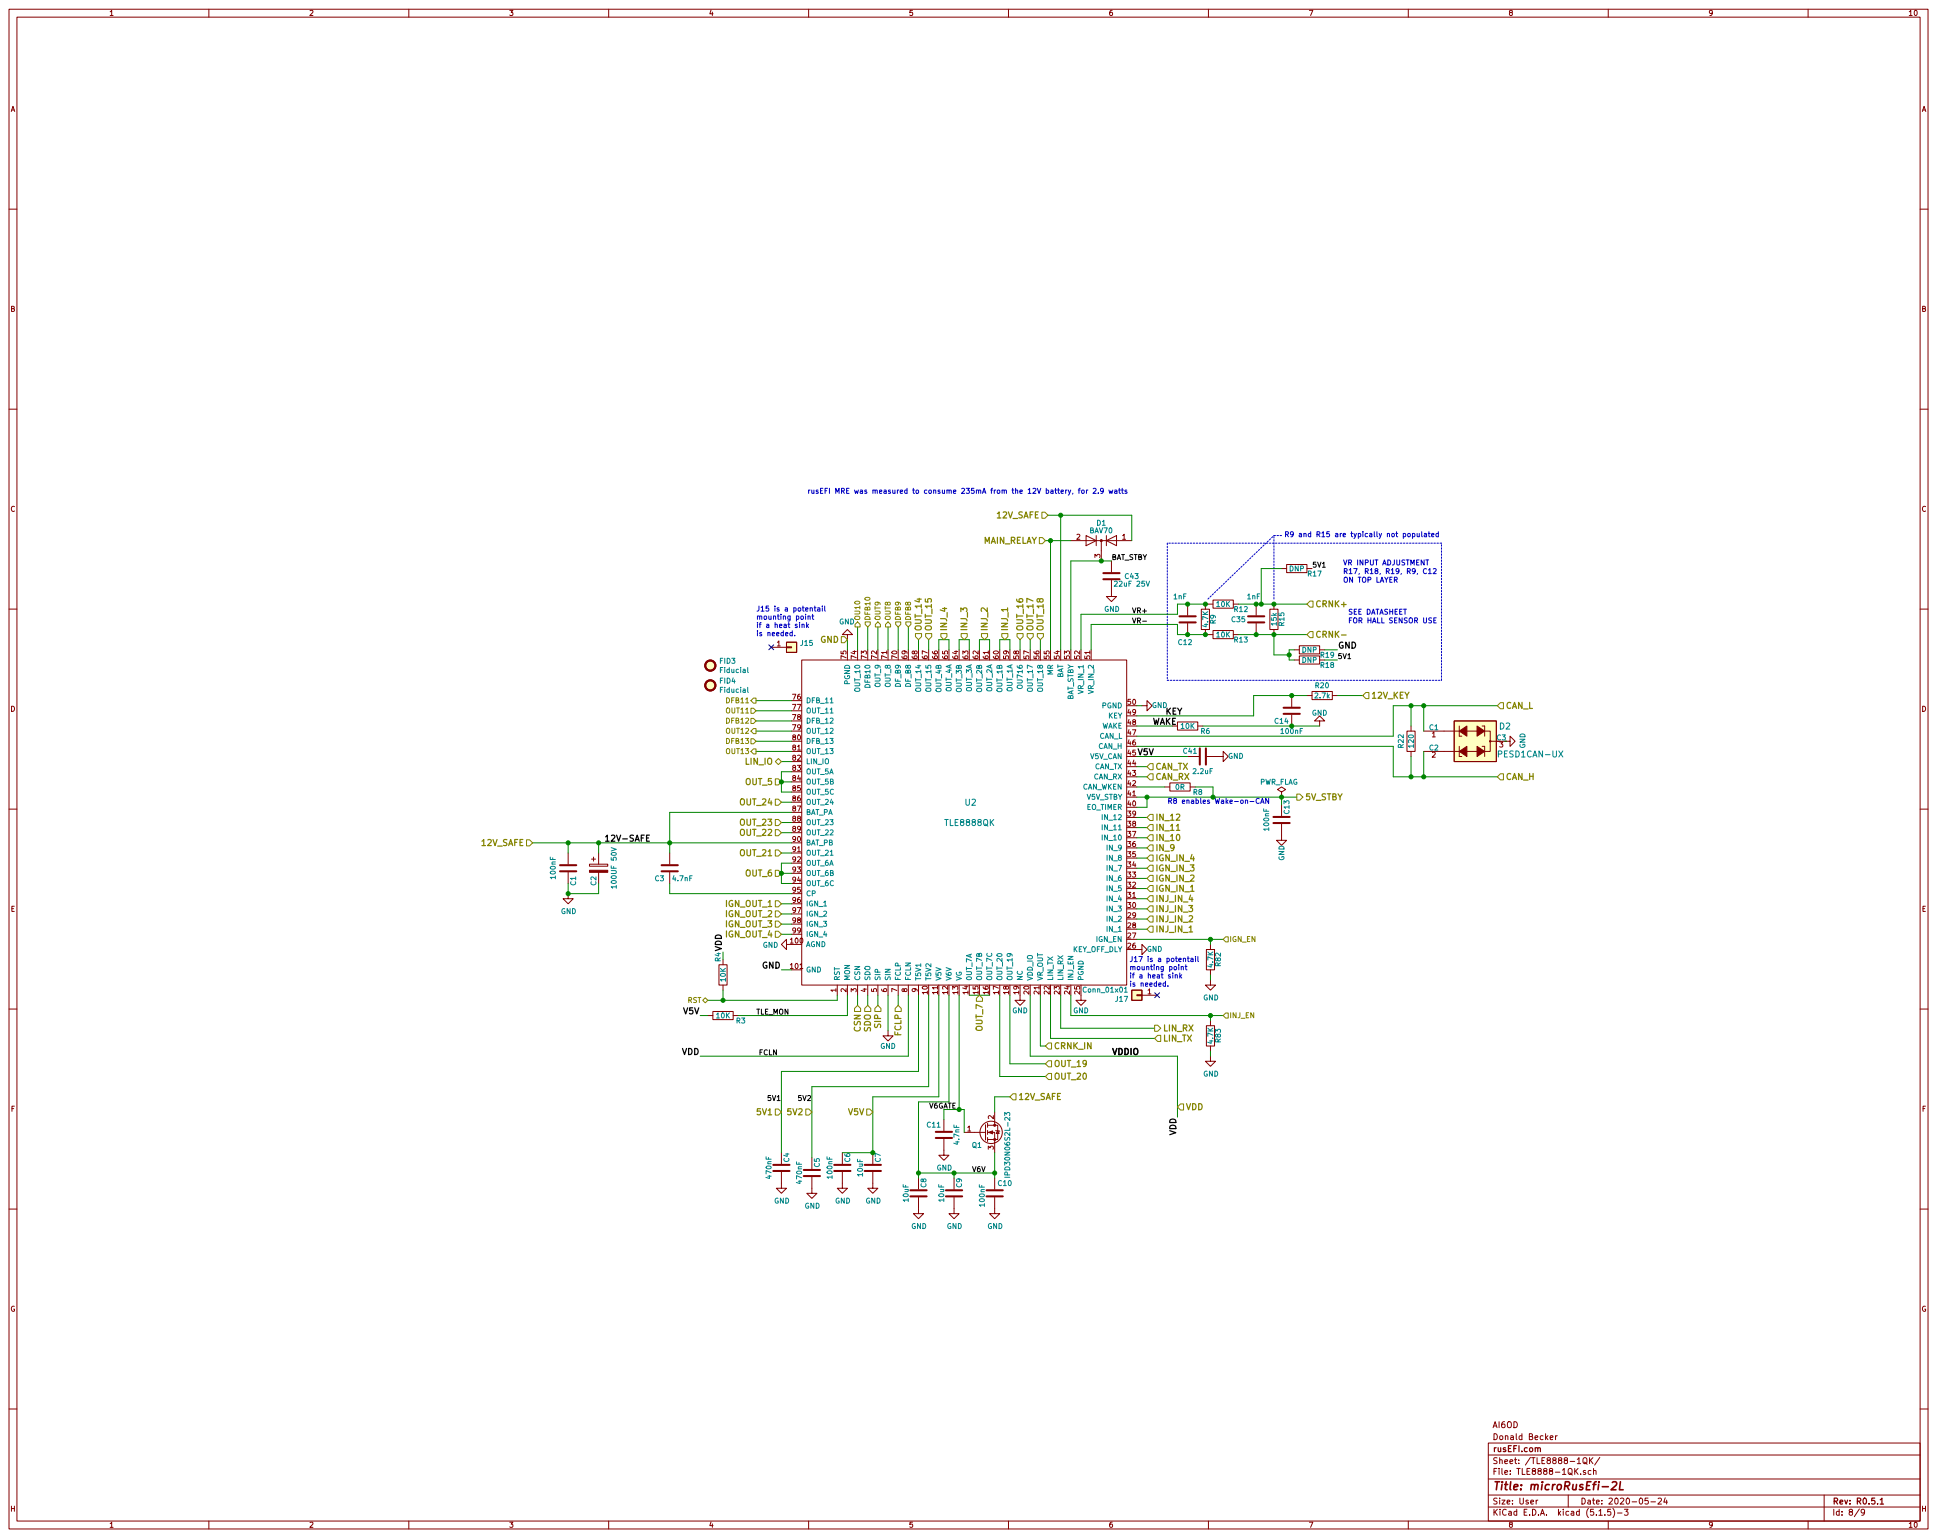
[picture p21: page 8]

R9 and R15 are typically not populated SEE DATASHEET FOR HALL SENSOR USE

VR INPUT ADJUSTMENT R17, R18, R19, R9, C12 ON TOP LAYER

5 PGND 50 VR_IN_2 51 VR_IN_1 52 BAT_STBY 53 BAT 54 MR 55 OUT_18 56 OUT_17 57 OU716 58 OUT_1A 59 SIN

1 T5V2 10 AGND 100 GND 101 V5V 11 V6V 12 VG 13 0UT_7A 14 OUT_7B 15 OUT_7C 16 OUT_20 17 OUT_19 18 NC 19 MON

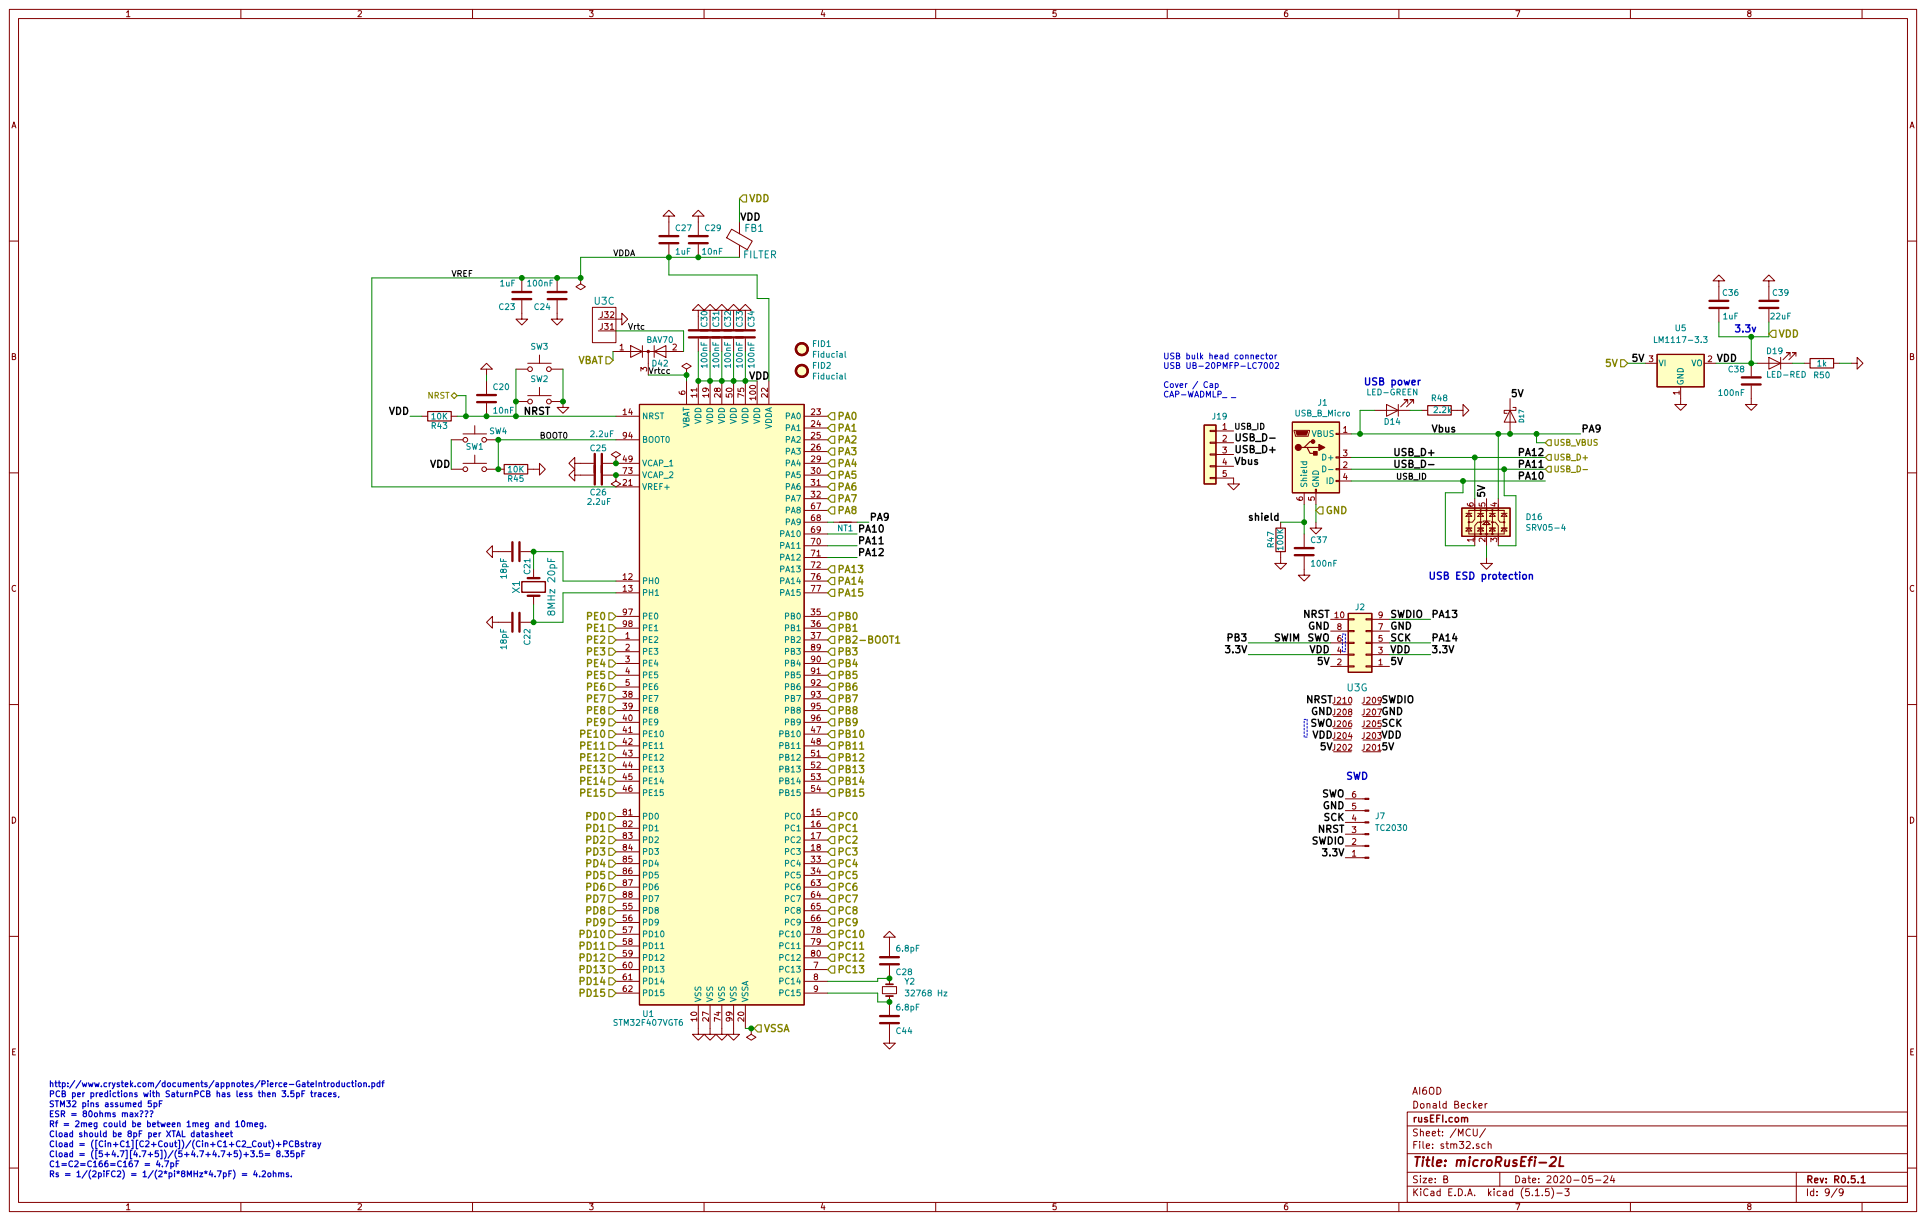
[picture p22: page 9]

USB bulk head connector USB UB-20PMFP-LC7002 Cover / Cap CAP-WADMLP_ _

6 VCAP_1 49 VCAP_2 73 VDD 100 VDD 11 VDD 19 VDD 28 VDD 50 VDD 75 VDDA 22 VREF+ 21 VSS 10 VSS 27 VSS 74 VSS 99 VSSA 20U1 STM32F407VGT6

http://www.crystek.com/documents/appnotes/Pierce-GateIntroduction.pdf
PCB per predictions with SaturnPCB has less then 3.5pF traces,
STM32 pins assumed 5pF ESR = 80ohms max??? Rf = 2meg could be between 1meg and 10meg.

File: stm32.sch Sheet: /MCU/ rusEFI.com

Cload should be 8pF per XTAL datasheet
Cload = ([Cin+C1][C2+Cout])/(Cin+C1+C2_Cout)+PCBstray
Cload = ([5+4.7][4.7+5])/(5+4.7+4.7+5)+3.5= 8.35pF
Rs = 1/(2piFC2) = 1/(2*pi*8MHz*4.7pF) = 4.2ohms.

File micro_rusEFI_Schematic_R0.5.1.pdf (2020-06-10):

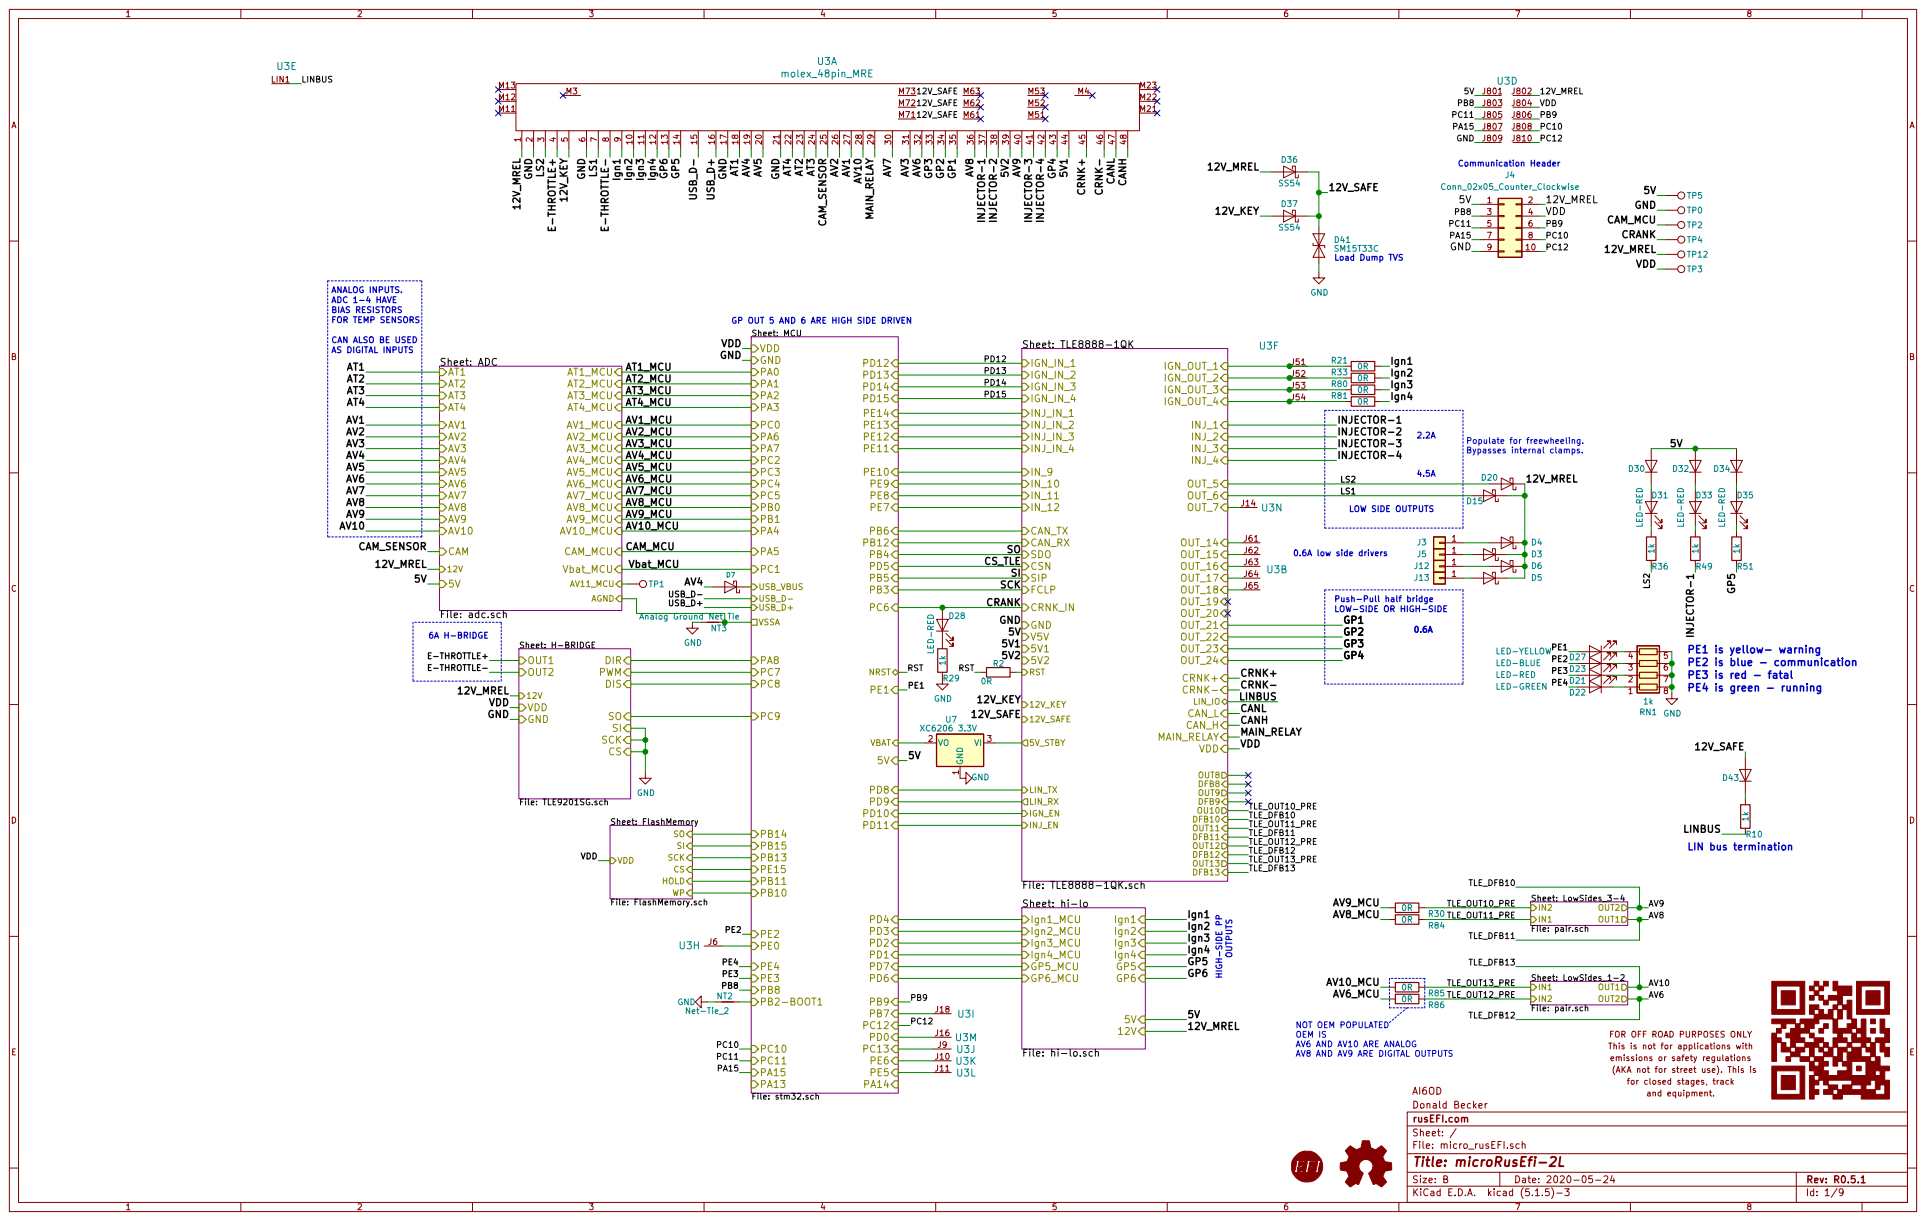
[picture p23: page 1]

Communication Header Load Dump TVS

INJECTOR-2 GP4 VDD
2.2A HIGH-SIDE PP OUTPUTS

4.5A GP OUT 5 AND 6 ARE HIGH SIDE DRIVEN
Sheet: MCU
VDD
GND

Bypasses internal clamps. 0.6A low side drivers

Push-Pull half bridge LOW-SIDE OR HIGH-SIDE

NT3 Analog Ground Net Tie GND

File: FlashMemory.sch SI SCKCS

Sheet: LowSides_1-2 File: pair.sch

NT2 Net-Tie_2
This is not for applications with GND

for closed stages, track FOR OFF ROAD PURPOSES ONLY

emissions or safety regulations
(AKA not for street use). This is

File: micro_rusEFI.sch Sheet: / rusEFI.com


File: TLE9201SG.sch Sheet: /H-BRIDGE/ rusEFI.com


2 RESET/NC 3 CE 7 SO/IO1 8 WP/IO2 9U11 IS25LP256D-xM

Sheet: /FlashMemory/ rusEFI.com




Note: Jumpering for 12V output
results in output resistors not
surviving a short to ground
JP2 High side voltage 5V 12V

File: hi-lo.sch Sheet: /hi-lo/ rusEFI.com


NOT OEM POPULATED OEM IS AV6 AND AV10 ARE ANALOG

File: adc.sch Sheet: /ADC/ rusEFI.com

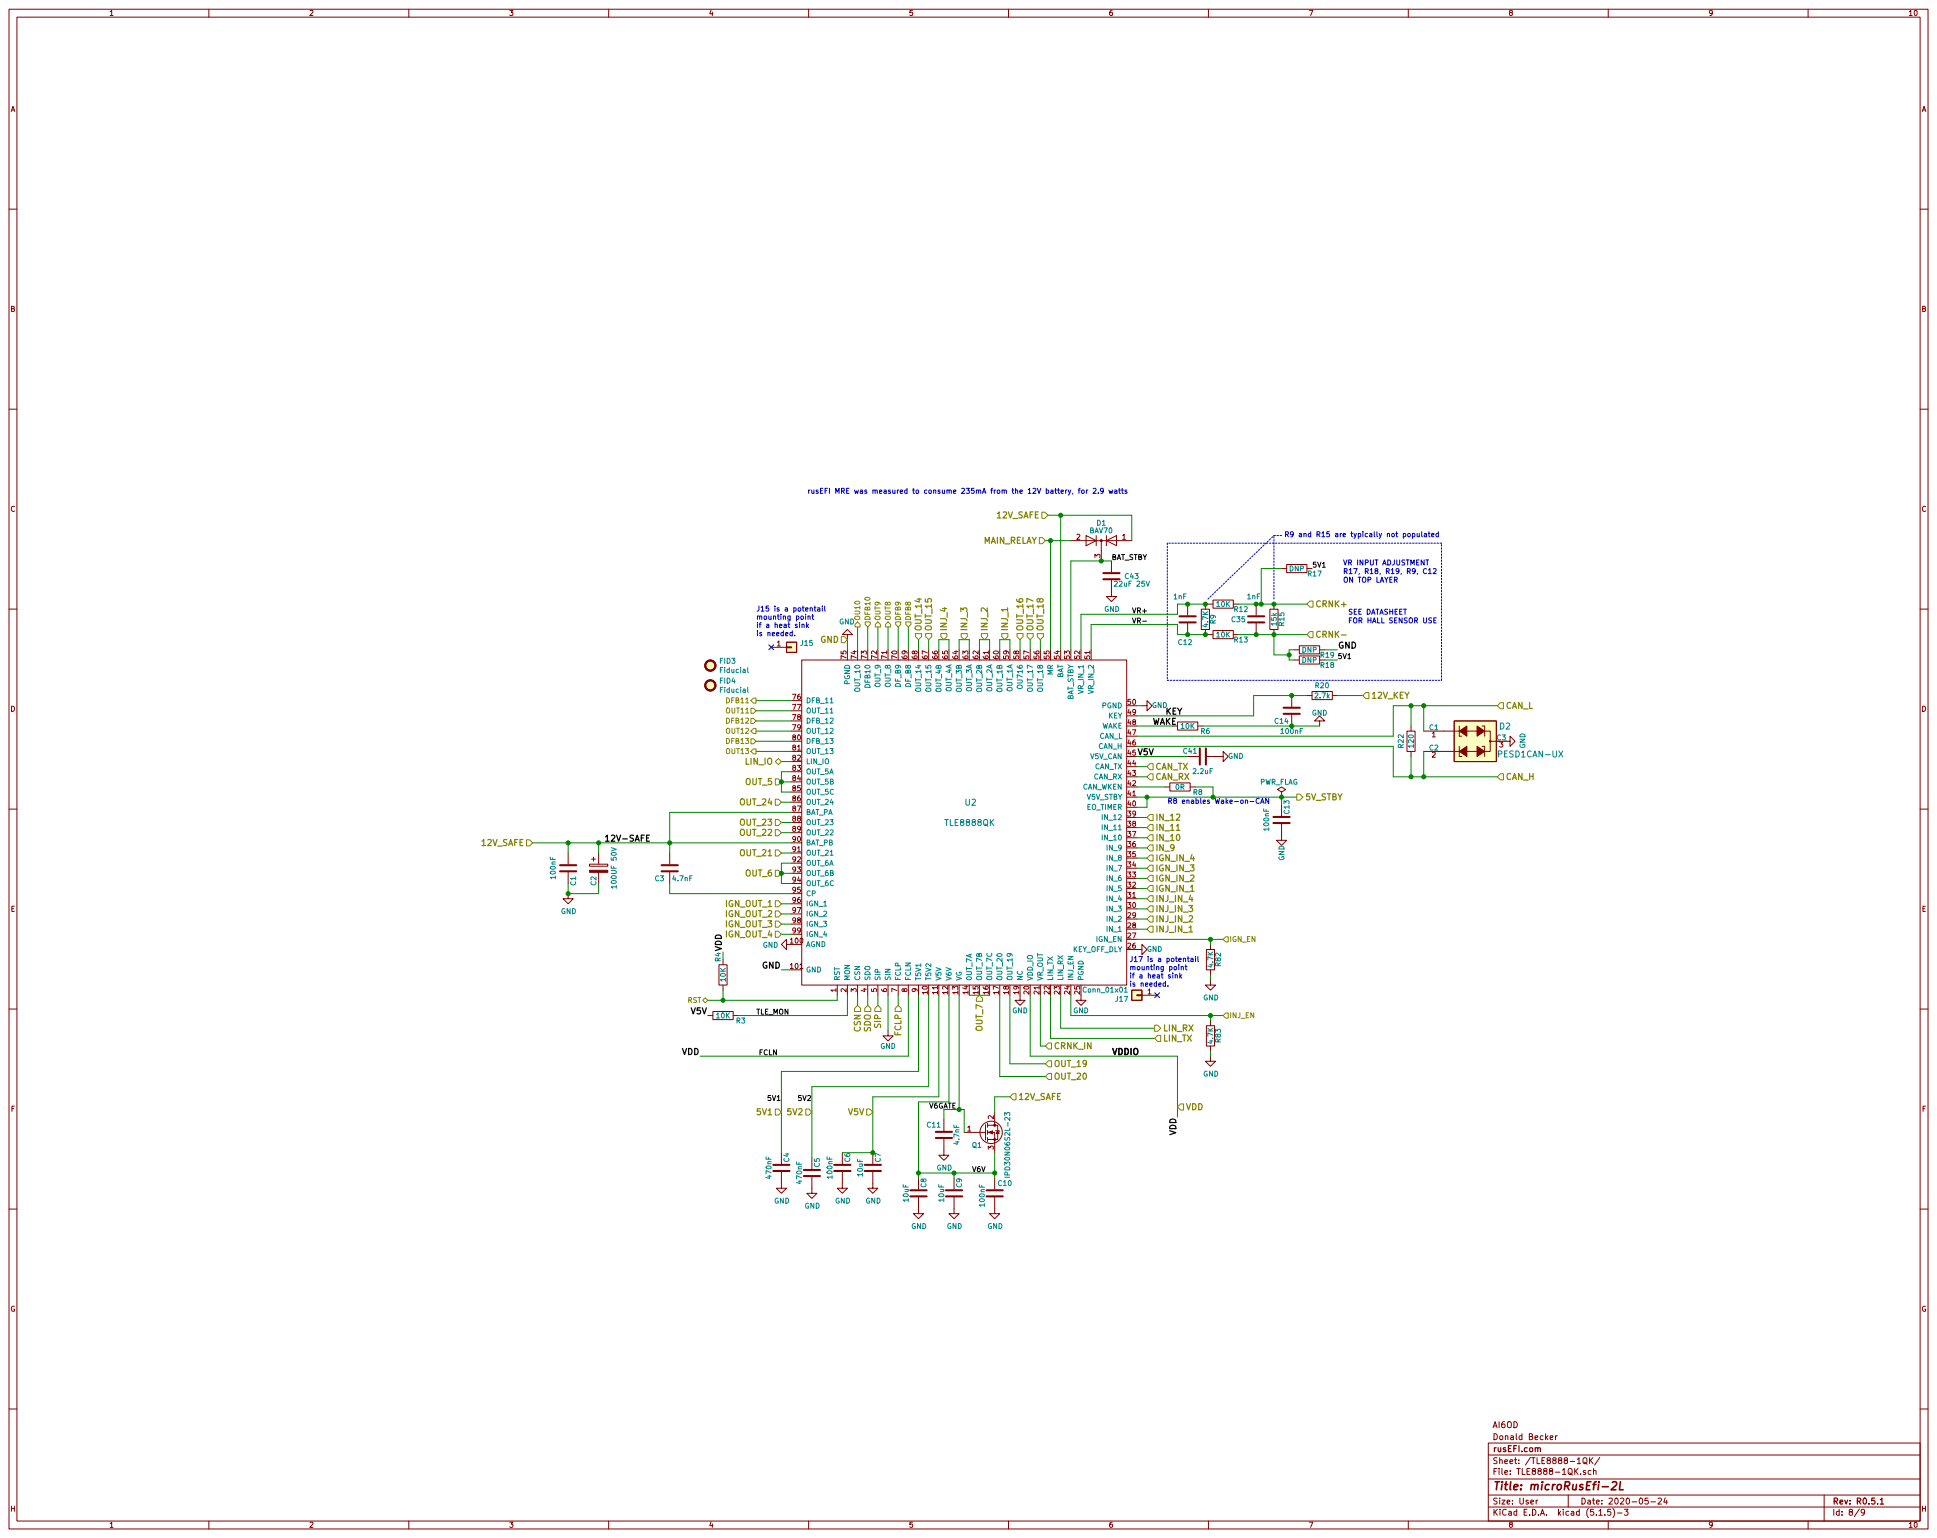
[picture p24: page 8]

R9 and R15 are typically not populated

VR INPUT ADJUSTMENT R17, R18, R19, R9, C12 ON TOP LAYER

SEE DATASHEET FOR HALL SENSOR USE

5 PGND 50 VR_IN_2 51 VR_IN_1 52 BAT_STBY 53 BAT 54 MR 55 OUT_18 56 OUT_17 57 OU716 58 OUT_1A 59 SIN

1 T5V2 10 AGND 100 GND 101 V5V 11 V6V 12 VG 13 0UT_7A 14 OUT_7B 15 OUT_7C 16 OUT_20 17 OUT_19 18 NC 19 MON


USB bulk head connector USB UB-20PMFP-LC7002 Cover / Cap CAP-WADMLP_ _

6 VCAP_1 49 VCAP_2 73 VDD 100 VDD 11 VDD 19 VDD 28 VDD 50 VDD 75 VDDA 22 VREF+ 21 VSS 10 VSS 27 VSS 74 VSS 99 VSSA 20U1 STM32F407VGT6

http://www.crystek.com/documents/appnotes/Pierce-GateIntroduction.pdf
PCB per predictions with SaturnPCB has less then 3.5pF traces,
STM32 pins assumed 5pF ESR = 80ohms max??? Rf = 2meg could be between 1meg and 10meg.

File: stm32.sch Sheet: /MCU/ rusEFI.com

Cload should be 8pF per XTAL datasheet
Cload = ([Cin+C1][C2+Cout])/(Cin+C1+C2_Cout)+PCBstray
Cload = ([5+4.7][4.7+5])/(5+4.7+4.7+5)+3.5= 8.35pF
Rs = 1/(2piFC2) = 1/(2*pi*8MHz*4.7pF) = 4.2ohms.

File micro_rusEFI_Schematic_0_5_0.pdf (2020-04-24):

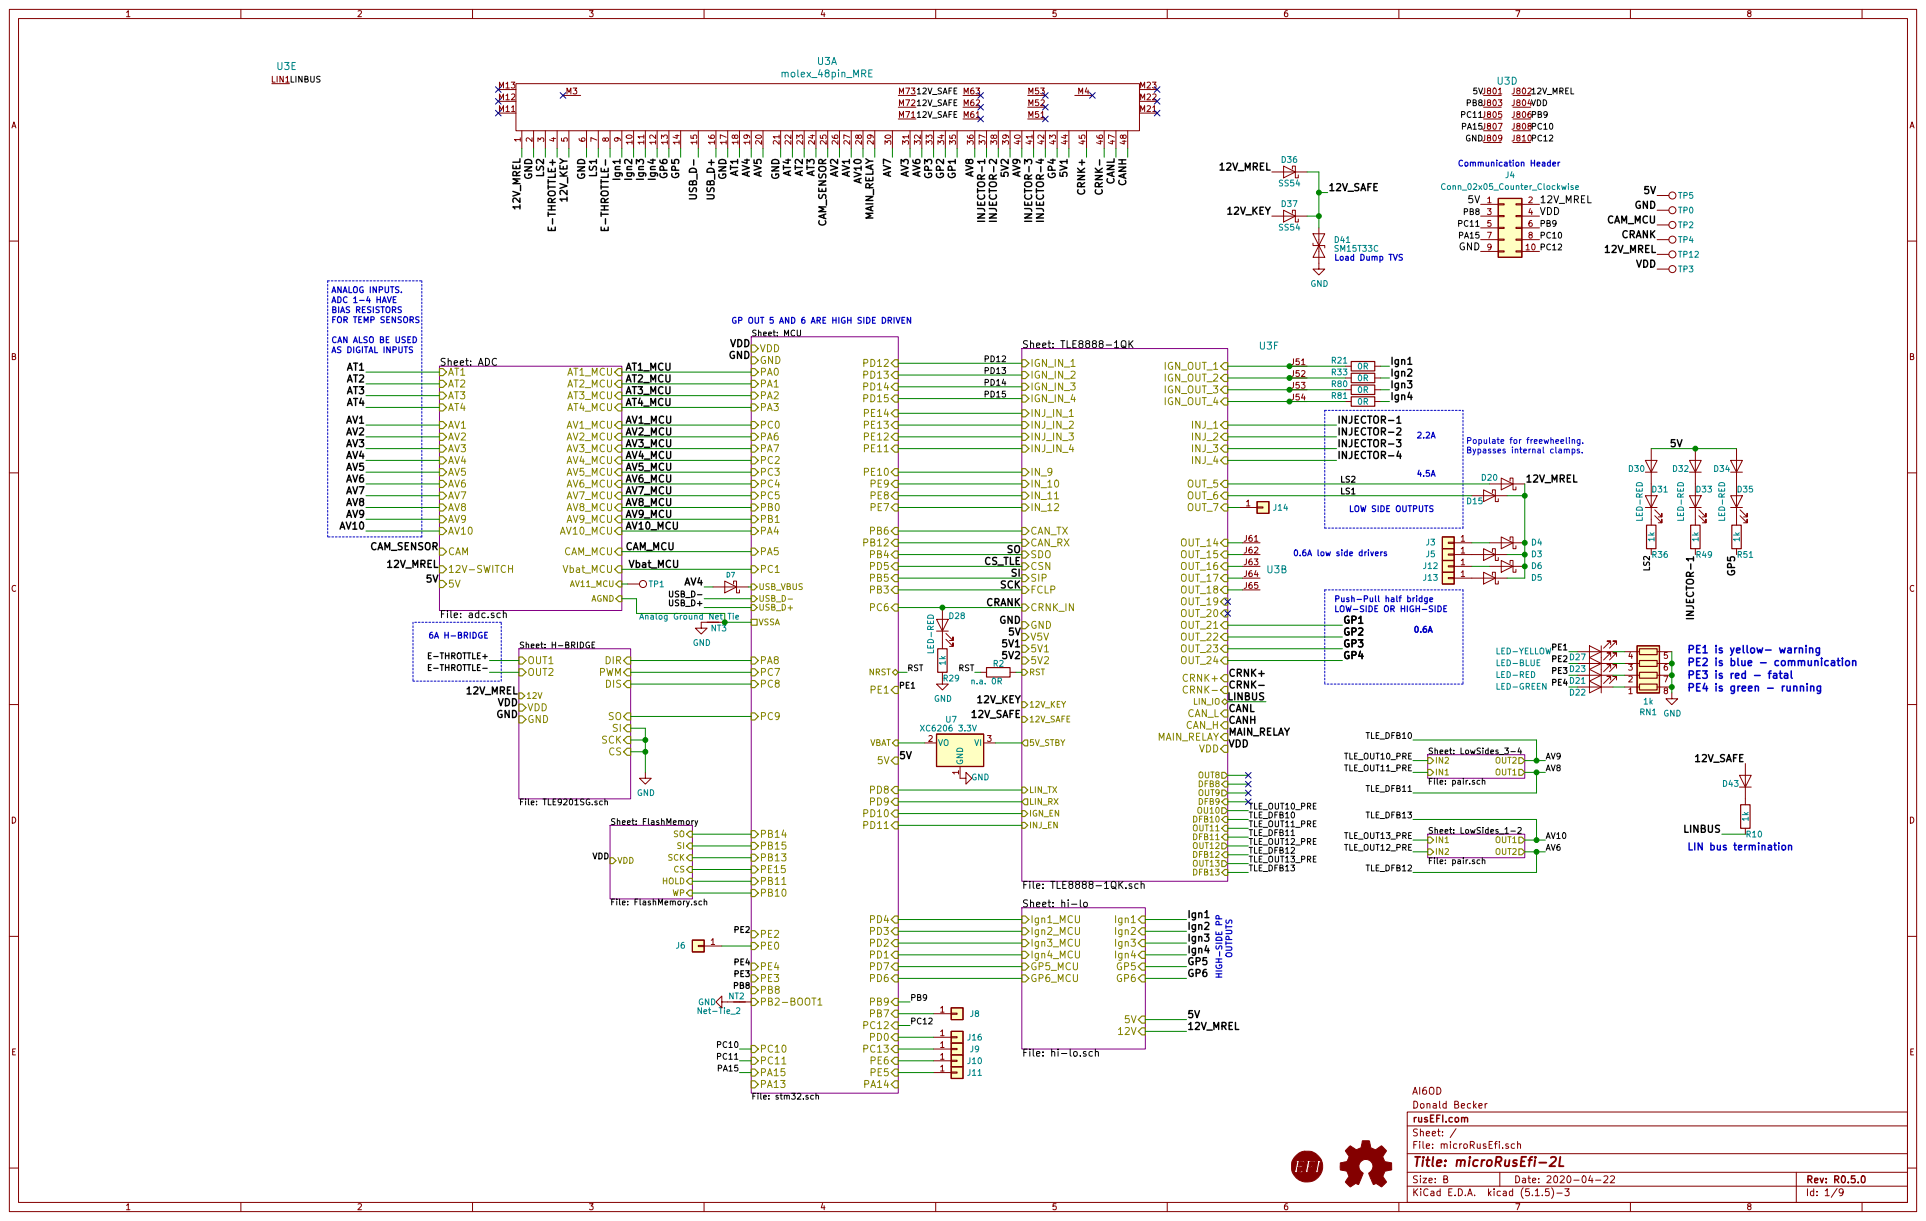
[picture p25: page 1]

Communication Header Load Dump TVS

ANALOG INPUTS. ADC 1-4 HAVE BIAS RESISTORS FOR TEMP SENSORS CAN ALSO BE USED AS DIGITAL INPUTS

LOW SIDE OUTPUTS GP OUT 5 AND 6 ARE HIGH SIDE DRIVEN
RST Sheet: MCU
VDD
GND

1 VO 2 VI 3 U7 XC6206 3.3V D22 LED-GREEN 1

Sheet: LowSides_3-4 File: pair.sch

File: FlashMemory.sch SI SCKCS

File: microRusEfi.sch Sheet: / rusEFI.com


File: TLE9201SG.sch Sheet: /H-BRIDGE/ rusEFI.com


2 RESET/NC 3 CE 7 SO/IO1 8 WP/IO2 9U11 IS25LP256D-xM

Sheet: /FlashMemory/ rusEFI.com




Note: Jumpering for 12V output
results in output resistors not
surviving a short to ground
JP2 High side voltage 5V 12V

File: hi-lo.sch Sheet: /hi-lo/ rusEFI.com


Comparator with histeresis for CAM input?
Usign this OpAmp.

File: adc.sch Sheet: /ADC/ rusEFI.com


rusEFI MRE was measured to consume 235mA from the 12V battery, for 2.9 watts

VR INPUT ADJUSTMENT R17, R18, R19, R9, C12 ON TOP LAYER

SEE DATASHEET FOR HALL SENSOR USE

5 PGND 50 VR_IN_2 51 VR_IN_1 52 BAT_STBY 53 BAT 54 MR 55 OUT_18 56 OUT_17 57 OU716 58 OUT_1A 59 SIN

1 T5V2 10 AGND 100 GND 101 V5V 11 V6V 12 VG 13 0UT_7A 14 OUT_7B 15 OUT_7C 16 OUT_20 17 OUT_19 18 NC 19 MON


http://www.crystek.com/documents/appnotes/Pierce-GateIntroduction.pdf
PCB per predictions with SaturnPCB has less then 3.5pF traces,
STM32 pins assumed 5pF ESR = 80ohms max??? Rf = 2meg could be between 1meg and 10meg.

File: stm32.sch Sheet: /MCU/ rusEFI.com

Cload should be 8pF per XTAL datasheet
Cload = ([Cin+C1][C2+Cout])/(Cin+C1+C2_Cout)+PCBstray
Cload = ([5+4.7][4.7+5])/(5+4.7+4.7+5)+3.5= 8.35pF
Rs = 1/(2piFC2) = 1/(2*pi*8MHz*4.7pF) = 4.2ohms.

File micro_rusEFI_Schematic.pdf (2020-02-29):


AT2_MCU

LOW SIDE OUTPUTS | 4.5A

Push-Pull half bridge LOW-SIDE OR HIGH-SIDE

NT3 Analog Ground Net Tie

LIN bus termination PE1 is yellow- warning

File: FlashMemory.sch SI SCKCS
VDD

File: microRusEfi.sch Sheet: / rusEFI.com


Note: Jumpering for 12V output
results in output resistors not
surviving a short to ground
JP2 High side voltage 5V 12V

File: hi-lo.sch Sheet: /hi-lo/ rusEFI.com


File: TLE9201SG.sch Sheet: /H-BRIDGE/ rusEFI.com


File: adc.sch Sheet: /ADC/ rusEFI.com


http://www.crystek.com/documents/appnotes/Pierce-GateIntroduction.pdf
PCB per predictions with SaturnPCB has less then 3.5pF traces,
STM32 pins assumed 5pF ESR = 80ohms max??? Rf = 2meg could be between 1meg and 10meg.

File: stm32.sch Sheet: /MCU/ rusEFI.com

Cload should be 8pF per XTAL datasheet
Cload = ([Cin+C1][C2+Cout])/(Cin+C1+C2_Cout)+PCBstray
Cload = ([5+4.7][4.7+5])/(5+4.7+4.7+5)+3.5= 8.35pF
Rs = 1/(2piFC2) = 1/(2*pi*8MHz*4.7pF) = 4.2ohms.


2 RESET/NC 3 CE 7 SO/IO1 8 WP/IO2 9U11 IS25LP256D-xM

Sheet: /FlashMemory/ rusEFI.com


rusEFI MRE was measured to consume 235mA from the 12V battery, for 2.9 watts

VR INPUT ADJUSTMENT R17, R18, R19, R9, C12 ON BOTTOM LAYER
V5V GND

5 PGND 50 VR_IN_2 51 VR_IN_1 52 BAT_STBY 53 BAT 54 MR 55 OUT_18 56 OUT_17 57 OU716 58 OUT_1A 59 SIN

120 | 1C2 | 3D2PESD1CAN-UX R22

1 T5V2 10 AGND 100 GND 101 V5V 11 V6V 12 VG 13 0UT_7A 14 OUT_7B 15 OUT_7C 16 OUT_20 17 OUT_19 18 NC 19 MON

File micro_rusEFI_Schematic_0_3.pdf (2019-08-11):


9 U3 Molex_48_pin AT2 AV3 GP3 GP2 CRNK+ CRNK- GND 5V1 GND AT1 AT3 AV6 GP1 5V2 GP4 CANH GND CANL Ign2 12V-SWITCH INJECTOR-1 INJECTOR-2 INJECTOR-3 INJECTOR-4 AV4 GND USB_D- USB_D+ H-BRIDGE

GP OUT 5 AND 6 ARE HIGH SIDE DRIVEN

CAN BE USED AS LOW-SIDE OR HIGH-SIDE 12V-SWITCH

Id: 1/7 Title: microRusEfi File: microRusEfi.sch Sheet: / MAIN_RELAY
VDD

FlashMemory.sch SI SCKCS


rusEFI MRE was measured to consume 235mA from the 12V battery, for 2.9 watts

5 PGND 50 VR_IN_2 51 VR_IN_1 52 BAT_STBY 53 BAT 54 MR 55 OUT_18 56 OUT_17 57 OU716 58 OUT_1A 59 SIN

1 T5V2 10 AGND 100 GND 101 V5V 11 V6V 12 VG 13 0UT_7A 14 OUT_7B 15 OUT_7C 16 OUT_20 17 OUT_19 18 NC 19 MON


Id: 3/7 Title: microRusEfi File: hi-lo.sch Sheet: /hi-lo/ rusEFI.com 6 channel high / low side driver

20R | INA 2 GND 3




http://www.crystek.com/documents/appnotes/Pierce-GateIntroduction.pdf
PCB per predictions with SaturnPCB has less then 3.5pF traces,
STM32 pins assumed 5pF ESR = 80ohms max??? Rf = 2meg could be between 1meg and 10meg.

Cload should be 8pF per XTAL datasheet
Cload = ([Cin+C1][C2+Cout])/(Cin+C1+C2_Cout)+PCBstray
Cload = ([5+4.7][4.7+5])/(5+4.7+4.7+5)+3.5= 8.35pF
Rs = 1/(2piFC2) = 1/(2*pi*8MHz*4.7pF) = 4.2ohms.

Id: 6/7 Title: microRusEfi File: stm32.sch Sheet: /MCU/


2 RESET/NC 3 CE 7 SO/IO1 8 WP/IO2 9U11 IS25WP256D-xM
















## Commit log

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2019-05-17 Fix kicad libs (#14)
    * gitignore
    * fix tc4427
    * fix cache name
    * fix 8888
    * update lib
    * add molex
    * fix adc
    * update lib
    * fix 9201, 4427, digital resistors
    * fix usb
    [TLE8888-1QK.sch, TLE9201SG.sch, adc.sch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]
2019-05-18 fixed path to stm32
    [microRusEfi.sch]
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2019-05-21 Corrected to PC6 as crank input (#18)
    [microRusEfi.sch]
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2019-05-24 changed to lm2937 ldo (#20)
    [TLE8888-1QK.sch, TLE9201SG.sch, hi-lo.sch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]
2019-05-26 Update of returning faults each pull (#21)
    [TLE8888-1QK.sch, TLE9201SG.sch, hi-lo.sch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]
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2019-05-26 fixed drc (#23)
    [microRusEfi.kicad_pcb]
2019-05-29 Molex 48 pin silkscreen on the back #25
    [microRusEfi.kicad_pcb]
2019-05-29 manual sync with 960
    [TLE8888-1QK.sch, TLE9201SG.sch, adc.sch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]
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2019-06-03 Small fix (#44)
    * Small fix
    * PDF
    [microRusEfi.kicad_pcb]
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2019-06-06 Small fix (#52)
    [FlashMemory.sch, TLE8888-1QK.sch, TLE9201SG.sch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]
2019-06-09 Ready To Go! (#53)
    [FlashMemory.sch, TLE8888-1QK.sch, microRusEfi.kicad_pcb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]
2019-06-09 2x5 BOM and small fix (#54)
    [microRusEfi.kicad_pcb, microRusEfi.sch, stm32.sch]
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2019-06-10 Fixed capitalization for adc.sch (#56)
    Changed capitalization for ADC sheet reference (fixes a problem on case-sensitive file systems such as on linux)
    [microRusEfi.sch]
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2019-06-22 With only two weeks of nagging Matt has shared the BOM
    Matt does not seem to notice how negatively his hesitation to document things publicly affects the relationships
    [microRusEfi.csv]
2019-07-02 from Ola and Jared (#71)
    * Update
    * removed fp-info-cache from git
    * Gerbers
    * moved connector
    * Mostly Ola's e-mailed copy, plus some of my own fixes to his almost done revision. I also did some house cleaning, with boundary edges, removed most DRC and ERC errors, etc.
    * added Fiducial's
    [FlashMemory.sch, TLE8888-1QK.sch, TLE9201SG.sch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]
2019-07-03 My first pull request. Not skeet edition. (#72)
    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
2019-07-05 manual sync from jharvey, neccesary evil here
    [FlashMemory.sch, TLE8888-1QK.sch, TLE9201SG.sch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]
2019-07-05 Several updates. RN CN text alingment BOMs populated (#73)
    * Updated logo symbol and footprint, BOM is 99% entered in KC schematic now.
    * Several U# were changed to RN# as they are resistor networks, not semiconductor chips. RN1 is now clearly a 1k.
    * Several U# were changed to RN# as they are resistor networks, not semiconductor chips. RN1 is now clearly a 1k. Also some U# were changed to CN#. BOM is now co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
2019-07-05 manual sync from jharvey
    [TLE8888-1QK.sch, microRusEfi.kicad_pcb, microRusEfi.sch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]
2019-07-05 Several issues teachers addressed. Silk, notes via's added, some traces and pads changed slightly (#78)
    * Several U# were changed to RN# as they are resistor networks, not semiconductor chips. RN1 is now clearly a 1k. Al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
2019-07-07 manual sync & moving gerbers
    [microRusEfi.kicad_pcb, microRusEfi.sch, stm32.sch]
2019-07-07 update (#79)
    * Several U# were changed to RN# as they are resistor networks, not semiconductor chips. RN1 is now clearly a 1k. Also some U# were changed to CN#. BOM is now completely populated.
    * Some general MISC cle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
2019-07-07 getting closer to 0.2
    [microRusEfi.kicad_pcb]
2019-07-08 with new PDF name and gerbers (#80)
    * Several U# were changed to RN# as they are resistor networks, not semiconductor chips. RN1 is now clearly a 1k. Also some U# were changed to CN#. BOM is now completely populated.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
2019-07-13 sync (#85)
    * Some general MISC clean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
2019-07-31 sync (#98)
    * Added silk screen mark, minor schematic formatting.
    https://github.com/rusefi/hw_microRusEfi/issues/89
    * Changed SWD connector to reflect validated brain board.
    https://github.com/rusefi/hw_microRusEfi/issues/88
    * Changed R26 into push button SW1 BOM is still TBD
    https://github.com/rusefi/hw_microRusEfi/issues/86
    * coil1 silk was corrected to coil2
    https://github.com/rusefi/hw_microRusEfi/issues/90
    * Updated BOM
    https://github.com/rusefi/hw_microRusEfi/issues/94
    [TLE9201SG.sch, adc.sch, hi-lo.sch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]
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2019-08-10 xxx (#101)
    * Moved R21 to match position as noted on demo board reference design.
    https://github.com/rusefi/hw_microRusEfi/issues/93
    * Added small silk to connector.
    https://github.com/rusefi/hw_microRusEfi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
    [TLE8888-1QK.sch, microRusEfi.kicad_pcb]
2019-08-11 sync with conflict again :( (#102)
    https://github.c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
    [adc.sch, microRusEfi.sch]
2019-08-11 getting closer to 0.3
    [TLE8888-1QK.sch, TLE9201SG.sch, hi-lo.sch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]
2019-08-11 getting closer to 0.3 (#103)
    https://github.com/rus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
2019-08-18 BOM fix, reset button
    [FlashMemory.sch, TLE8888-1QK.sch, TLE9201SG.sch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]
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2019-09-02 manual sync fix #109
    [microRusEfi.kicad_pcb, microRusEfi.sch]
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2019-09-16 Re-organized top vs bottom components. Fixed footprint
    [microRusEfi.kicad_pcb]
2019-09-17 Moved GP5/6 voltage selection to center.
    [microRusEfi.kicad_pcb]
2019-09-23 Significant revision of schematic and layout:
    Added reverse voltage protection.
    Split 12V supply into a 12V-Key (ignition) pin and a 12V-MRel (supply from
    main relay) pin. The 12V main relay is controlled by the MRel pin to protect against reverse voltage and over-voltage.
    The board can optionally draw under 1mA from the main relay coil to power
    standby features, including CAN monitoring.
    Increased the size of several resistors, notably ignition output resistors
    and CAN termination, to handle typical power draw.
    Changed resistor dividers to individual resistors for better accuracy than
    typical resistor networks.
    Standardized pull-up and pull-down resistors to 10K.
    Changed to a tab-outp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
    [FlashMemory.sch, TLE8888-1QK.sch, TLE9201SG.sch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]
2019-09-27 Includes all known errata, except for component rotation for JLCPCB fabrication.
    Includes
    Refined reverse protection layout with dual SS54 diodes
    Load dump protection, SMB TVS for 33V TVS
    Multiple footprints for Flash (SO-16, SO-8-208 and SO-8-150)
    Simplified pull-up and pull-down resistors, omitting unneeded ones
    Individual resistors for resistor dividers for easier sourcing of
    1% precision (most resistor networks are 5%, most 0603 parts are 1%).
    PicoBlade connector for RTC battery, matches low-cost laptop 2032 cells
    Clamping diode arrays on top, alternate BAS70 on bottom
    Options for VR input modification, and analog pull-ups on bottom.
    LM1117 voltage regulator footpri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
    [FlashMemory.sch, TLE8888-1QK.sch, TLE9201SG.sch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]
2019-10-07 Added 2x5 header for SPI/serial communications Connected LIN to PD8/PD9 USART3, output on SMD testpoint. Added standby regulator. Changed footprints of reverse protection diodes to SMA. Rotated two o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
    [FlashMemory.sch, TLE8888-1QK.sch, TLE9201SG.sch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]
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2019-10-09 0.4.5-2L board as submitted for fabrication
    [FlashMemory.sch, TLE8888-1QK.sch, TLE9201SG.sch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]
2019-10-16 Re-worked layout, wider traces, segregated ground current, opened area (#110)
    * Add files via upload
    * cover bolt info from stefanst
    * Re-organized top vs bottom components. Fixed footprint
    * Moved GP5/6 voltage selection to center.
    * Significant revision of schematic and layout:
    Increased the size of several resistors, notabl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
    [FlashMemory.sch, TLE8888-1QK.sch, TLE9201SG.sch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]
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2019-11-03 Sync to pull gerbers (#120)
    Ch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
2019-12-22 0.4.6 board
    Corrected scrambled Vref/Vbat/AV4/AV5 inputs
    Moved USB Vbus to a diode clamp pin on the SRV05 diode array
    Lowered brightness of USB power LED by changing resistor from 1K to 2.2K
    Moved Reset button adjacent to Program button for easier entry to DFU programming mode
    Moved SWD connector away from USB connector for generous shroud clearance
    Removed thermal breaks from TLE8888 bottom layer thermal area
    Changed TLE8888 ingition outputs to a 1x4 connector instead of 4 test points
    Added diode pair for STM32 Vbat (RTC power) to allow simultaneous 2032 coin cell and external constant battery
    Changed communication header pin PD0 to PB9 to support I2C and CAN
    Reduced size of 5V and GND test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
    [FlashMemory.sch, TLE8888-1QK.sch, TLE9201SG.sch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]
2019-12-30 Changes for 0.4.7 Corrected mixed-up Vref/Vbatt/AV4/AV5 inputs Put USB Vin on a regular diode clamp, not the +V clamping rail. Changed USB diode array +V clamping to the internal 5V rail. Selected a 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
    [FlashMemory.sch, TLE8888-1QK.sch, TLE9201SG.sch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]
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2020-01-01 replacing \n\n with just \n
    [rusEFI-Micro_R0.4.5-cpl.csv]
2020-01-01 starting with 0.4.5 file as base
    [rusEFI-Micro_R0.4.7-cpl.csv]
2020-01-01 semi-automatic, half-manual placement file progress
    [rusEFI-Micro_R0.4.7-cpl.csv]
2020-01-01 making R48 less bright
    [rusEFI-Micro_R0.4.7-bom.csv]
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2020-02-13 Fixed rescue lib issue.
    [FlashMemory.sch, TLE8888-1QK.sch, TLE9201SG.sch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]
2020-02-13 Added solder-able mounting points M1 to M4.
    [FlashMemory.sch, TLE8888-1QK.sch, TLE9201SG.sch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]
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2020-02-13 Flipped JP1 to short VDDA to Vref.
    [microRusEfi.kicad_pcb, stm32.sch]
2020-02-13 Updated JP2 removing default bridge. https://github.com/rusefi/hw_microRusEfi/issues/126
    [hi-lo.sch, microRusEfi.kicad_pcb]
2020-02-13 Moved D43 silk screen, which was covered by R10. D43 is now visible.
    [microRusEfi.kicad_pcb]
2020-02-13 Added SW3 to allow for smaller and larger footprints for this push button. https://github.com/rusefi/hw_microRusEfi/issues/125
    [microRusEfi.kicad_pcb, stm32.sch]
2020-02-15 Updated silk to indicate 0.4.8
    [microRusEfi.kicad_pcb]
2020-02-15 fix rotation of U7 in 0.4.7 cpl file (#128)
    [rusEFI-Micro_R0.4.7-cpl.csv]
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2020-02-16 Moved R9 and C12 to the front https://github.com/rusefi/hw_microRusEfi/issues/129
    [microRusEfi.kicad_pcb]
2020-02-16 Added silk screen note to describe LED D35's function. https://github.com/rusefi/hw_microRusEfi/issues/130
    [microRusEfi.kicad_pcb]
2020-02-16 Silk screen updates https://github.com/rusefi/hw_microRusEfi/issues/131
    [microRusEfi.kicad_pcb]
2020-02-27 preparing for incremental approach
    [rusEFI-Micro_R0.4.8-bom.csv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]
2020-02-27 ETB part number should be C112633? #133
    [TLE9201SG.sch, rusEFI-Micro_R0.4.8-bom.csv]
2020-02-27 version label on the back
    [microRusEfi.kicad_pcb]
2020-02-27 Replace VR silk with Hall #132
    [microRusEfi.kicad_pcb]
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2020-02-27 MRE 4.8.0 moved component list
    [rusEFI-Micro_R0.4.8-cpl.csv]
2020-02-28 putting labels on the back
    [microRusEfi.kicad_pcb]
2020-02-28 changing VR to Hall & refill #132
    [microRusEfi.kicad_pcb]
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2020-02-29 R0.4.8 Changed to MRE connector lib.
    [TLE9201SG.sch, microRusEfi.kicad_pcb, microRusEfi.sch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]
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2020-03-01 maybe C2 as well?
    [rusEFI-Micro_R0.4.8-bom.csv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]
2020-03-02 Matt says IRLR2905TRPBF probably fine for Q1
    [rusEFI-Micro_R0.4.8-bom.csv]
2020-03-03 0.4.8 JLCPCB DFM Report #139
    [rusEFI-Micro_R0.4.8-cpl.csv]
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2020-03-13 front silk step 1
    [microRusEfi.kicad_pcb]
2020-03-14 Updated silk / footprint module
    [microRusEfi.kicad_pcb]
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2020-03-19 0.4.8 LS1 silk should say LS2 fix #143
    [microRusEfi.kicad_pcb]
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2020-03-22 removed extra diodes https://github.com/rusefi/hw_microRusEfi/issues/134
    [adc.sch, microRusEfi.kicad_pcb]
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2020-03-25 Remove all back side BAS70-04 #134
    [microRusEfi.csv, microRusEfi_by-ref.csv, rusEFI-Micro_R0.4.5-bom.csv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]
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2020-03-27 Removed JP1 https://github.com/rusefi/hw_microRusEfi/issues/127
    [adc.sch, microRusEfi.kicad_pcb, microRusEfi.sch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]
2020-03-27 Added op-amp pull down on un-used op-amp. https://github.com/rusefi/hw_microRusEfi/issues/127
    [adc.sch, microRusEfi.kicad_pcb, microRusEfi.sch]
2020-03-28 Added 4X low sides now 4 channels are either low side or analog.
    [FlashMemory.sch, TLE8888-1QK.sch, TLE9201SG.sch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]
2020-03-28 Added extra output channels, also added via's for unused STM32 pins, useful for PNP adapter boards. https://github.com/rusefi/hw_microRusEfi/issues/144
    [microRusEfi.kicad_pcb, microRusEfi.sch]
2020-03-28 Added more thermal via's near Q1
    [microRusEfi.kicad_pcb]
2020-04-02 Helped GND path near U10
    [microRusEfi.kicad_pcb, microRusEfi.sch]
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2020-04-04 starting with 0.4.8 files
    [rusEFI-Micro_R0.4.9-bom.csv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]
2020-04-06 Ground plane clean-up (#148)
    * Add pair.sch (move to libs?)
    * Some trace clean-up, extend ground plane on bottom
    [microRusEfi.kicad_pcb, pair.sch]
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2020-04-07 D2,D42,D43 position & orientation
    [rusEFI-Micro_R0.4.8-cpl.csv, rusEFI-Micro_R0.4.9-cpl.csv]
2020-04-08 Cleanup (#152)
    * pair.sch: adjust to be inline with what on PCB
    * PCB cleanup:
    - C47, C46, C16, C45 removed from PCB (do not exist at schematic)
    - Minor silk fixes
    - minor traces clean-up
    [microRusEfi.kicad_pcb, pair.sch]
2020-04-08 Return of magic capacitors (#153)
    [microRusEfi.kicad_pcb, pair.sch]
2020-04-09 safest part of the placement change
    [rusEFI-Micro_R0.4.9-cpl.csv]
2020-04-23 Outputs througth tle (#155)
    * correct pair.sch
    * more progress
    * Progress:
    -additional OD ouputs are driven through TLE8888 (with diagnostic)
    -TLE8888 ignition outputs routed to connector (through 0R jumpers on bottom)
    -Hall sensor is now powered from protected 5V1
    -TLE8888 DFB to AV9 connection removed
    * Clean-up gnd areas
    * progress
    * Correct 3D models for U9, U10
    * More progress:
    -USB can be powered from AV4
    -TLE8888 INJ_EN and IGN_EN routed to STM32 PD11 and PD10
    -TLE8888 RST and STM32 NRST connected through 0R jumper
    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
    [FlashMemory.sch, TLE8888-1QK.sch, TLE9201SG.sch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]
2020-04-23 Small cleanup changes to silk and schematic.
    [TLE8888-1QK.sch, adc.sch, microRusEfi.kicad_pcb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]
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2020-04-27 Added via's for J2, Added QR code, Changed rusEFI logo.
    https://github.com/rusefi/hw_microRusEfi/issues/156
    [microRusEfi.kicad_pcb, microRusEfi.sch, stm32.sch]
2020-04-27 Changed file names to be micro_rusEFI instead of microRusEfi
    [micro_rusEFI.csv, micro_rusEFI.kicad_pcb, micro_rusEFI.sch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]
2020-04-27 reverted file names, to prevent broken URL's. Archived a bunch of extra files.
    [rusEFI-Micro_R0.4.5-bom.csv, rusEFI-Micro_R0.4.7-bom.csv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]
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2020-05-02 changed 10nF array to 100nF 0402, also moved to front 470k weak pull downs on front and under connector
    [adc.sch, micro_rusEFI.kicad_pcb]
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2020-05-14 Updated https://github.com/rusefi/hw_microRusEfi/issues/163
    [zMRETestFixture.kicad_pcb, zMRETestFixture.sch]
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2020-05-14 Cleaned up folder, changed script to use more clear file name
    [MRE_JLC_POS_Modificaton.xlsx, rusEFI-Micro_generic_by-ref.csv, rusEFI-Micro_generic_grouped.csv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]
2020-05-18 Added water resistant USB bulk head J19 connector https://github.com/rusefi/hw_microRusEfi/issues/165
    [micro_rusEFI.kicad_pcb, stm32.sch]
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2020-05-18 Generated draft 0.5.1 BOM, added some clarity to some BOM items. https://github.com/rusefi/hw_microRusEfi/issues/167
    [TLE8888-1QK.sch, adc.sch, hi-lo.sch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]
2020-05-18 BOM corrections #167
    [rusEFI-micro_R0.5.0_JLC_BOM.csv]
2020-05-18 changed U6 description per the below https://github.com/rusefi/hw_microRusEfi/issues/169
    [FlashMemory.sch]
2020-05-18 Updated the MFG information for U7 per https://github.com/rusefi/hw_microRusEfi/issues/170
    [micro_rusEFI.sch]
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2020-05-22 Added many short green trace stubs, which allow for the highlight net tool to grab a net.
    [FlashMemory.sch, TLE8888-1QK.sch, TLE9201SG.sch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]
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2020-06-07 Draft panel stuff. MFG files perhaps generated for the first time.
    [micro_rusEFI_JLC_BOM.csv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]
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2020-06-07 Removed 1x3 MFG files, added 3x3 with only 1 and 5 populated.
    [micro_rusEFI_JLC_BOM.csv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]
2020-06-08 AV6, AV8, AV9 and AV10 can now direct drive the digital outputs.
    [TLE8888-1QK.sch, adc.sch, micro_rusEFI.kicad_pcb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]
2020-06-08 Added holes to inspect the plastic per https://github.com/rusefi/hw_microRusEfi/issues/166
    [micro_rusEFI.kicad_pcb]
2020-06-08 Made VR resistors R9 and R15 DNP per https://github.com/rusefi/hw_microRusEfi/issues/171
    [TLE8888-1QK.sch, pair.sch]
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2020-06-29 Many silk issues, fixed both front and back side. Added revision silk to front side per the below, https://github.com/rusefi/hw_microRusEfi/issues/181
    Panel still needs to be updated to R0.5.2
    [micro_rusEFI.kicad_pcb, micro_rusEFI.sch]
2020-07-06 R0.5.2 drafted per https://github.com/rusefi/hw_microRusEfi/issues/180
    [TLE8888-1QK.sch, micro_rusEFI.kicad_pcb, micro_rusEFI.sch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]
2020-07-07 Changed USB per https://github.com/rusefi/hw_microRusEfi/issues/165
    [micro_rusEFI.kicad_pcb, stm32.sch]
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2020-07-07 R0.5.2 MFG files released per https://github.com/rusefi/hw_microRusEfi/issues/180
    [micro_rusEFI-top-pos.csv, micro_rusEFI_JLC-CPL_R0.5.2.csv]
2020-07-08 Fixed flipped J2 per https://github.com/rusefi/hw_microRusEfi/issues/179
    [zMRETestFixture.kicad_pcb, zMRETestFixture.sch]
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2020-07-12 J6 is now J12 J8 is now J13 Updated MRE footprint to include UART via's.
    [micro_rusEFI.kicad_pcb, micro_rusEFI.sch]
2020-07-12 Changed microRusEfi to microRusEFI per https://github.com/rusefi/hw_microRusEfi/issues/182
    [FlashMemory.sch, TLE8888-1QK.sch, TLE9201SG.sch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]
2020-07-15 Draft 0.5.2 corrected BOM 2.7k from 0603 to 0402
    [FlashMemory.sch, TLE8888-1QK.sch, TLE9201SG.sch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]
2020-07-22 Updated BOM's per https://github.com/rusefi/hw_microRusEfi/issues/184
    [adc.sch, microRusEFI_R0.5.1_JLC_BOM.csv, micro_rusEFI_JLC_BOM.csv]
2020-07-22 Updated R2 in schematic. Looks like there is still a BOM creation issue. Per https://github.com/rusefi/hw_microRusEfi/issues/175
    [micro_rusEFI.sch]
2020-07-22 Manually removed R2, KC seems to have a bug. Removed per https://github.com/rusefi/hw_microRusEfi/issues/175
    [micro_rusEFI_JLC_BOM.csv]
2020-07-26 [0.5.2] D41 orientation seems wrong in #183
    [micro_rusEFI_JLC-CPL_R0.5.2.csv]
2020-07-27 Changed field name for long term DNP of R2 per https://github.com/rusefi/hw_microRusEfi/issues/175
    [micro_rusEFI.sch, micro_rusEFI_JLC_BOM.csv]
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2020-07-28 Cleanup traces (#189)
    * first run
    * second pass
    * third pass
    [micro_rusEFI.kicad_pcb]
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2020-08-03 Bumped silk to to R0.2 and changed CRANK per https://github.com/rusefi/hw_microRusEfi/issues/177
    [zMRETestFixture.kicad_pcb, zMRETestFixture.sch]
2020-08-03 Updated footprint per https://github.com/rusefi/hw_microRusEfi/issues/188
    [zMRETestFixture.kicad_pcb]
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2020-08-08 To many extended parts, switch 2.7k back to basic part, moved pads around to accommodate per https://github.com/rusefi/hw_microRusEfi/issues/184
    [adc.sch, micro_rusEFI.kicad_pcb, micro_rusEFI_R0.5.3_JLC_BOM.csv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]
2020-08-08 Updated rotations for D41 per https://github.com/rusefi/hw_microRusEfi/issues/183
    [micro_rusEFI_R0.5.3_JLC_CPL.csv]
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2020-08-11 0.2 test fixture order
    [zMRETestFixture_R0.2_JLC_BOM.2020aug10.csv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]
2020-09-03 new ant logo, fixed version on backside
    [micro_rusEFI.kicad_pcb]
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2020-09-16 fixed connector 3d (#199)
    [micro_rusEFI.kicad_pcb]
2020-09-19 Typo fixes (#200)
    * fixed connector 3d
    * fixed some readme typos
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2022-04-09 Small pcb fix
    [micro_rusEFI.kicad_sch]
2022-04-10 PR for compatibility test (KiCAD6) (#221)
    * rtc batt pad change
    * rtc batt pad change
    * localization fix
    hand edited
    [micro_rusEFI.kicad_pcb]
2022-04-10 USB B mini fix
    [TLE8888-1QK.kicad_sch, micro_rusEFI.csv, micro_rusEFI.kicad_pcb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]
2022-04-10 D14 LED fix
    [TLE8888-1QK.kicad_sch, micro_rusEFI.csv, micro_rusEFI.kicad_pcb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]
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2023-07-26 Unable to program red boards fix #232
    [micro_rusEFI.2023-06-xx.csv]
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
